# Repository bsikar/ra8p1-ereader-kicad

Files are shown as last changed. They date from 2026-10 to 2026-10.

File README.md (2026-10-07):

# RA8P1 e-reader electronics

Open `ereader/ereader_rev1.kicad_pro` in KiCad 10.0.5 or a compatible newer
version. The project includes its schematic, board, project configuration,
project-local library tables, symbols, footprints, and STEP models. Library
paths resolve relative to the project; standard `Device` and `power` symbols
use the bundled KiCad 10 libraries through `${KICAD10_SYMBOL_DIR}`. No custom
global library installation is needed.

The schematic has a root index and separate processor interface, core-power,
I/O-supply, and clock/reset/debug sheets. The power circuits are drafts with passive qualification
still open; the processor interfaces and remaining subsystems are unfinished.
The PCB is empty.
Neither is a manufacturing release. Imported component models still require
electrical and package qualification before use in a finished design.

## Clone and open

Install Git LFS before cloning, or run `git lfs pull` after cloning. The large
manufacturer reference-design ZIP uses LFS. The editable KiCad project and
component libraries are ordinary Git files. Manufacturer reference files retain
their original notices and are reference material, not this board's design.

Open the project from its checked-out location. Do not add absolute model paths
or depend on a user's global symbol/footprint tables. KiCad lock files, personal
view settings, and editor history are excluded from commits.

## Review and export

`exports/ereader_rev1.pdf` contains every schematic sheet and is refreshed for
each design commit. It represents the design at that commit, including any
explicitly incomplete sections. It is not a fabrication drawing of the PCB.

From the repository root, regenerate it with:

```sh
./scripts/export_design.sh
```

The script also works when called by absolute path from another directory.
It finds `kicad-cli` on PATH or in the standard macOS KiCad app bundle. Set
`KICAD_CLI` to select another executable. An optional schematic path exports
that project's complete hierarchy to `exports/<schematic-name>.pdf`.

The script exports saved files, including all child sheets, and replaces the
previous PDF only after KiCad succeeds and produces a nonempty PDF. It does
not save unsaved editor changes. `--help` shows the available arguments.

Before each commit, save all sheets, export the complete PDF, inspect every
page, and run ERC. During circuit development, record unresolved findings;
do not hide unconnected pins merely to obtain a clean report. Before pushing,
run `python scripts/check_clock_calculations.py`, review the relevant
calculation checks in `design/`, and run `git diff --check`. Follow
`.agents/AGENTS.md` and `LIBRARY_STANDARDS.md`; the former firmware checkout's
parent-relative `CLAUDE.md` is not present in this standalone repository.

## Design references

- [Hardware requirements](design/ereader_requirements.md)
- [Library conventions](LIBRARY_STANDARDS.md)
- [Imported parts inventory](PARTS-CHECKLIST.md)
- [Hardware epic and section issues in YouTrack](https://youtrack.locked.cv/issue/RA8HW-1)

Use YouTrack for current hardware tasks, dependencies, status and review
evidence. The owner migrated and closed the GitHub issues; older issue links
in design records are historical provenance. GitHub remains the Git remote.

The Gaggia controller is a separate future board. Shared components belong in
the functional libraries under `libs/`; board-specific sheets belong in their
own project directory.

## Related repositories

This board is a separate product that uses the same Renesas RA8 part as the
firmware monorepo, so the electronics live here and the software stays there.
Both are wired in as submodules for context:

- `firmware/` -- [bsikar/ra8-firmware](https://github.com/bsikar/ra8-firmware),
  the RA8 firmware monorepo this project was split out of.
- `emulator/` -- [bsikar/ra8-emulator](https://github.com/bsikar/ra8-emulator),
  the host-side RA8 emulator used for EIL runs.

Clone with `git clone --recurse-submodules`, or run
`git submodule update --init --depth 1` in an existing clone. Both submodules
are registered shallow; nothing in this repository builds against them.

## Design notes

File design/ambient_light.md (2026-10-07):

# Ambient-light integration

## ALS-001: native symbol checkpoint, 2026-10-04

Created `Sensors:OPT4001DTSR` through the native Symbol Editor. This initial
symbol-only checkpoint preceded the native circuit integration below.
The existing LIS2DTW12TR orientation circuit is unchanged.
Authority: [TI SBOS993A Rev A, Table 6-2](https://www.ti.com/lit/ds/symlink/opt4001.pdf).

| DTS pin | Name | Electrical type |
| --- | --- | --- |
| 1 | VDD | Power input |
| 2 | ADDR | Input |
| 3 | NC | Unconnected |
| 4 | GND | Power input |
| 5 | SCL | Input |
| 6 | NC | Unconnected |
| 7 | INT | Bidirectional |
| 8 | SDA | Bidirectional |

The eight-pin DTS ordering code is distinct from the four-pin YMN variant.
Pin 7 supports open-drain output and hardware-trigger input. Proposed polling
keeps INT_DIR=1 and a 10k pullup, without allocating another MCU interrupt.
Proposed ADDR-to-ground selects 0x44; local bypass is 100nF.
These are integration decisions pending native wiring and validation.

[DigiKey](https://www.digikey.com/en/products/detail/texas-instruments/OPT4001DTSR/17748298)
showed 346 available in cut tape, USD1.68 at quantity one, unreserved.
Native hidden fields record the exact manufacturer and supplier codes.

Next: connect the common +3V3_MCU rail and IIC0_A bus; reuse the existing
4.7k pullups only after revising the bus inventory. The prior 60pF allocation
is not permission to add sensor capacitance. Bound leakage, edge timing,
startup and shutdown backfeed before acceptance. A 100uA supply planning
allowance is a design reserve, not a guaranteed datasheet maximum.

Use a sealed optical window and isolate the sensor optically from the
frontlight and both camera lights. Window transmission, angular response,
condensation and calibration remain enclosure-dependent qualification work.
No footprint, model, PCB or production acceptance is included.

## ALS-002/003: native integration checkpoint, 2026-10-04

Placed and wired U32 through KiCad. VDD pin 1 uses +3V3_MCU; ADDR pin 2
and GND pin 4 use GND. SCL pin 5 and SDA pin 8 join /SENS_SCL and /SENS_SDA,
respectively, retaining host balls K13 and R16 and the existing R102/R103
4.7k pullups. NC pins 3 and 6 remain unconnected per the device pin map.
No second bus pullup pair was added.

R112 is a 10k YAGEO RC0603FR-0710KL pullup from INT pin 7 to +3V3_MCU.
It follows Table 6-2; polling requires INT_DIR=1, including after register
configuration. No MCU interrupt is allocated. C124 is the 100nF local
VDD-to-GND bypass recommended in section 9.4, with sourced candidate
Murata GRM188R72A104KA35D. Passive source snapshots are inherited dated,
unreserved evidence; recheck before ordering. Effective capacitance,
leakage, temperature, aging and physical placement remain unqualified.

Read-only KiCad XML audit found 299 components. All 296 previous complete
component records and their pin-to-net memberships were preserved against
the service-discharge checkpoint. The three additions are U32, C124 and
R112. Native ERC remains 100 errors and 11 warnings; this is a WIP result,
not electrical acceptance or a clean ERC claim.

### Expanded shared-bus allocation fails the existing Fast-mode screen

`scripts/check_ambient_light.py` audits the exported topology and reproduces
the following conditional arithmetic. These are engineering allocations,
not measured or guaranteed installed limits:

- Existing 60pF ceiling plus provisional 10pF sensor/route reserve = 70pF.
  TI's 3pF typical pin capacitance is not a guaranteed maximum.
- Existing 15uA leakage allocation plus provisional 2uA reserve = 17uA.
  This is not a full-temperature OPT4001 leakage guarantee.
- Existing R102/R103 envelope: 4376.147..5034.194 ohm, including allocated
  tolerance, temperature and service drift; rail 3.151819680..3.393012496V.
- Worst allocated rise: 318.072781ns, failing the 300ns ceiling. At 17uA,
  the corresponding capacitance ceiling is 66.022625pF.
- With 1.3us low, 0.6us high and 300ns allocated fall, 400kHz period slack
  is -18.072781ns. Bus divider/filter settings are not accepted.
- Conditional static high floor is 3.066238391V and sink ceiling is
  0.792343mA. R112's hypothetical INT-low draw is 0.346190mA and resistor
  dissipation is 1.174628mW using 1% tolerance plus 1% temperature reserve.

Next: revise the complete bus capacitance/leakage inventory and pullup/timing
choice, then qualify host and both sensor thresholds, edges, startup,
shutdown/backfeed and power-cycle behavior together. The added device does
not inherit the prior 60pF approval. The 100uA ALS supply planning reserve
also does not establish maximum supply current or aggregate rail capacity.

## ALS-004: complete saved-bus inventory and pullup comparison, 2026-10-04

The read-only exported netlist contains exactly four contacts on each line:
SCL = R102.2, U1.K13, U26.1 and U32.5; SDA = R103.2, U1.R16,
U26.4 and U32.8. Both pullups return to +3V3_MCU. U26 is the approved
LIS2DTW12TR. The audit now asserts these complete contact sets, the retained
4.7k values and the replacement part number. Adding another bus load will
require revising this inventory and the conditional allocation.

Compared lower nominal pullups using the same 1% initial, 1% temperature
and 5% service-drift allocations. Slow edges use 70pF, 17uA leakage sinking
and the minimum rail; fast edges use 25pF, 17uA injection and the maximum
rail. These allocations remain unqualified. The timing screen follows
[RA8P1 Rev.1.30 Table 2.66](https://www.renesas.com/en/document/dst/ra8p1-group-datasheet)
and [OPT4001 SBOS993A](https://www.ti.com/lit/ds/symlink/opt4001.pdf).

| Uninstalled nominal pullup | Conditional rise range | Sink ceiling | 400kHz period slack |
| --- | --- | --- | --- |
| 3.9k | 73.904..261.023ns | 0.951387mA | 38.977ns |
| 3.3k | 62.912..219.056ns | 1.121276mA | 80.944ns |
| 2.7k | 51.788..177.773ns | 1.366670mA | 122.227ns |
| 2.2k | 42.413..143.880ns | 1.673414mA | 156.120ns |

3.3k is the next candidate for sourcing and native installation: it provides
more conditional margin than 3.9k while retaining lower sink current than
2.7k or 2.2k. No pullup was changed in this checkpoint. The table is a
lumped planning comparison, not permission to operate the current circuit
at 400kHz. Divider/filter settings, fall time, full-temperature device limits,
actual board capacitance, supply sequencing and future bus loads still need
qualification. Preserve the failed installed 4.7k screen until native
replacement and its saved-netlist verification are complete.

## ALS-005: native 3.3k shared-bus pullups, 2026-10-04

Changed R102/R103 in native KiCad to YAGEO RC0603FR-073K3L, 3.3k,
1%, +/-100ppm/C, 0603, 0.1W at 70C, -55..155C. The
[manufacturer ordering-code sheet](https://yageogroup.com/component-documentation/download/specsheet/RC0603FR-073K3L)
confirms these ratings. Native fields include the exact MPN, manufacturer
document, supplier code/URL, selection basis and dated availability snapshot.
[DigiKey](https://www.digikey.com/en/products/detail/yageo/RC0603FR-073K3L/730073)
showed Active status, 622,536 unreserved in stock, cut-tape code
311-3.30KHRCT-ND, USD0.10 qty1 / 0.01220 qty100 and a 22-week
manufacturer lead time. Recheck before ordering. Footprints remain deferred.

Under the ALS-004 allocations, the installed pair has a resistance envelope
of 3072.6135..3534.6465 ohm. Conditional rise is 62.912..219.056ns,
sink ceiling 1.121276mA, and the minimum-pulse 400kHz period screen has
80.944ns slack. This closes the failed *planning calculation* for the
previous 4.7k pair; it does not qualify operation at 400kHz. The script
retains that historical 318.072781ns failure separately.

The complete saved bus inventory remains the exact ALS-004 contact sets.
Read-only comparison against the 299-component ALS checkpoint permits
only R102/R103 value and source-metadata changes, preserving their other
identity fields, all 297 other complete component records and every contact
membership. The native circuit and both notes now show the installed values.
No new components or wires were added by this pullup checkpoint.

Remaining acceptance work: bound installed capacitance and leakage across
temperature and service conditions; verify RA8P1 IIC clock/divider/filter
timing and both sensors' edge/threshold limits; evaluate startup, supply
collapse, backfeed and recovery. OPT4001 optical-window transmission,
frontlight/camera-light isolation, condensation and calibration remain open.
The resistor environmental rating does not qualify enclosure water resistance.

Verification: both sensor calculation/topology scripts pass against the saved
XML; the native ERC findings are identical to ALS-003 (100 errors, 11 warnings).
The full 14-page PDF was refreshed: pages 1-13 are pixel-identical to the
preceding reviewed export, and page 14 was rendered and inspected for the
new values and notes. Native CLI BOM export retains the project-configured
19 columns and has 121 groups / 296 included references; TP1-TP3 remain
explicitly excluded copper testpoints. All included values, manufacturer
names/MPNs and DigiKey codes match the saved XML. Clock calculation checks
and `git diff --check` pass. This remains a WIP electrical design.

## ALS-006: host divider and recovery screen, 2026-10-04

Reviewed [RA8P1 HUM R01UH1064EJ0130 Rev1.30](https://www.renesas.com/en/document/mah/ra8p1-group-users-manual-hardware),
chapter 40. Pages 2384 and 2386 define IICphi = PCLKB / 2^CKS and
NF=01 as two filter stages. Page 2402 equation (5) applies with SCLE=1,
NFE=1 and nonzero CKS. BRH/BRL must each be at least nf+1; reserved
register bits 7:5 must be written as ones. Keep FMPE=0 for Fast-mode.

`scripts/check_sensor_iic_clock.py` screens a provisional PCLKB=50MHz
+/-1% allocation with CKS=001, NF=01, BRH=23 and BRL=31 (register
writes 0xF7 and 0xFF). These are candidate settings, not firmware changes
or an approved system clock configuration. The current crystal circuit
does not establish this PCLKB range. The script computes high/low pulse
minima and maximum rate with zero fall time as a conservative rate bound;
zero fall time is not an accepted electrical edge. It also demonstrates
why the manual's illustrative 400kbps tuple is not a corner-qualified
setting for this bus. Stretching can further reduce the transfer rate.

Recovery must respect sections 40.12.2-40.12.3, pages 2448-2449. CLO
outputs one extra SCL cycle per request and must clear before another
request. Use it only for lost synchronization, monitor SDAI, and issue
STOP after the slave releases SDA. CLO cannot recover a slave holding
SCL low. Both module reset forms release the MCU outputs; neither proves
that a sensor has reset or released its own output. Clear IICRST afterward.
The whole-bus power-cycle/discharge path remains an electrical dependency.

Still open: derive PCLKB and its tolerance from the complete PLL/clock
plan, verify sensor and host setup/hold plus START/STOP and bus-free timing,
select SDA delay from guaranteed limits, bound physical edges/leakage,
and qualify interrupted-transfer recovery. Do not mark ALS or U26 fully
qualified from this divider screen. No schematic, BOM or firmware changed
in ALS-006; the existing full PDF remains the current circuit view.

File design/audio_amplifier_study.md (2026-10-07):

# Audio Stage 3: headphone amplifier alternatives and qualification envelope

2026-10-04 research checkpoint. **No amplifier topology or part is selected.**
This is a feasibility/architecture study following
[Stage 1](audio_stage1_requirements.md), not a circuit qualification or a
continuous output rating. No schematic, library, BOM, footprint or PDF changes
are made by this document. Existing OPA1622/INA1620 ideas and U34/K1 are WIP.
Firmware implementation is out of scope; hardware must provide the interfaces,
independent protection and deterministic mode-transition contracts.

The meaningful shortlist is (1) a precision amplifier with multiple integrated
buffers inside its feedback loop, (2) a precision amplifier with a discrete
Class-AB output stage, and (3) separate low-power IEM and high-current desktop
paths. A high-current current-feedback IC is another serious desktop comparator.
Class A and local error correction deserve evaluation but are not automatically
better. Stage 6 must compare these with the converter, power and enclosure study
before any final CAD changes.

## Electrical envelope and actual headphone cases

Screen balanced desktop output at **16 Vrms maximum, 0.707 Apeak maximum and
4 W/channel continuous maximum**, with 2 W/32 as the minimum architecture
objective. These are simultaneous limits, not three independent product claims.
Use `V = min(16, R*0.70710678/sqrt(2), sqrt(4*R))` and then apply actual hot
output swing, SOA, protection and thermal limits. Both legs carry full load
current and each sees an effective load of R/2 in symmetric BTL operation.

| Load ohms | Available Vrms | W/channel | Apeak | Ideal stereo heat on fixed +/-14 V rails, W | Maximum ideal heat over allowed amplitude, W |
| ---: | ---: | ---: | ---: | ---: | ---: |
| 16 | 8.000 | 4.000 | 0.707 | 17.209 | 17.209 |
| 32 | 11.314 | 4.000 | 0.500 | 9.825 | 9.825 |
| 50 | 14.142 | 4.000 | 0.400 | 6.260 | 6.355 |
| 80 | 16.000 | 3.200 | 0.283 | 3.684 | 3.972 |
| 150 | 16.000 | 1.707 | 0.151 | 1.965 | 2.118 |
| 300 | 16.000 | 0.853 | 0.075 | 0.982 | 1.059 |
| 600 | 16.000 | 0.427 | 0.038 | 0.491 | 0.530 |

Heat uses ideal Class B, `Pdc/ch = 4*Vrail*Ipeak/pi`; output-stage stereo
heat is `2*(Pdc/ch-Pload/ch)`. Bias, converter loss, DAC, drivers, host/radio,
display and charging add heat. At 50 ohms and above, the dissipation maximum
occurs at 12.604 Vrms on +/-14 V, below the endpoint. A thermal test only at
clipping misses it. This table demonstrates that a fixed high-voltage rail is
an unattractive low-impedance operating mode, even when current capability is
ample. At the same 4 W/16, +/-8 V gives 6.405 W ideal stereo output-stage heat;
it is an illustrative lower-rail comparator, not proved 0.707 A hot swing.
For 16 Vrms BTL, each leg must swing 11.314 Vpeak. +/-14 V leaves 2.686 V
for stage/protection headroom before supply tolerance/droop. A device that
needs more headroom cannot meet it on these rails.

Lower-power IEM qualification extends to 8-9 ohms. Applying the desktop
current ceiling blindly to 9 ohms would produce 2.25 W/channel and 20.709 W
ideal stereo heat on +/-14 V: explicitly prohibit this in IEM mode. Rated
IEM voltage/current limits need independent hardware enforcement and must be
far below the high-power path. The 4 W cap also needs a real implementation:
an RMS/thermal limiter, load-aware voltage ceilings, or a conservatively rated
fixed envelope. Voltage and instantaneous current limits alone do not enforce
constant continuous power at every impedance.

Use equivalent sine peak-capacity screens of 100 dB, 105 dB, and 111 dB
(105 plus 6 dB EQ/sensitivity reserve), not recommended sustained listening
levels. Conversion from voltage sensitivity is `V=10^((L-Sv)/20)`; from
power sensitivity `P[mW]=10^((L-SmW)/10)`. Music crest factor, acoustic seal,
sample variation and frequency-dependent EQ prevent an SPL guarantee.

| Headphone and basis | 100 dB: Vrms / W | 105 dB: Vrms / W | 111 dB: Vrms / W / Apeak |
| --- | ---: | ---: | ---: |
| Original HE-6, velour pads, RAA conservative left-channel band average 89.0 dB/V, 43.3 ohms | 3.548 / 0.291 | 6.310 / 0.919 | 12.589 / 3.660 / 0.411 |
| Original Susvara, Stage 1 conservative measured screen 93.2 dB/V, 67.1 ohms | 2.188 / 0.0713 | 3.890 / 0.226 | 7.762 / 0.898 / 0.164 |
| HD800S, manufacturer 102 dB/V, 300 ohms | 0.794 / 0.00210 | 1.413 / 0.00665 | 2.818 / 0.0265 / 0.0133 |
| Original LCD-5, manufacturer 90 dB/mW, 14 ohms | 0.374 / 0.0100 | 0.665 / 0.0316 | 1.328 / 0.126 / 0.134 |
| SE846, manufacturer 114 dB/mW, 9 ohms | 0.0189 / 0.0000398 | 0.0337 / 0.000126 | 0.0672 / 0.000501 / 0.0106 |

The [original RAA HE-6 measurement](https://reference-audio-analyzer.pro/en/report/hp/hifiman-he-6.php)
identifies velour pads, HDM1/SF1 fixtures and channel-specific values. It is
**not HE6se or HE6se V2** and should not be relabeled as either. Using the less
sensitive channel is our conservative screen. The HE-6 case supports useful
margin beyond 8 Vrms: an 8 V ceiling misses the 111 dB reserve screen by about
3.94 dB. The 16 V /4 W envelope permits about 13.161 V at 43.3 ohms, providing
only about 0.39 dB beyond that reserve screen. It is broad coverage, not an
unlimited future-load promise. Additional EQ or low-frequency sensitivity
uncertainty can consume the reserve; qualification must use impedance curves
and frequency-specific measured sensitivity.

Other sources: [Susvara original RAA measurement](https://reference-audio-analyzer.pro/en/report/hp/hifiman-susvara.php),
[HD800S manufacturer specification](https://support.sennheiser-hearing.com/hc/en-us/articles/38273432554141-HD-800S-Specifications),
[LCD-5 manufacturer](https://www.audeze.com/products/lcd-5),
[SE846 manufacturer](https://www.shure.com/ja-jp/insights/all-about-se846-gen2-a-more-sophisticated-listening-experience).
Susvara/HD800S/SE846 inputs preserve Stage 1 provenance; this pass adds the
HE-6 measurement and original LCD-5 example. The LCD-5 source now describes
that model as legacy; future LCD variants must not inherit its electrical
specification. Electrostatic energizers and unusual near-zero-ohm ribbons
remain outside this conventional voltage-output headphone design.

## Serious amplifier comparators

Values below are manufacturer data under their stated conditions, not
complete-device measurements. A typical current, short-circuit rating, or
25 C waveform must never be treated as guaranteed low-distortion hot current.

| Candidate / function | Relevant source data | Fit and unresolved limits |
| --- | --- | --- |
| OPA1622 integrated audio driver | +/-2 to +/-18 V; 2.6 mA/core typical; 2.8 nV/sqrtHz at 1 kHz; +145/-130 mA typical drive/short-current scale; shutdown with reduced transients. | Strong low-power/IEM comparator, current alone inadequate for desktop. Input/feedback noise and hot swing still matter. |
| INA1620 integrated audio driver/resistor network | Same supply range and 2.6 mA/core typical; table labels +145/-130 mA **short-circuit** current. Matched resistors/EMI filtering add utility, not output watts. | Rail rating is not the blocker. Bare output paralleling is unacceptable; offset, sharing, stability and thermal limits require design. |
| OPA1656 + BUF634A composite | Actual manufacturer headphone reference; BUF634A +/-2.25 to +/-18 V, +/-250 mA continuous parameter; 1.5/8.5 mA typical low/wide-bandwidth bias. | Real scalable comparator; one buffer/leg cannot supply 0.354/0.5/0.707 Apeak. Parallel buffers and compensation must be proven. |
| Precision amplifier + LME49600 | Manufacturer closed-loop reference; 250 mA typical, 7.3/13.2 mA bias; +/-18 V ceiling. | Similar current-scaling issue and larger TO-263 footprint; higher idle burden than BUF634A comparator. |
| Precision amplifier + LMH6321 | 300 mA continuous subject to heat, programmable limit 10-300 mA, 11 mA typical bias, operating ceiling +/-16 V. | Useful current-limited composite comparator; needs multiple buffers for desktop. At +/-15 V, 300 mA sinking swing is only -10.3 V minimum at 25 C/-9.8 V hot, insufficient alone for 11.314 Vpeak per leg. |
| TPA6120A2 integrated current-feedback AB | +/-5 to +/-15 V recommended; 700 mA typical; 16 ohm recommended minimum load; 15 mA/core at +/-15 V; 10-100 ohm output resistor recommended. | Native reference conflicts with low output impedance. In BTL, 16 ohm headphones impose 8 ohm per leg, below recommended load. Needs new compensated implementation, thermal and noise evidence. |
| Precision amplifier + ADA4870 high-current CFB | 10-40 V supply, 1 A typical drive, 32.5 mA typical bias at +/-20 V; manufacturer composite example with ADA4637-1. | Serious desktop option with useful SOA documentation. Large idle burden, high input current noise, offset and loop compensation preclude adopting it as an IEM driver from its spot voltage-noise number. |
| OPA564 power amplifier/composite candidate | 7-24 V supply, 1.5 A, 39 mA typical bias; 102.8 nV/sqrtHz at 1 kHz; adjustable limit and thermal flag. | Direct IEM use is poor; +/-12 V ceiling gives too little guaranteed headroom for 16 Vrms BTL. A precision outer loop adds work and heat; not a leading portable comparator. |
| Precision amplifier + discrete AB emitter/source followers | Bias, transistor area and heatsinking can be chosen independently of signal gain. | Serious flexible option; must establish bias tracking, hot DC/pulsed SOA, second breakdown for BJTs, MOSFET linear-mode suitability, loop stability and manufacturing variation. More parts are justified only by measured envelope/energy benefit. |

Sources: [OPA1622 Rev B](https://www.ti.com/lit/ds/symlink/opa1622.pdf),
[INA1620 Rev B](https://www.ti.com/lit/ds/symlink/ina1620.pdf),
[OPA1656 composite, section 8.2.2](https://www.ti.com/lit/ds/symlink/opa1656.pdf),
[BUF634A Rev F](https://www.ti.com/lit/ds/symlink/buf634a.pdf),
[LME49600 Rev E](https://www.ti.com/lit/ds/symlink/lme49600.pdf),
[LMH6321 Rev D](https://www.ti.com/lit/ds/symlink/lmh6321.pdf),
[TPA6120A2 Rev B](https://www.ti.com/lit/ds/symlink/tpa6120a2.pdf),
[ADA4870 Rev C](https://www.analog.com/media/en/technical-documentation/data-sheets/ada4870.pdf),
[OPA564 Rev E](https://www.ti.com/lit/ds/symlink/opa564.pdf).

At an optimistic 130 mApeak per leg, a BTL OPA1622/INA1620 channel has only
`Ipeak^2*32/2 = 0.270 W/32`. Even this is a calculation using typical limiter
scale, not a linear rating. Raising its rails does not solve current limits.
An illustrative six cores/leg would have 24 cores and substantial sharing,
noise, power and failure complexity. This is not a recommended six-core design.

The BUF634A composite reference uses the buffer in the OPA165x feedback loop;
wide-bandwidth mode is the reference condition for uncomplicated stability.
Changing to low-bias mode, adding buffers or switching gain invalidates an
assumption that that single-buffer reference proves our loop. Three buffers
per leg share 0.707 A as 0.236 A each ideally, leaving little sharing margin.
Twelve wide-mode buffers plus four OPA1656 cores on +/-14 V consume an
illustrative 3.293 W idle using typical currents, before the DAC. Low-bias
operation and/or power-gating a separate desktop bank therefore deserve
explicit comparison; no low-bias loop is qualified here. The
[BUF634A EVM schematics](https://www.ti.com/lit/pdf/SBOU256) provide a test
starting point, not a production solution; their default 50-ohm termination
must not be copied as a headphone source impedance.

Current-sharing ballast resistors, individual offsets and gain error must
be modeled. Never connect independently controlled outputs together simply
because they have the same nominal gain. A common precision loop around a
buffer bank with local ballast is distinct from independent amplifiers
fighting at a common output node. The summed current limit does not protect
one overloaded buffer if sharing is unequal or one device loses a rail.

Current-feedback describes an internal feedback topology, not a mandate to
drive headphones from a high-impedance current source. A conventional voltage
output with low impedance remains the required interface. The TPA6120A2
reference imposes specific feedback-resistor/stability constraints; reducing
its output resistor to meet our impedance budget needs simulation and bench
evidence. Its typical 0.9 uVrms output-noise headline is not a measured
20 Hz-20 kHz two-leg noise budget for our design.

ADA4870 supplies a precision-composite reference and SOA curves for a particular
board/heatsink at 25/85 C. Neither 1 A nor its 2.1 nV/sqrtHz voltage noise
at 100 kHz is a complete audio-band result. Four devices at +/-14 V using
32.5 mA as an illustrative bias consume 3.64 W idle; actual bias at those rails
needs measurement. Its inverting-input current noise and feedback resistors
matter. OPA564's guaranteed current/headroom, limiter overshoot and hot-current
derating also need examination if reconsidered; thermal shutdown is not an
acceptable normal operating cycle.

For discrete AB, [LT1166 manufacturer bias-system circuits](https://www.analog.com/media/en/technical-documentation/data-sheets/1166fa.pdf)
are one reproducible comparator: sense resistors set bias and current limit,
while an explicit compensated local loop controls external devices. This
does not establish IEM noise or eliminate hot SOA checks. Small sense resistors
reduce impedance but make current-limit/bias accuracy and layout important.
Generic switching MOSFET drain-current ratings do not establish linear SOA.
No output transistor has been selected.

Class A can avoid a crossover transition in its valid load/bias region; this
does not guarantee less total audible distortion than well-designed AB. The
Stage 1 illustrative four-leg 0.25 A bias on +/-10 V is 20 W idle, incompatible
with our portable energy allocation. Lower bias reduces the Class-A envelope.
Reject continuous high-power Class A as the default portable path unless a
quantified benefit outweighs that burden; an AB stage may remain Class A for
small signals without paying full-load Class-A idle power.

Implementable local error correction is a serious option.
[Cordell's original AES paper and circuit](https://www.cordellaudio.com/papers/MOSFET_Power_Amp.pdf)
demonstrate corrected output-stage distortion in a 50 W speaker amplifier.
The paper does not qualify a modern low-voltage headphone circuit. Its local
error/bias loop and main feedback loop require compensation, clipping recovery,
noise and hot stability analysis after rescaling. Composite global feedback
is another real way to reduce output-stage errors. Do not equate either with
a licensed THX design. [THX's primary description](https://www.thx.com/aaa)
identifies proprietary patented feed-forward technology; it provides no
qualified custom-board schematic in this study.
[Questyle's technology page](https://www.questyle.com/pages/technology)
is product/technology context, not a reproducible output-stage reference.
Neither brand proves an audible benefit over a transparent tested AB circuit.

## Noise, gain, volume, balanced and single-ended interfaces

The Stage 1 <=1 uVrms unweighted 20 Hz-20 kHz jack-noise objective corresponds
to 94 dB SNR at 50 mVrms; 0.5 uV gives 100 dB. Include DAC, I/V/filter,
attenuator, resistor Johnson noise, amplifier voltage/current noise, supplies,
switch leakage and RF demodulation. Measure active digital zeros, mute,
USB+PD+charging and Wi-Fi activity separately. A-weighted and unloaded SINAD
cannot substitute for this loaded low-level measurement.

Our flat-noise approximation with 2.8 nV/sqrtHz and two independent BTL legs
gives 0.560 uVrms at noise gain 1, 1.119 uV at 2 and 2.239 uV at 4, before
all other stages and 1/f noise. These are calculations, not device noise
guarantees. High gain can fail the IEM noise budget even with an excellent
amplifier. An inverting unity-signal-gain leg has noise gain 2; two unity-gain
voltage followers fed from a differential source have a different noise
budget. Do not sum all upstream noise as independent: some is correlated
between legs, and actual differential transfer determines cancellation.

Retain these candidates through Stage 6:

1. One scalable output stage, low/medium/high closed-loop gain and lower rails
   on battery; power-gated extra buffers in desktop mode. Advantage: fewer
   connector-routing stages. Risks: gain/buffer switches, compensation changes,
   leakage into disabled outputs, hot current sharing and high idle noise.
2. Optimized IEM stage plus separate high-power AB/composite path, both routed
   through qualified default-open disconnects. Advantage: high-current stage
   can be fully off for IEM listening. Risks: board area, selection contact
   resistance, charge injection, pop behavior and cross-path fault backfeed.
3. Shared precision front end, dedicated SE and four-leg balanced power stages,
   with explicit power-gating and independent protection. Advantage: both jack
   interfaces can have independent useful capability. Risks: greatest area and
   supply/control complexity; do not assume simultaneous outputs.

Use coarse analog gain/attenuation plus fine digital volume as a comparator.
An analog attenuator before the final amplifier reduces upstream noise but
does not reduce that amplifier's own noise. Large output-divider resistors
raise source impedance and make response dependent on IEM impedance. A
mechanical potentiometer's low-end matching is not assumed. Relay/resistor or
IC volume must prove <=0.1 dB channel error at 1-50 mV, transitions and contact
aging. Fail-open/stuck control states must not enable maximum gain.

A differential converter can feed a differential chain, but the SE interface
needs a defined derivation. One balanced leg gives half voltage and quarter
power at the same R only within its current/SOA limits. A differential-to-SE
stage followed by a dedicated amplifier is an alternative. Never short an
active negative leg to ground. A common-ground 3.5 mm return needs separate
high-current routing to avoid crosstalk; four output conductors remove that
shared cable return. Proper 2 V SE/4 V differential line outputs should have
their own buffer/level contract. Reusing a power stage requires line-load,
noise, stability and fixed-line/inserted-IEM mode-fault evidence.

## Hardware protection and continuous thermal qualification

Required hardware fault contract, to be closed before integration:

- Outputs default disconnected when unpowered, during reset and when logic
  control floats. Separate hardware healthy conditions must override MCU
  enable: all rails valid, no latched fault, safe temperature and DC state.
- Detect both differential DC and each conductor's DC relative to ground.
  Common-mode faults may cancel across a balanced transducer but remain
  hazardous during jack insertion or grounded adapter use. Monitor SE signals
  independently. Provide a fault latch and deliberate muted recovery.
- DC detection must reject normal 20 Hz bass without an excessive fault delay.
  Set threshold/filter/latency using permitted fault energy, not firmware
  convenience. Rail-loss and short/overcurrent paths need separate fast
  detection; a slow DC filter cannot serve every fault. Illustratively a
  14 V DC fault into 9 ohms for 5 ms delivers 0.109 J. This calculation does
  not assert that 5 ms is safe or that a selected relay can achieve it.
- Disconnect all four balanced output conductors and both SE signals. Check
  relay DC interruption/current rating, hot contact resistance/lifetime and
  coil release delay. A flyback diode can slow release; a clamp alternative
  must be designed from coil and transistor limits. Back-to-back MOSFET
  switches have their own distortion, Rds(on), SOA and fail-short fault model.
  K1's symbol or existing unfinished driver is not a safety qualification.
  Keep feedback defined while contacts are open: sensing only after a relay
  can leave a loop open and saturate the amplifier before reconnection. A DC
  servo may reduce normal offset but cannot replace independent fault removal.
- Current limits must include tolerance, short recovery and independent-leg
  faults, not just nominal sine current. Qualify cable shorts, mono/TRRS plugs,
  partial insertion, negative-to-ground adapter misuse, a grounded powered
  speaker input and hot-plug ESD. Device HBM ratings are not jack ESD ratings.
- Characterize input present with rails off, one rail absent, power loss,
  converter overshoot and output back-driving. Prevent inputs powering an
  inactive amplifier through clamps. Reference enable/flag levels to their
  actual supply domain; ground-referenced GPIO cannot be assumed compatible
  with negative-rail-referenced control pins.
- Mute and open disconnect before planned gain/rail/path changes; enable only
  after rail/offset settling. Forced PD loss must use an independent rail-good
  path and enough hold-up/release margin. Measure pops as voltage waveform and
  delivered load energy. Normal thermal operation must stay below shutdown,
  with battery and enclosure limits tighter than silicon survival limits.

Run both channels at loads 8/9/14/16/32/50/80/150/300/600 ohms, cable
capacitances and representative measured impedance curves. Determine steady
state (>=60 minutes and thermal equilibrium) at 25/35 C screens, both clipping
and maximum-dissipation amplitudes, charge on/off and weak/strong PD sources.
For each report rail ripple/droop, converter current, per-device temperature,
enclosure/battery temperature, limiting behavior, loaded THD+N and output
impedance over frequency. Steady-state thermal interfaces and sealed enclosure
area remain mechanical gates. No amp IC or reference board can waive them.

Independent original laboratory evidence:
[L7's Topping A90 report](https://www.l7audiolab.com/f/measurement-of-topping-a90-headphone-amp/)
describes measured 4.3 W/50 ohm balanced and 0.98 W/300 ohm balanced sweeps,
plus a 6.5 W/33 ohm balanced dashboard point with 110 dB SINAD; overload
protection interrupted output during testing. These are original electrical
measurements, not published hour-long enclosure thermal ratings. They show
that multiwatt low-distortion output is practical and protection behavior
affects power measurement; they do not prove our portable enclosure, topology
or 50 mV noise performance. Neither manufacturer headlines nor a short lab
sweep constitutes our continuous rating.

## Sourcing status and next decision gate

This is a candidate study, so no procurement or final BOM selection is implied.
Snapshot retrieved 2026-10-04; inventory is unreserved and may be cached:

| Candidate | Lifecycle evidence | Price/availability evidence and limitation |
| --- | --- | --- |
| OPA1622IDRCR | [TI ACTIVE](https://www.ti.com/product/OPA1622) | [DigiKey](https://www.digikey.com/en/products/detail/texas-instruments/OPA1622IDRCR/6553919): 4264 displayed, $7.43 quantity 1, $4.8432 quantity 100, cut tape; 20-week standard lead time displayed. Recheck exact suffix before purchase. |
| OPA1656 | [TI ACTIVE](https://www.ti.com/product/OPA1656) | OPA1656IDR shown as $2.99 related product on the same distributor page; exact stock/quantity quote not verified. |
| BUF634A | [TI ACTIVE](https://www.ti.com/product/BUF634A) | [Mouser BUF634AIDDAR](https://www.mouser.com/ProductDetail/Texas-Instruments/BUF634AIDDAR?qs=yqaQSyyJnNgwK76xZ3uCIA%3D%3D) search snapshot showed 635 and cut-tape option; price/full direct page could not be read reliably. Not a firm sourcing qualification. |
| LME49600, LMH6321, TPA6120A2, INA1620, OPA564 | Current TI pages ACTIVE | Exact suffix, small-quantity stock and unit quote pending; old datasheet date is not itself obsolescence. |
| ADA4870 | [ADI recommended for new designs](https://www.analog.com/en/products/ada4870.html) | Manufacturer 1ku starting list $12.66; not a one-unit distributor quote or stock commitment. |
| LT1166 | [ADI production](https://www.analog.com/en/products/lt1166.html) | Manufacturer 1ku starting list $3.39; external driver/output devices and precise small-quantity availability not selected. |

Stage 6 must compare measured/simulated IEM noise, loaded stability, low-level
matching, hot SOA, portable idle power, full-system heat, sourcing and complexity
for the three serious paths above. No final topology follows from this study.
If a common stage cannot meet the portable energy/noise allocations with a
stable low-power mode, the separate IEM/high-power path becomes substantially
more attractive despite extra area. If a discrete composite cannot outperform
an integrated buffer bank in the required envelope at defensible complexity,
the extra discrete circuitry is not justified by price or brand language.

Reproduce arithmetic with `python scripts/check_audio_amp_envelope.py`. It
checks the power cap, current/voltage envelope, independent heat-maximum sweep,
headphone screens and example idle/noise/fault-energy budgets. It is not SPICE,
a bench test, fault safety approval or evidence of production capability.

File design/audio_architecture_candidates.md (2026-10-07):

# Audio architecture study: Stage 2 conversion and analog alternatives

2026-10-04. Research checkpoint; **no architecture or component is selected**.

This record applies the owner-approved scope in
[Stage 1](audio_stage1_requirements.md): own-server streaming, hardware work,
quiet IEMs, conventional demanding headphones, 3.5 mm SE / 4.4 mm balanced,
proper line output, and portable plus USB-PD desktop operation. All existing
e-reader/camera/illumination/speaker/wet-port requirements remain. Initial
10-hour local / 8-hour streaming allocations mean that audio idle consumption
matters even when headphone output is only milliwatts. The 2 W/32-ohm floor,
4 W stretch, current/power limits, and possible 16 Vrms high-impedance mode
are amplifier requirements; none requires a particular DAC brand.

Detailed CAD remains behind the Stage 6 selection gate. This document makes
no schematic/library/BOM changes and does not qualify existing U34/K1.
Stage 3 owns the final amplifier comparison; Stage 5 owns the power tree.

## 1. Evidence and comparison discipline

DAC DNR, SNR and THD+N below are manufacturer typical claims under their
specified conditions, not complete-player measurements. Different output
levels, weighting, bandwidths and reference circuits prevent a direct
leaderboard. Minimum/maximum limits must replace typical values at component
qualification. Mono summing can improve uncorrelated noise by approximately
3 dB but doubles converter resources; it does not automatically remove
correlated reference or digital noise, distortion or headphone-amplifier hiss.

| Family screened | Useful evidence | Consequence for this product |
| --- | --- | --- |
| ESS ES9039Q2M | Current public v0.2.3, differential outputs, 130 dBA DNR, -120 dB THD+N at 48 kHz on a **10 Vrms evaluation output**; 54/64/78 mW typical active power in the documented clock modes. | Strong portable conversion candidate. The 10 V reference result is not a promise of -120 dB at 2 V or at the headphone jack. Current/voltage-mode possibilities need an explicit front-end comparison. |
| AKM AK4497S | Differential voltage output; 129 dB SNR / -117 dB THD+N at 2 Vrms; 131 dB / -113 dB at 2.7 Vrms. | Serious current-generation alternative with less external I/V work, but increasing output does not improve every performance metric. |
| AKM AK4499EX + AK4191 | Separated digital modulator and switched-resistor analog DAC; 135 dBA stereo / -124 dB THD+N under its documented reference conditions. | Serious maximum-performance comparator with extra chips, reference load and I/V work. It is a noise-shaped multibit architecture, not a conventional NOS binary ladder. |
| Cirrus CS43198 | Pseudodifferential voltage outputs, 130 dBA / 127 dB unweighted DNR, -115 dB typical PCM THD+N, 0.55 uVrms A-weighted idle noise under its table conditions. | Serious low-power comparator; balanced-at-conversion needs more than one stereo chip or a downstream phase splitter. |
| TI PCM1792A | Advanced Segment differential current output; 127 dB stereo DNR at 2 V, 129 dB at 4.5 V; 0.0004% THD+N. | Mature, documented 192 kHz alternative; do not confuse its 132 dB high-voltage mono condition with normal stereo performance. |
| ADI AD1955 | Multibit delta-sigma, differential current output; 120 dBA stereo DNR, -110 dB THD+N; production status. | A viable mature baseline, not evidence of a performance/power advantage over the newer parts. |
| TI DAC11001B | Precision 20-bit R-2R, external bipolar reference/buffer, SPI rather than native I2S. | A reproducible ladder comparator exists; the conversion interface, reference, filtering and dynamic settling are substantial system work. |

Sources: [ESS current DAC lineup](https://www.esstech.com/products-overview/digital-to-analog-converters/sabre-audiophile-dacs/),
[ES9039Q2M v0.2.3 datasheet](https://www.esstech.com/wp-content/uploads/2026/05/ES9039Q2M_Datasheet_v0.2.3.pdf),
[AK4497S product](https://www.akm.com/us/en/products/audio/audio-dac/ak4497svq/),
[AK4499EX datasheet](https://www.akm.com/content/dam/documents/products/audio/audio-dac/ak4499exeq/ak4499exeq-en-datasheet-myakm.pdf),
[CS43198 datasheet](https://statics.cirrus.com/pubs/proDatasheet/CS43198_DS1156F2.pdf),
[PCM1792A product](https://www.ti.com/product/PCM1792A),
[AD1955 product](https://www.analog.com/en/products/ad1955.html),
[DAC11001B datasheet](https://www.ti.com/lit/ds/symlink/dac11001b.pdf).

These sources establish candidate plausibility, not an audible brand
signature. No evidence reviewed establishes that matched linear DACs with
equivalent filtering, levels and noise have an inherent ESS/AKM/Cirrus/ladder
sound. A sonic claim needs controlled level-matched listening evidence;
electrical faults, response differences and hiss remain testable engineering
differences.

## 2. Four serious conversion-to-output architectures

The branches below share the same RA8P1/C6 hardware study and asynchronous
USB clock-domain contract. A separate USB bridge remains a Stage 4 option.
All require independent hardware mute/DC/overcurrent/thermal protection,
clock/rail-loss handling, source/gain detection and a fail-safe connector
mode interlock. Line buffers branch before the power headphone amplifier.
Do not connect a balanced negative conductor to ground for SE or line use.

### A. Low-power ESS differential current-conversion path

`Audio clock domain -> one ES9039Q2M -> four low-noise I/V cells ->`
`differential reconstruction/filter -> matched analog gain/attenuation ->`
`four power-amplifier legs -> four-pole disconnect -> 4.4 mm`.

A parallel high-impedance branch feeds dedicated balanced line buffers at
4 Vrms differential. A precision differential-to-SE stage supplies 2 Vrms
line and a separate low-noise SE/IEM headphone stage. Simultaneous use stays
conditional on loading, power and safe mode control; nothing connects a
power output directly to a ground-referenced line input.

The I/V option keeps DAC output nodes near an appropriate fixed bias, with
common-mode removal in the differential filter. The alternative is to use
the DAC as a voltage source into a high-impedance differential filter,
avoiding I/V stages. Screen both on loaded linearity, output-node common
mode, noise, output resistance, capacitance and out-of-band behavior. The
datasheet's 390-ohm typical per-pin output impedance is not a headphone
output impedance or justification for directly driving a jack.

Complete-chain benefit: modest DAC-core energy and genuine differential
conversion with one chip. Cost: I/V/filter bias consumption and feedback
stability; adding more op-amps can erase the core's power advantage. Large
MCLK, supply sensitivity and clock-mode transitions need qualification.
Stage 7 must choose transimpedance resistors from actual current swing,
allowable DC/common mode and hot amplifier output headroom, then compensate
DAC/input capacitance and verify loop gain. No old resistor network is
approved by this study.

### B. AKM voltage-output path, with a high-performance two-chip variant

**B1:** `Audio clock domain -> one AK4497S -> differential voltage LPF /`
`common-mode translation -> matched attenuation/gain -> protected BTL amp`.

Dedicated differential line buffers and a differential-to-SE line/IEM
branch preserve the same output contracts as A. This removes the four
current-conversion cells; it does not remove reference decoupling, active
filtering, common-mode control, volume or output protection. Keep the two
signal phases rather than collapsing to SE and recreating them for 4.4 mm.

The manufacturer's normal-load table gives 60 mA on the combined 5 V
analog rails, 1 mA per reference, 1 mA AVDD and 7/18 mA TVDD at
44.1/192 kHz with the internal LDO. Our arithmetic is approximately
336/373 mW before the external filter, regulators and clock. This is
**not** a 26 mW mobile DAC. Heavy-load mode raises consumption; normal mode
requires high-impedance AC loading. Its reference circuits include SE and
differential filters and specify external bias rather than permission to
load the common-voltage pins.
[AK4497S manufacturer datasheet, supply table and external circuits](https://www.mouser.com/pdfdocs/ak4497svq-en-full-datasheet.pdf).

**B2:** `Audio clock domain -> AK4191 -> multibit interface -> AK4499EX ->`
`four I/V cells -> differential reconstruction/gain -> same output branches`.

This targets converter/reference margin rather than more headphone watts.
The analog chip alone dissipates 308/343 mW in the documented modes, before
AK4191, external reference generation and I/V. Its specified differential
current swing is 72.8 mApp at the stated 0 dBr definition, and its reference
draw is part of the energy budget. Its interchannel gain mismatch can reach
0.3 dB, so Stage 1's <=0.1 dB complete-device matching requires calibration
or a qualified tighter result. Bias, startup and I/V compliance must follow
the manufacturer's external circuit conditions.
[AK4499EX electrical and reference-circuit conditions](https://www.akm.com/content/dam/documents/products/audio/audio-dac/ak4499exeq/ak4499exeq-en-datasheet-myakm.pdf).

B1 and B2 offer different complexity/performance trades; neither is
automatically preferable because of the brand. B2's physical digital/analog
separation can help placement, but both remain connected through power,
ground and high-speed signals. It is not galvanic isolation. AK4498EX with
AK4191 is another voltage-output variant worth revisiting if B1 clocking
or physical isolation requirements justify the second chip. It shares the
129 dB / -117 dB published class, not AK4499EX's headline envelope.
[AKM 2025 production announcement](https://www.akm.com/global/en/about-us/news/2025/20250618-ak4497s-ak4498ex/).

### C. Cirrus portable-first voltage path with separate desktop power stage

`Audio clock domain -> one CS43198 -> pseudodifferential reference-sensing`
`filter/buffer -> dedicated quiet SE/IEM stage and line branch`;
`parallel differential driver -> attenuation/gain -> protected BTL amp`.

This is an honest single-conversion stereo path with differential signaling
introduced at the driver. If maintaining opposite phases from conversion
is a hard scoring requirement, use **two** CS43198s, one stereo converter
per audio channel, mapping the same sample into both outputs with one phase
inverted. Their clocks, latency, inversion sequencing and mute must be
matched. Then drive four filters/amp legs and derive SE through an explicit
differential receiver. Never treat REFA/REFB as an actively driven inverted
audio output. Dual conversion's small energy/area cost may be reasonable,
but requires an actual interface and phase-accuracy test.

Cirrus lists 26 mW operation and a 2 Vrms capability; these headlines must
not be paired unconditionally with the -115 dB distortion entry. DS1156F2
at OUT_FS=11 and +1dB_EN=0 lists 4.90 Vpp (~1.73 Vrms) and -115 dB typical;
the boosted +1dB_EN=1 case lists 5.70 Vpp (~2.02 Vrms) and -105 dB. For the
lower-distortion comparator use the unboosted mode and obtain line level
with a qualified downstream gain stage. Dual-core baseline is approximately 52 mW before
drivers and rail conversion, not a measured complete-chain figure.
[Cirrus product specifications](https://www.jp.cirrus.com/products/cs43198/).
Its high-impedance output needs an external power amplifier for demanding
headphones. The manufacturer's QFN evaluation schematic explicitly brings
out AOUT and REF signals, supply pumps and load fixtures; that reference
is more reliable than distributor metadata saying simply "differential".
[CDB43198 schematic/layout](https://statics.cirrus.com/pubs/manual/CDB43198_REV_B_Schematic_Layout.pdf).

Benefits: low converter idle power and no external current I/V. Costs:
charge-pump switching management, reference sensing, phase splitting or a
second chip, and a narrower commercial ambient envelope (datasheet
-20 to +70 C). Chip branding does not establish adequate IEM hiss once
gain, resistors, switches and the power stage are included. Route the
portable IEM path so the high-current desktop stage can actually power
down without back-powering from analog inputs or jack connections.

### D. Precision integrated R-2R with programmable interpolation

`Audio clock domain -> interpolation/dither -> deterministic I2S-to-SPI`
`bridge -> two DAC11001B -> reference/output buffers -> analog LPF ->`
`gain/attenuation -> differential power driver plus separate SE/IEM/line`.

Two chips provide true stereo but are single-ended conversion; a
differential driver supplies BTL. Four DACs would provide two independently
converted opposite phases/channel, with simultaneous LDAC updates,
matched references and a larger cost/clock/area burden. Neither is a
discrete hand-matched resistor ladder. A fully discrete binary/segmented
ladder is a research variant requiring precision arrays, switching,
reference drivers, calibration and a verified temperature model.

TI provides a full current reference, TIDA-060031, with I2S-to-SPI conversion,
reference buffers, output filtering and separate line/headphone paths.
Manufacturer bench results show DAC11001B about -111 dB THD+N at
1 kHz/48 kHz and -108 dB at 1 kHz/192 kHz, but **-47 dB at 10 kHz/48 kHz**
and -92 dB at 10 kHz/192 kHz under the stated bandwidths. This supports a
serious ladder comparator while rejecting an assumption that its good
1 kHz result automatically holds across the band. Its measured line level
is about 2.1 Vrms; the documented idle noise is about 1.9 uVrms. These are
manufacturer reference-board results, not independent laboratory results
or our future hardware. Investigate interpolation/filter/settling changes
before claiming compliance with our full-band target.
[TI design guide and test tables](https://www.ti.com/lit/pdf/TIDUEV2),
[TI complete reference schematic](https://www.ti.com/lit/pdf/SLVRBX0).

The DAC11001B's unbuffered ladder requires positive/negative references,
high-voltage supplies and an output buffer. Its advertised 1 us settling,
20-bit monotonicity, 50 MHz SPI and temperature-calibration facility are
useful starting conditions, not a 24-bit audio guarantee.
[DAC11001B architecture and calibration](https://www.ti.com/lit/ds/symlink/dac11001b.pdf).
At 192 kHz, four 32-bit update frames demand 24.576 Mbit/s before gaps;
384 kHz demands 49.152 Mbit/s, leaving little margin below 50 MHz. Two
chips halve transport demand. Actual framing/LDAC and simultaneous
conversion, settling and host bridge timing remain gates. DSD requires
conversion to a multibit sequence; it is not a native input of this DAC.

## 3. Mature TI and ADI alternatives

PCM1792A can replace the converter in the current-output architecture A,
with its own four I/V cells, reference/bias, filter and clock ratios.
It draws approximately 205 mW at 44.1 kHz and 335 mW at 192 kHz;
the analog rail is 5 V and digital 3.3 V. External digital filtering and
DSD options exist, and its SSOP package is larger than the small QFNs.
It offers a well-documented baseline rather than a low-power advantage.
[PCM1792A supply/timing/reference circuits](https://www.ti.com/lit/ds/symlink/pcm1792a.pdf).
[TIPD177](https://www.ti.com/tool/TIPD177) demonstrates differential-current
conversion, SE summing and headphone drive with verified reference files;
its topology and output rating must not be copied unchanged into this
more powerful balanced requirement.

AD1955 likewise uses current I/V and filtering. Typical DAC power is
210 mW on 5 V analog/digital supplies; its 192 kHz and external-filter
interfaces are adequate for the initial sample-rate contract. Digital
logic thresholds must be checked against RA8P1 rather than inferred from
"I2S" compatibility. The manufacturer still labels it production and
lists a starting 1k-unit price of $11.48; that is not a one-piece quote.
[AD1955 datasheet](https://www.analog.com/media/en/technical-documentation/data-sheets/ad1955.pdf),
[AD1955 lifecycle/list price](https://www.analog.com/en/products/ad1955.html).
Neither this older DAC nor its multibit label creates an intrinsic sonic
advantage. They remain alternatives if procurement, verified reference
behavior or manufacturability outweigh the newer candidates' margin.

## 4. Analog path, volume and noise budget common to the alternatives

Separate the small-signal chain from the headphone power amplifier. I/V
compensation is a feedback/stability problem, not just resistor sizing.
Voltage-output DACs still need loading, common-mode translation and
out-of-band filtering; low op-amp voltage noise alone does not prove they
are easier to implement. Delta-sigma ultrasonic shaped noise can consume
slew/current margin or be rectified/intermodulated in later stages. Specify
wideband output noise and filter attenuation as well as audio-band THD+N.
Current-output nodes must stay inside compliance even at startup and loss
of one rail; protect headphones from downstream faults independently.

OPA1612 and OPA1656 are reference-supported small-signal candidates, not
selected parts. OPA1612 has approximately 1.1 nV/sqrt(Hz) voltage noise and
3.6 mA/channel bias; OPA1656's FET inputs have approximately
2.9 nV/sqrt(Hz) and 3.9 mA/channel. Both allow +/-2.25 to +/-18 V.
Bipolar current noise/bias can favor lower source impedances; FET inputs
can favor a higher-impedance volume/filter node. Their drive limits do
not meet the desktop power requirement as bare output stages.
[OPA1612 datasheet](https://www.ti.com/lit/ds/symlink/opa1612.pdf),
[OPA1656 datasheet](https://www.ti.com/lit/ds/symlink/opa1656.pdf).

Illustrative arithmetic, not an approved circuit: eight 3.6 mA amplifier
channels on +/-5 V consume 288 mW idle; on +/-12 V they consume 691 mW.
Use the **total** positive-to-negative voltage times quiescent current.
Adding a DAC, clocks, references and line buffers can make support circuits
dominate mobile conversion energy. Disable unused branches and investigate
lower small-signal rails; do not force every audio op-amp onto desktop
headphone rails. Hot maximum supply current, load power and regulator
losses belong in the later worst-case budget.

Our independent flat-band noise calculations use
`en_R = sqrt(4*k*T*R*B)` at 300 K and B = 19,980 Hz:
100 ohms contributes 0.182 uVrms, 1 kohm 0.575 uVrms, and 10 kohms
1.819 uVrms for a directly presented resistor. Real feedback/filter
resistors have noise-transfer gains and bandwidths; add them accordingly.
A 1 kohm source plus ideal unity-noise-gain 1.1 nV/sqrt(Hz) amplifier is
already about 0.596 uVrms before current noise and 1/f noise. Two such
uncorrelated balanced legs give 0.843 uVrms before DAC and output-stage
contributions. The <=1 uV **unweighted** jack target is therefore a whole
chain design constraint. A-weighted chip noise cannot be inserted as an
unweighted budget value. Two independent 0.55 uV A-weighted channels would
give 0.778 uV differential at unity gain in the same weighting, before
downstream noise; correlation and phase mapping must be measured.

Use digital volume for fine resolution/ramping and DSP headroom, together
with matched analog gain/coarse attenuation or an optimized IEM path.
Digital attenuation lowers the music but does not attenuate noise generated
after conversion. Assess three implementations without selecting yet:

1. Matched switched resistor network before a low-noise buffer, with
   low source impedance, resistor noise budget and contact/switch
   distortion qualification. Four balanced phases must change coherently.
2. PGA/analog volume IC, checking its own input/output noise, gain range,
   supply/common-mode limits and near-zero channel matching. A convenient
   volume-control IC can consume the entire IEM noise allocation.
3. DAC fine attenuation plus analog feedback gain switching and a
   dedicated IEM branch, with controlled break-before-make, mute and
   DC settling. Switching feedback can momentarily open a loop; hardware
   limits and transition sequencing are required.

Do not use a large series resistor at the headphone jack as the main IEM
attenuator: it increases output impedance and interacts with impedance
curves. Pre-amplifier attenuation also cannot suppress the power stage's
own noise. DAC reference full-scale changes are a fourth option only if
linear/noise behavior, calibration and safe transitions are validated.

Provide dedicated line buffers from the small-signal branch; target
2 Vrms SE / 4 Vrms balanced into >=10 kohms with <=100 ohm source impedance
and capacitive stability. Fixed line mode bypasses user attenuation through
an explicit hardware route or gain setting, while variable mode retains
volume. Hardware default mute and jack/type interlock must prevent a fixed
line level from appearing at an IEM. A 4.4 mm line connection requires
documented ground/shield handling, not a grounded headphone adapter.

## 5. Quantified ladder / multibit / NOS comparison

"Multibit" does not mean "R-2R", and R-2R does not mean "NOS".
Modern delta-sigma devices commonly employ multibit internal elements,
oversampling and mismatch shaping. An R-2R DAC can use a digital
interpolation filter; a delta-sigma DAC can expose bypass options.
Architecture alone does not determine time-domain response or audibility.

| Issue | Noise-shaped integrated DAC | Precision ladder / discrete variant |
| --- | --- | --- |
| Low-level linearity | Internal calibration/mismatch shaping; evaluate idle tones, dither, near-zero codes and filter modes. | Static INL/DNL, transition glitches and reference modulation remain; low noise alone does not prove good code accuracy. |
| Out-of-band behavior | Shaped ultrasonic noise needs reconstruction/analog bandwidth control. | Sampling images, settling and switching glitches need reconstruction; no automatic freedom from ultrasonic energy. |
| Reference/temperature | Supply/reference noise and drift still matter; no brand exemption. | Precision reference buffering and ratio tracking are central; discrete thermal gradients and switch resistance add difficult matching terms. |
| Power/area/BOM | One low-power chip can integrate filtering and interface; I/V may add several cells. | Separate serial bridge/interpolation, references, buffers and possibly four DACs/arrays; core alone is an inadequate energy comparison. |
| Manufacture/calibration | Validate the manufacturer's intended reference circuit, gains and tolerances. | Integrated trimmed ladder gives a reproducible baseline; a discrete ladder needs matching, calibration coverage, calibration retention and hot/aged verification. |
| Filter flexibility | Built-in choices/custom modes vary by part. | Arbitrary interpolation is feasible, but costs hardware processing and does not establish superior sound. |

Independent numerical screen: one full-scale LSB is 15.259 ppm at 16 bits,
3.815 ppm at 18, 0.954 ppm at 20 and 0.0596 ppm at 24. Half-LSB accuracy
halves those budgets. These are **system output-error budgets**, not a claim
that every resistor only needs that tolerance. Major-carry weighting,
switches, parasitics and correlated ratio errors determine real INL/DNL.
A nominal 0.01% resistor is 100 ppm; that label alone does not establish
20-bit linearity. Even 0.1 ppm/K ratio drift over 40 K is 4 ppm, about
4.2 full-scale 20-bit LSBs. Global gain drift is different from nonlinear
ratio drift and may be correctable without improving DNL. An integrated
trimmed ladder can be much better than a hand-assembled network, but the
same distinctions still apply to its reference and output electronics.

An ideal full-scale sine's quantization SNR is `6.02*N+1.76` dB:
approximately 122.2 dB for 20 bits. This says nothing about analog noise or
dynamic distortion; the TI reference results above demonstrate the gap.
Oversampling and dither may improve in-band quantization behavior; they
do not repair unknown static nonlinearity or insufficient settling.
Calibration needs traceable transfer characterization and temperature
coverage, rather than just a zero and gain measurement. Bit-perfect
24-bit input truncation to 20 bits is not 24-bit analog conversion.

For ideal zero-order-hold NOS,
`H(f) = sin(pi*f/fs)/(pi*f/fs)`. At 20 kHz the droop is -3.168 dB for
44.1 kHz, -2.640 dB for 48 kHz, -0.156 dB for 192 kHz and -0.0388 dB
for 384 kHz, before an analog filter. The first image of a 20 kHz tone
at 44.1 kHz lies at 24.1 kHz. Thus ordinary NOS at base sample rates fails
our +/-0.1 dB response target and burdens the analog filter with a narrow
transition. Correcting droop alone does not remove images. Oversampling
or a sharp reconstruction filter addresses the engineering problem;
calling image energy or droop an intrinsic sonic improvement is unsupported.
The core choice and interpolation rate must respect actual transport,
settling and power budgets.

## 6. Procurement and lifecycle screen

Observed 2026-10-04 through manufacturer/distributor pages; cached/indexed
inventory can lag actual stock. These are research snapshots, not live
cart quotes, reserved stock, purchases or future availability guarantees.
Prices exclude tax/freight/tariffs. Obtain a current one-piece authorized
cut-tape quote before Stage 6 selection, and retain a schematic-compatible
alternative where practical. Different converter families are not pin swaps.

| Part | Observed source/price/quantity | Risk / implication |
| --- | --- | --- |
| ES9039Q2M | [Mouser regional page](https://br.mouser.com/pt/ProductDetail/ESS-Technology/ES9039Q2M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): USD18.70 qty1, 628 shown, cut tape listed. | ESS lists active/new-design recommended. Conflicting aggregator stock is not used to claim unavailable; refresh distributor quote before selection. |
| AK4497SVQ | [DigiKey](https://www.digikey.com/en/products/detail/asahi-kasei-microdevices-akm/AK4497SVQ/26255928): USD41.05 qty1 CT, 607 shown, 22-week standard lead time. | New production generation; manufacturer 250-piece packing quantity does **not** prohibit distributor one-piece cut tape. Full verified application/EVB documentation and reference capacitor area remain gates. |
| AK4499EXEQ | [DigiKey category listing](https://www.digikey.com/en/products/filter/data-acquisition/adcs-dacs-special-purpose/768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): USD68.82 qty1 CT, 805 shown. | Additional AK4191 and I/V/reference costs; manufacturer mass-production status is not a long-term supply guarantee. |
| AK4191EQ | [DigiKey](https://www.digikey.com/en/products/detail/asahi-kasei-microdevices-akm/AK4191EQ/18109637): USD11.54 qty1 CT, 260 shown. | B2 converter pair is approximately USD80.36 before reference/I/V/filters; firm quote still required. |
| CS43198-CNZR | [DigiKey](https://www.digikey.com/en/products/detail/cirrus-logic-inc/CS43198-CNZR/7430362): USD18.19 qty1 CT, 481 shown, 20-week standard lead time. | Active, two chips approximately USD36.38 converter-only. Commercial temperature limit and correct pseudodifferential topology need attention. Do not substitute obsolete CS4399. |
| PCM1792ADB | [DigiKey listing](https://www.digikey.in/en/products/detail/texas-instruments/PCM1792ADB/1573317): 211 shown in indexed regional listing; single-piece USD price not verified. | TI active, mature package/reference support; refresh stock/quote, no lifespan inferred from age. |
| AD1955 | [ADI](https://www.analog.com/en/products/ad1955.html): production, starting USD11.48 at 1k units. | One-piece stock/price not verified; this is a quantity list price. Documentation maturity helps reproducibility but not supply longevity. |
| DAC11001B | [Mouser US BPFBT](https://www.mouser.com/en/ProductDetail/Texas-Instruments/DAC11001BPFBT?qs=doiCPypUmgGMYjFfmnds9Q%3D%3D): USD142.07 qty1 CT, 350 shown, 16-week estimated factory lead time. [DigiKey PFBR](https://www.digikey.com/en/products/detail/texas-instruments/DAC11001BPFBR/18158712): not normally stocked, USD85.1235 at 1000. | One-piece authorized cut tape is listed; do not confuse reel packing with minimum purchase. Two/four chips are USD284.14/568.28 before references/bridge. Confirm exact suffix and quote. |

High component cost can be justified by guaranteed behavior, lower noise,
stable references or easier qualification. This screen does not demonstrate
an audible advantage from a USD68 DAC over a USD19 DAC. Neither price nor
newness establishes better battery life, headphone drive or reliability.

## 7. Stage 6 decision inputs and unresolved gates

Carry **A, B1/B2, C and D** into the combined architecture score. No final
DAC or analog topology is selected here. A and C plausibly protect runtime;
B1 offers a straightforward differential voltage chain; B2 offers more
converter margin with support-power cost; D provides a documented ladder
experiment with significant high-frequency/transport gates. These are
engineering inferences from the evidence above, not measured complete-player
performance or a runner-up designation.

Before final component integration/rating release, close: complete idle/playing energy including clocks and
references; unweighted active-zero IEM noise; matched gain/volume transition
behavior; wideband out-of-band response and loaded full-band THD+N; DC/common
mode and rail-loss faults; SSI/USB/bridge clock compatibility; line/headphone
connector routing; reference/filter capacitor volume; genuine authorized
small-quantity supply and document access. A stage should not claim completion
of full reference-board replication or independent continuous-power testing
merely because a public datasheet and schematic were reviewed.

Any performance advantage at -115 versus -120 dB converter distortion is
primarily engineering margin until complete-path measurements and controlled
listening demonstrate otherwise. Avoid spending the portable power budget
on a higher DAC headline while the high-gain amplifier hisses or the sealed
enclosure cannot sustain the output envelope. The final selection belongs
to Stage 6 after independent amplifier/platform/power studies. A provisional
architecture recommendation may proceed from this research; it must retain
unperformed measurement, sourcing and timing checks as explicit hold points
rather than assert that the reference behavior has been reproduced.

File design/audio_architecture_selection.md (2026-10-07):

# Stage 6: recommended portable and desktop audio architecture

**2026-10-05 external-review update:** the transport and high-power amplifier recommendation is
reopened by [the disposition record](audio_external_review_2026-10-05.md).
RA8P1 remains system master. The sixteen-BUF634A bank is a research
comparator; no high-power implementation is selected. PCM768/DSD512, premium Bluetooth and the higher desktop envelope are
now owner-required. XU316 is the primary high-rate bridge candidate;
its exact package and routing are not selected.
Earlier recommendations below remain traceable study history, not a design
freeze. Use the revised work plan for the next implementation steps.

2026-10-05. **Provisional architecture selection for component investigation**,
not a performance rating, procurement release or finished circuit.
The owner requested staged research before final audio CAD. Stages 1–5 now
have source-linked studies and checked arithmetic. Independent review found
no remaining calculation blocker; corrections to Cirrus operating modes and
main-host PD routing were incorporated. Bench tests, sourcing confirmations,
stability/thermal and several interface proofs remain open.

## Primary recommendation

Recommend **one ES9039Q2M differential DAC, separate quiet IEM/ordinary and
high-power headphone paths, a precision composite AB desktop amplifier,
native RA8P1 USBHS/DSP and negotiated host-powered USB-C power management**.
Use dedicated line buffers branching ahead of the headphone stages.

Start component investigation with the manufacturer's differential I/V
reference, a precision switched-resistor coarse attenuator plus DAC fine
volume, and **OPA1656-controlled BUF634A buffer banks** for the high-power
path. The Stage 7 comparison now investigates four **independently controlled
unity composite branches** per leg, with required signal gain upstream.
The common-controller bank is rejected as the wiring basis. Four legs form
the balanced stereo output; the quiet path starts with OPA1622
on independent lower rails and low noise gain. Final resistor values,
compensation, rail generation and buffer count remain calculation/bench gates.
No unchanged earlier INA1620 power circuit is approved by this selection.

Keep the present RA8P1, external SDRAM/NOR/microSD and C6 Wi-Fi hardware
direction. Use the native USBHS foundation instead of adding XMOS/Linux by
default. **The present 5 MHz radio transport is insufficient for worst-case
192 kHz own-server streaming**. Faster SPI timing or an alternate transport
is an integration hold point; neither has been approved. Wireless headphone
audio is not established by C6. No firmware implementation is part of this task.

One main USB-C port carries host audio and host power. Negotiate offered PD;
host budget supplies playback first and charges from surplus. When full,
charging stops and desktop playback must not repeatedly cycle the pack.
High rails require a valid sufficient contract, rail health and thermal
permission. The retained protected Jauch 1S pack remains the first battery
candidate, with a protected 2S alternative if current/efficiency/runtime
qualification justifies reopening the existing low-voltage supervision.
TPS25751D/BQ25798 is the **first PD/charger pair to qualify**, not a safe
drop-in circuit. Wet/default/NTC configuration and battery isolation are open.

### Why this wins the initial comparison

This conversion path has genuine differential outputs, modest DAC core
power and public current reference information. The candidate's small-quantity
price is about $19. It does not require the two-chip AKM modulator/DAC pair,
four-channel Cirrus inversion scheme or precision ladder bridge/references.
Its manufacturer -120 dB result was at a 10 Vrms evaluation output, so we
do not promise that number at our jacks. The reason to choose it is the
complete energy/interface/reference trade, not a presumed ESS sound.

Separate output paths are justified by **idle energy and noise gain**:
the high-current stage can be off during IEM/ordinary listening. A shared
power amplifier would need verified low-bias/low-noise operating modes and
additional buffer isolation to offer equivalent portable performance.
The primary integrated composite is reproducible from manufacturer examples
and avoids immediately inventing a discrete bias/SOA system. Its scalability
comes with real component count, bias power and thermal costs, accounted below.

## Runner-up and substitution triggers

The complete runner-up is **AK4497S differential voltage conversion with
the same quiet/high-power output separation, host platform and power roles**.
It removes four I/V cells and may simplify common-mode/filter qualification.
Its approximately 336–373 mW DAC consumption and ~$41 converter cost must
be weighed against the support stages it removes. Choose it if prototype
measurements show lower complete-chain energy or easier full-band/noise
qualification than the ESS I/V path, or ESS sourcing/document access fails.
DAC family substitution requires a new clock/rail/filter design, not a pin swap.

The preferred amplifier fallback is a precision **discrete AB composite**
with qualified bias tracking and hot SOA. Choose it if the buffer bank cannot
meet current sharing, compensation, heat or output-impedance goals at reasonable
area/power. Do not select output transistors until those comparisons establish
a benefit. A discrete label alone does not improve sound or current safety.

Cirrus remains a portable-energy contingency if full balanced conversion can
be obtained at lower whole-chain power; its boosted output/distortion conditions
and duplicated inversion/interface must be correctly budgeted. AK4499EX/AK4191
is a converter-margin option if extra power/area is affordable and measurements
justify it. The R-2R reference has documented high-frequency limitations and
extra bridge/reference/calibration work; no demonstrated system benefit here
justifies making it the primary or runner-up.

## Comparison and selected signal routing

| Architecture | Whole-system attraction | Main penalty | Disposition |
| --- | --- | --- | --- |
| ESS differential I/V + quiet path + composite bank | Low core energy, one differential converter, public references, scalable separate amplifier | I/V noise/stability; bank bias/sharing and board heat | Primary architecture for component investigation. |
| AK4497S voltage path + same amplifier branches | Fewer conversion amplifiers, true differential path | Higher DAC energy; whole-chain advantage unmeasured | Runner-up. |
| Dual/inverted CS43198 + same amplifier branches | Small core energy, no current I/V | Two chips/inversion timing, mode-dependent distortion, reference sensing | Portable-energy contingency. |
| AK4191 + AK4499EX + I/V | More converter margin and separated digital/analog devices | Reference/I/V energy, cost and area | Only if complete-device benefit is demonstrated. |
| DAC11001B ladder + bridge/interpolation | Documented precision ladder/reference experiment | Full-band dynamic performance, transport, reference/area/calibration burden | Not justified as the default personal player. |

```mermaid
flowchart LR
    USB[USBHS UAC2 from host] --> CPU[RA8P1 buffered PCM / bounded DSP]
    SD[Local storage / own-server Wi-Fi transport] --> CPU
    OSC[44.1 and 48 family clocks / muted selector] --> DAC[ES9039Q2M master clock domain]
    DAC -->|BCLK and LRCLK| CPU
    CPU -->|Stereo PCM| DAC
    DAC --> IV[Differential I-V / reconstruction]
    IV --> LINE[Dedicated fixed / variable line buffers]
    IV --> ATT[Matched coarse attenuation / gain]
    ATT --> QUIET[Quiet SE and differential headphone paths]
    ATT --> BANK[Four-leg composite AB power path]
    QUIET --> SAFE[Mode selection / hardware DC and rail disconnect]
    BANK --> SAFE
    SAFE --> HP[3.5 mm SE / 4.4 mm balanced]
```

Each signal branch has a loading/noise contract. Dedicated SE derives from
a precision differential receiver and quiet power stage. If high-power SE
is offered by two bank legs, each active output is ground referenced and
independently protected; never ground an active balanced negative terminal.
SE high-power voltage is half BTL at the same leg swing and has its own
current/thermal rating. Do not connect both output banks at once or assume
both jacks can play simultaneously.

Line target remains 2 Vrms SE / 4 Vrms differential into >=10 kohms, with
<=100 ohm source impedance and verified capacitive loading. Line mode
branches before the power bank. Fixed-line mode must not expose an inserted
IEM to uncontrolled full scale. Connector sensing and mode selection need
a hardware default-safe state and a defined user-visible mode contract.
Dedicated line connector versus shared-jack interlock is a mechanical/circuit
decision to close before final routing; no nonexistent line jack is implied.

## Output modes and energy consequences

All figures below are investigation limits. Actual hot device swing,
component tolerances, protection, continuous power and enclosure heat can
only lower them until verified. Keep IEM/low/medium/high signal gain distinct
from portable/desktop supply mode. Analog attenuation reduces upstream noise;
digital volume alone does not reduce noise generated after the DAC.

| Mode | Intended path/rails | Preliminary envelope / reason |
| --- | --- | --- |
| Quiet IEM and ordinary listening | OPA1622 quiet stages, investigate +/-3V signal/output rails, power bank off | Initial <=50mA peak/ch and <=0.5V SE / <=1V balanced ceiling, constrained by load; qualification must include 8–9 ohms. Very low gain/coarse attenuation and <=1uV unweighted noise are leading goals. Higher quiet-path gain/voltage only after hot linear-drive/noise proof. |
| Portable demanding headphones | Composite bank, investigate +/-6V and optional higher portable rails | Initial 4Vrms balanced, 0.25Apeak and 0.5W/ch caps for low rail mode. +/-5V is rejected for the unity-controller common-mode limit. Higher battery mode may investigate 8V ceiling with 1W/ch cap and separate pack/thermal proof. Runtime is shorter; no desktop rating implied. |
| Desktop low/mid impedance | Bank on, investigate +/-10V low-load/floor and +/-12V mid-load stretch | 2W/32 floor, 4W stretch with explicit current/power/SOA and source-budget limits. Buffer headroom can require the middle rail range for 4 W/32; do not assume +/-10V is sufficient. |
| Desktop high voltage | Bank on, investigate +/-14V | Up to 16 Vrms BTL, subject to 0.707Apeak and 4 W/ch caps. Intermediate-amplitude worst heat must be tested. |
| Line / preamp | Dedicated signal buffers, power headphone bank off | Fixed/variable 2 V SE or 4 V differential into line loads, independently muted and protected. |

Four nominal buffers share 0.707Apeak as 177mA each. The earlier hypothetical
25% sharing allowance is **not justified** by the datasheet. The
[offset/ballast investigation](audio_buffer_qualification.md) identifies why
typical DC output resistance cannot establish a guaranteed hot sharing bound;
shared feedback does not independently correct branch offsets. The next
prototype candidate uses one unity composite loop per buffer, sensing before
its own ballast; signal gain is upstream. Separate gain-2 loops with the
illustrative matched array exceed the typical-current comparison in aged
corners. See the complete [separate-loop comparison](audio_buffer_qualification.md#separate-loop-comparison-and-next-circuit-direction).
Native bank wiring stays on HOLD pending hot drive, stability and hardware
fault-disconnect review. The conditional unity screen is about 200mA at the
full low-load envelope; typical 250mA is not a guaranteed hot rating.
The exposed pad is at V-, so thermal copper must not be casually
tied to the ground plane. Preserve feedback before the disconnect; contact
opening must not leave the precision loop open or drive it into saturation.

The separate-loop direction allocates sixteen wide-bandwidth BUF634A,
sixteen loop cores and four provisional upstream OPA1656 gain cores. They
consume **5.992W typical idle at +/-14V**, **5.136W at +/-12V**, **4.280W
at +/-10V**, or **2.568W at +/-6V**, using 8.5mA/buffer and 3.9mA/core.
The earlier +/-5V allocation was 2.140W and cannot support the retained
4Vrms target with these unity loops. See the
[common-mode and portable energy correction](audio_composite_rails.md).
Upstream gain/count remain open. The earlier 4.245W high-rail number used
only four controllers and no longer represents this candidate.
Low-bias buffer operation reduces energy but
changes loop behavior; no such loop is qualified. High-power portable
runtime cannot use the 10-hour quiet-playback number. Six quiet OPA1622 cores
on +/-3V would have an illustrative 93.6 mW typical core bias before loads,
filtering and regulation. Actual maximum and disabled leakage still matter.

Including bank bias in Stage 5's illustrative 90% converter/3W other-device/
4.55W charge/10% margin screen gives approximately **36.10W input at 4 W/16**,
**33.81W at 4 W/32 on +/-12V**, and **33.61W at 4 W/50**. Circulation,
dynamic loop and ballast losses are excluded. A 45 W-class negotiated source is
an investigation basis; final concurrent device loads may require more or
a lower amplifier ceiling. At 4 W/16 the modeled device heat rises to 19.76 W
before charging heat: even a 15 K rise screen needs about 0.76 K/W. A sealed
portable enclosure will likely require a substantial heat path or a reduced
sustained rating. Bank selection does not eliminate the thermal problem.

The independent bank review replaces the ideal 1.5 V headroom assumption for
the 32-ohm stretch: 8 V peak/leg on +/-10V leaves only 2 V. BUF634A's 25 C
wide-bandwidth table at +/-15 V lists maximum headroom of 2.2/2.5 V at
100/150mA respectively (typical 2.0/2.2 V). These are not hot guarantees. Investigate
+/-12V for that case, with hot swing, ballast and droop still open. This changes
mode selection and power budget, rather than claiming the ideal Stage 5 table
proves a real amplifier. The unsupported 25% sharing assumption is removed;
static tolerance screens do not establish AC or hot current sharing.
For revised bias screening, 16 * 12mA+20*5mA on +/-14V gives 8.176W, combining BUF's 25 C
maximum and OPA1656's temperature maximum; it is not a full hot BUF guarantee.
Use exact hot maxima/measurements in the final power/thermal budget.

The continuous target is 2 W/32; 4 W and 16 V are stretch envelopes until thermal/
headroom proofs. There is no honest "any headphone forever" guarantee.
Original HE-6 and Susvara screens support the useful margin, while
electrostatics and unusual ribbons need different output hardware.

## Clock, USB and DSP hardware contract

Investigate 22.5792 MHz and 24.576 MHz audio-family oscillators and a real clock
selector, never tied outputs. ES9039Q2M master ratios 128/256/512 can support
44.1/48 through 176.4/192k families on those clocks. This is DAC PCM master
operation; ESS asynchronous slave/ASRC mode needs >=130FS and must not be
confused with asynchronous USB feedback. Use the same audio domain
for DAC consumption, SSI DMA accounting and asynchronous USB feedback;
USB arrival timing is not the sample clock. No separate PLL or FPGA is
justified merely by a phase-noise headline. Exact oscillator/mux sourcing,
power, duty cycle, startup and output skew remain open.

For the simple sampling-jitter upper-bound model
`SNRj=-20*log10(2*pi*f*tj)`, at 20 kHz, 100 ps gives 98.0 dB, 10 ps 118.0 dB,
and 1 ps 138.0 dB. This is our ideal sinusoidal model, not the DAC's measured
jitter transfer: PLL/reclocking/filtering and the phase-noise integration
bandwidth matter. A 1 kHz tone has 26 dB less sensitivity under the same model.
Measure output sidebands with realistic power/RF/USB interference before
spending energy on progressively smaller oscillator jitter numbers.

PCM goal is stereo 24-bit data carried in 32-bit slots through 192 kHz. Native
384k is excluded on the present SSI timing route. DSD is optional and must
not bypass gain/safety or silently claim DSP on a native bypass stream.
RA8P1 handles bounded PEQ/crossfeed/balance/headroom; add a dedicated DSP
only if actual workload/numerical/power benchmarks fail. Firmware behavior
is a separate project, but hardware must expose feedback timing, sufficient
buffers and reset/mute lines. XU316 is the platform fallback if native UAC2/
timing/DMA interoperability fails; Linux needs a demonstrated workload benefit.

## Component disposition and procurement

| Major function | Selected architecture direction / limitations | Alternatives and sourcing status |
| --- | --- | --- |
| Host, DSP, storage, radio | RA8P1+C6 with existing SDRAM/NOR/microSD; no new FPGA/DSP/USB bridge | Stage4 records variants, voltage/current and timing. UC0/UC1 silicon change, radio transport and wireless-audio limits remain open. Existing BOM costs, not invented new quotes. |
| DAC | ES9039Q2M for differential conversion / I-V reference investigation | ~$18.70 qty1 CT snapshot, Active/new-design recommended; AK4497S runner-up ~$41.05. Component-specific power/sequence/clock verification required. |
| Quiet amplifier | OPA1622, low noise gain and gated low rails | ~$7.43 qty1 CT snapshot; current/SOA and all-source noise limits. INA1620 is an alternative for matched integrated resistors, not higher output power. |
| Desktop precision loop and buffers | One OPA1656 core per BUF, four unity branches/leg; provisional upstream gain | Exact BUF634AIDRBR [DigiKey snapshot](https://www.digikey.com/en/products/detail/texas-instruments/BUF634AIDRBR/13627165): 529 shown, $4.08 qty1 /$3.086 qty10 CT, 12-week lead time, Active. Sixteen buffers ~$65.28 at unit price before ten dual drivers/protection. Counts, unity/coupled-loop compensation, hot current/swing and package choice unqualified. Discrete AB is the amplifier fallback. |
| I-V/filter/line amplifiers | Differential manufacturer reference; OPA1612/OPA1656 first comparators | Exact count/rails and noise-current trade determine the final part, not a universal op-amp brand. Procurement and compensation remain open. |
| Volume | Precision coarse switched resistors plus DAC fine attenuation, hardware low-gain default | Switch/relay/PGA exact choice pending noise, distortion, RON/leakage, matching and transition proof; no audio volume IC selected. |
| Clocks | Two family oscillators plus muted selector | Exact MPNs pending phase-noise/duty/timing/power and authorized stock, rather than assumed popular "audio clock" part. |
| PD/charger/power path | Host-powered external analog bypass; TPS25751D/BQ25798 first pair to qualify | Part defaults, independent CE/NTC and desktop battery isolation prevent a drop-in selection. Simpler sink-only + independent wet controller is fallback; optional auxiliary inlet/PD dock for weak host. |
| Converters/LDOs | Mode-dependent dual rails, separate low-current signal regulators | LM5155/LT8582 topologies, LT3045/LT3094 are study candidates, not final BOM. Switch-current versus output-current and LDO 500 mA limits remain explicit. |
| Battery | Existing purchased protected Jauch 1S 6 Ah candidate and insulated contact NTC | 22.2Wh nameplate, historical ~$30 snapshot; real capacity at 4.10 V/aging/cold/load and 4 A allocation not closed. Purchased protected 2S alternative only after full new path proof. |

Primary data and complete alternatives are linked in
[conversion study](audio_architecture_candidates.md),
[amplifier study](audio_amplifier_study.md),
[platform study](audio_platform_study.md) and
[power study](audio_power_study.md). Claimed differences below transparent
loaded performance are measurable margin, not demonstrated audible brand
benefits. Noise, clipping, response and reliable protection affect real use.

## Stage 7 scope and hold points

Begin bounded **symbol/pin-map and circuit investigation** for this architecture.
Do not wire a complete high-power bank or charge-enabled PD circuit until its
corner calculations and independent review close. Keep the existing U34/K1
draft labeled incomplete; it is a potential quiet SE branch, not the desktop
amplifier or an operational protection circuit. Four balanced disconnect poles,
DC/rail/temperature/current latches and connector/path interlocks remain absent.

Next concrete work: verify exact buffer symbol pins and V- exposed pad;
budget sharing/ballast and hot swing; qualify the ESS supply sequence/I-V
reference; verify source permission/battery isolate/full-charge defaults;
close SSI timing and faster radio transport. Record component costs and
availability without treating reel sizes as minimum buys. Save/export/inspect
the full PDF/ERC/native BOM and push each coherent CAD checkpoint.

Ratings and production release additionally require independent loaded
noise/THD/IMD/multitone/frequency-response tests, USB/PD/RF interference,
headphone impedance/cable stability, fault injection, thermal steady state,
battery temperature and wet/dead-battery behavior. These have not occurred.
This recommendation authorizes the next engineering investigation, not an
unqualified finished schematic or a claim that bench gates passed.

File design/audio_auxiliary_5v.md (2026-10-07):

# Auxiliary audio 5 V converter draft

U36 TPS630701RNMR is placed in the native headphone schematic. VIN 12/13
and VOUT 7/8 are tied; FB 5 senses VOUT. GND 4, PGND 10, VSEL 15 and unused
FB2 6 are grounded. PS/SYNC 1 is now grounded for forced PWM.
L3 connects switching pins L1 11 and L2 9, separately from ground.
C132 is the dedicated VAUX 3-to-ground bypass.
The converter is incomplete; this checkpoint supplies no new working rail.
Its intended source is the bounded low-voltage system bus, never raw 20 V PD.

[TI SLVSC58B Rev B](https://www.ti.com/lit/ds/symlink/tps63070.pdf), sections
5, 6 and 9.3, specifies the fixed 5 V variant without output discharge,
2-16 V input, FB connected to output, VAUX used only for its bypass capacitor,
and an optional unused FB2 left open or grounded. Forced PWM requires PS/SYNC
low; VSEL must have a defined state. PG is open drain. The fixed-output LC
criterion requires effective Cout in uF at least fifteen times effective L
in uH. Evaluate tolerance, bias and temperature, not nominal capacitance alone.
The advertised switch current is not a guaranteed continuous output rating.

[DigiKey 296-47298-1-ND](https://www.digikey.com/en/products/detail/texas-instruments/TPS630701RNMR/6175215)
was Active with cut-tape MOQ1, stock 7,383 and USD 3.37/1 on 2026-10-05.
This unreserved snapshot does not establish future lifecycle.

Next implement the input capacitor bank, default-off enable,
power-good interface and bounded source connection.
Then establish total auxiliary load, bus bounds, startup/shutdown, backfeed,
fault behavior, ripple and converter/LDO dissipation across temperature.
U35 and its relay coil remain dependent on this unfinished source.
Independent hardware headphone protection and relay gating remain open.

## Passive selection constraints (2026-10-05)

Use a 1.5 uH nominal shielded inductor as the starting point. With +20%
inductance tolerance, Lmax is 1.8 uH and the fixed-output capacitance criterion
requires at least 27 uF effective output capacitance. A nominal 68 uF bank
therefore needs at least 39.706% retained capacitance across tolerance,
temperature, DC bias and aging. A generic 80% capacitance-loss assumption
gives only 13.6 uF and fails. Do not approve a bank by nominal value alone.

[Coilcraft XFL4020, document 745-1 revised 2026-03-10](https://www.coilcraft.com/getmedia/50632d43-da1b-4cdb-8ab4-3029cab51df3/xfl4020.pdf)
lists XFL4020-152MEC at 1.5 uH +/-20%, 15.8 mOhm maximum DCR at 25 C,
and 4.1/4.4/4.6 A for 10/20/30% inductance drop at 25 C. These are not
guaranteed hot-current limits. Its 6.7/9.1 A thermal-reference currents do
not establish saturation margin or application temperature. Packaging C
replaces the legacy B suffix; C does not require buying a full reel.
TI's reference design uses this family, but that alone does not qualify it.

[XGL4020-152MEC](https://www.coilcraft.com/en-us/products/power/shielded-inductors/molded-inductor/xgl/xgl4020/xgl4020-152/)
is an alternative: 14.3 mOhm maximum DCR at 25 C, with 3.2/5.3/7.5 A
for 10/20/30% inductance drop. It has softer saturation, not uniformly
better inductance retention. Compare actual loss at 2.1..2.7 MHz and hot
inductance at the intended current. L3 is now placed as this prototype
candidate, with procurement HOLD and footprint deferred. It is not released
for production or electrically qualified.

Live distributor pages supersede cached search stock on 2026-10-05:
[LCSC C7417180](https://www.lcsc.com/product-detail/C7417180.html) showed
2,284 XGL4020-152MEC pieces, MOQ1/multiple1, USD5.9908/1 and 5.3022/10.
These are unreserved stock and price snapshots. The live Mouser XFL page
showed zero stock and a 40-week lead time; LCSC XFL C3033018 was out of stock.
The older DigiKey XGL listing said no longer available at DigiKey.
Manufacturer direct purchase availability was ambiguous. This expensive
quantity-one fallback still needs lifecycle and lower-cost supply review,
along with hot inductance, peak/fault current, loss and loop qualification.

The TI 4.15 A maximum current-limit figure applies to average positive input
current at VIN=5 V, VOUT=6.5 V and Tj=0..125 C. It is neither a peak-current
limit nor a general guaranteed load rating at the intended bus voltage.
The coil has only about 62 mA provisional demand; the rest of the auxiliary
load must be established before selecting the converter's operating ceiling.

For provisional VIN=3.2..4.5 V, VOUT=5 V and Lmin=1.2 uH, ideal boost ripple
is VIN*(1-VIN/VOUT)/(Lmin*fmin), giving 0.457143 A peak-to-peak at 3.2 V
and fmin=2.1 MHz. Peak current must include half of that ripple above the
average current. This approximation excludes mode transitions, startup,
inductance droop and faults; it cannot qualify protection or saturation.

TI section 6, section 8.4.5 and the electrical accuracy table consistently
define PS/SYNC low as forced PWM and high as PWM/PFM. Several application
curve captions reverse those labels. Follow the explicit pin/mode definitions;
do not infer low-load mode or efficiency from the conflicting captions.

Saved library checks confirm fifteen unique exact package pins and intended
electrical types, uniform 150 mil legs, grid endpoints, hidden metadata at
origin and blank footprint. The single-unit native SVG was visually reviewed.
The library asset is now instantiated as U36. C132 uses TDK
C1608X7R1H104K080AA, 100 nF +/-10%, 50 V X7R, -55..125 C, Production.
It is exclusively a VAUX bypass, not an auxiliary load. TI specifies 100 nF;
VAUX absolute maximum is 7 V. Effective capacitance and placement remain
subject to qualification. The inherited exact-part sourcing fields were
retained and its role-specific selection basis was updated natively.

Checkpoint verification: relay022 exported netlist confirms L3 pin 1 to
U36 pin 11 and L3 pin 2 to U36 pin 9, with no accidental ground connection
at either wire crossing. All prior component net memberships are unchanged
from relay021. VAUX remains separate from ground. BOM fidelity passes for
316 included references, 19 columns and four native exclusions. The full
fifteen-page PDF was reviewed; pages 1..14 render identically to the previous
commit, and page 15 shows the inductor and mode wiring. ERC still reports
106 errors and 15 warnings; unfinished VIN, EN and PG integration remains
visible. No ERC policy was changed. Clock arithmetic passes. Forced PWM
low-load battery efficiency remains to be evaluated.

## Output bank sizing screen (2026-10-05)

The starting output bank is four Samsung CL32B226MOJNNNE capacitors,
22 uF each, 16 V, X7R, +/-20%, 1210. C133-C136 are now placed and wired
in parallel between U36 VOUT/FB and ground. Procurement remains HOLD and
footprints remain deferred pending electrical and package qualification.
Samsung's live manufacturer page reports Mass Production and supplies
typical curves only. The observed bias curve retains approximately 73%
at 5.25 V; this visual estimate is not a guaranteed minimum.

For a provisional screen, allocate 60% retention for DC bias, 80% for
initial tolerance, 85% for temperature, and 90% for aging:
four * 22 * 0.60 * 0.80 * 0.85 * 0.90 = 32.3136 uF effective.
This exceeds the 27 uF fixed-output criterion by 5.3136 uF (19.68%).
Three such capacitors give only 24.2352 uF and fail this screen.
The 10% aging allocation is a design assumption, not a manufacturer
guarantee. Combined temperature/bias behavior and low AC measurement
amplitude can invalidate independently multiplied allowances. Obtain
manufacturer bounds or validate effective capacitance in the assembled
application before release. Also qualify loop response, ripple current,
startup/inrush and load-step recovery; this arithmetic does not prove them.

[Live Mouser USA offer](https://www.mouser.com/en/ProductDetail/Samsung-Electro-Mechanics/CL32B226MOJNNNE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)
showed 1,363 available, MOQ1/multiple1, maximum order 610, cut tape
USD0.92/1 and 0.557/10. Factory lead time was 52 weeks, with possible
12% US tariff stated separately. Stock is unreserved and taxes/shipping
are excluded. Reel quantity 1000 is not purchase MOQ. Evaluate a second
source before production; stock today does not resolve longevity risk.

Native checkpoint relay024 confirms all four pin-1 terminals join U36
VOUT 7/8 and FB 5; all four pin-2 terminals join ground. Excluding this
bank, every earlier component pin partition is unchanged from relay023.
The C126-C129 quiet-rail drawing was reorganized into two compact banks
with grounds below the components; its net partitions and polarized
capacitor orientations are unchanged. BOM fidelity passes for 320 included
references, 19 columns and four native exclusions. All fifteen PDF pages
were reviewed; pages 1-14 render identically to the preceding checkpoint.
ERC remains 106 errors and 15 warnings; no findings were suppressed.
Clock arithmetic passes. The converter input and enable remain open.

## Input bulk checkpoint (2026-10-05)

C137/C138 are now native parallel 22 uF CL32B226MOJNNNE input bulk
capacitors. Both pin-1 terminals join U36 VIN 12/13 and both pin-2
terminals join ground. The same provisional allowances used above give
16.1568 uF combined; this is a sizing screen, not a guaranteed minimum.
Local high-frequency bypass selection, source impedance, input dips,
ripple/startup and combined bias/temperature/aging qualification remain
open. The bank remains HOLD with footprints deferred. U36 is not yet
connected to the system supply; EN and PG integration remain open.

relay025 netlist comparison proves every earlier component pin partition
unchanged. Native BOM export fidelity passes for 322 included references,
19 columns and four native exclusions. The updated 15-page PDF has been
rendered and page 15 visually inspected; pages 1-14 are pixel-identical
to relay024. ERC remains 106 errors and 15 warnings with no suppression
changes. Clock arithmetic passes. This checkpoint does not qualify the
converter or establish continuous output capability.
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

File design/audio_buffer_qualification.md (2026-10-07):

# BUF634A candidate: pin-map and parallel sharing investigation

2026-10-05. Bounded Stage 7 investigation for
[RA8HW-4](https://youtrack.locked.cv/issue/RA8HW-4).
**HOLD: no parallel power bank or output rating is qualified.**

The project-local `Audio_Devices:BUF634AIDRBR` is an unplaced native KiCad
candidate derived from bundled `Amplifier_Buffer:BUF634AxDRB`.
The exact ordering code is the DRB VSON package; its footprint is deliberately
blank pending mechanical qualification. Preserve upstream attribution in
`libs/symbols/KICAD_LIBRARY_LICENSE.md`.

## Pin evidence and integration contract

Authority: [TI BUF634A SBOS948F](https://www.ti.com/lit/ds/symlink/buf634a.pdf),
Rev F, page 3, Figure 6-2 and Table 6-1. All nine pads occur once.

| Pad | Function | KiCad model |
| --- | --- | --- |
| 1 | BW | Input; mode selection requires stability qualification. |
| 2, 5, 8 | NC, no internal connection | Three separate hidden no-connect pins retained from upstream. |
| 3 | VIN | Input, displayed with conventional subscript. |
| 4 | V- | Power input. |
| 6 | VO | Output; conventional triangle retains an unnamed output pin. |
| 7 | V+ | Power input. |
| 9 | Exposed thermal pad, V- | Power input, explicitly renamed V- from THPAD. |

Pad 9 heat-spreading copper must connect to V-, including when the rail is
negative relative to system ground. It is not a ground pad. Package/thermal
acceptance and assembled-board heat spreading remain open.

## What the four-buffer arithmetic does and does not establish

Four buffers per leg would ideally divide a 0.707107 A peak load into
176.777 mA each. The earlier 25% allowance would raise one to 220.971 mA.
That is an assumed allowance, not evidence that these devices actually share.

For an elementary linear screen, each branch is a common driven source plus
an independent offset `e_i`, with series resistance `r_i`. KCL gives:

```
v = (sum(e_i/r_i) - Iload) / sum(1/r_i)
I_i = (e_i - v) / r_i
```

With equal `r`, this reduces to `I_i = Iload/4 + (e_i - mean(e))/r`.
The shared composite feedback changes the common drive to correct the summed
output; it does not separately null the differences between branch offsets.
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

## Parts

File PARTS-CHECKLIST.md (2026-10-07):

# ereader_rev1 — Parts Checklist / BOM Tracker

Living candidate inventory, not an approved purchasing list. Library presence does not establish electrical suitability, availability, or footprint qualification. Parts live in shared functional libraries under `libs/symbols/`, `libs/footprints/`, and `libs/3dmodels/`; see `LIBRARY_STANDARDS.md`.

## Schematic-linked BOM and sourcing policy

The current placed-parts BOM is [exports/ereader_rev1_bom.csv](exports/ereader_rev1_bom.csv), exported through KiCad's Symbol Fields Table for the entire project. It includes all physical components, including capacitors, resistors, and switches. Unplaced library candidates below are not included in its quantities. The incomplete schematic is not ready to order.

Maintain manufacturer, exact ordering MPN, DigiKey and/or Mouser part number/link, procurement status, and dated supplier-specific stock/price snapshots in the schematic fields as each section is designed. Both distributors are in scope. Compare sources before flagging a part for replacement; one distributor's discontinuation is not manufacturer EOL. Export the CSV after changes using Tools > Generate Bill of Materials, entire project, with the procurement fields included. Output is `../exports/ereader_rev1_bom.csv` relative to the schematic directory. Do not hand-edit quantities in the generated CSV.

Export with **Group symbols disabled** to preserve each component's circuit
selection basis and sourcing snapshot. Equal value/MPN does not mean those
fields are identical. The 2026-10-04 export has 298 component rows and 19
columns, matching the saved 302-component netlist after excluding the four
internal copper-contact references J4 and TP1–TP3. The previous 123-group
export had the same 298 component references but merged differing selection
notes and sourcing snapshots; per-reference export preserves the native fields.
U26 is LIS2DTW12TR, R102/R103 are RC0603FR-073K3L, and U27–U33 are
included. C9's exact MPN and J1's physical connector remain unresolved; this
is not an approved ordering list.

Verify export fidelity against a freshly exported KiCad XML netlist with
`python scripts/check_bom_export.py <netlist.xml>`. This checks every exported
field and reference; it does not qualify parts or verify live stock.

Prefer active parts with substantial distributor-held stock, reasonable prototype and volume pricing, and adequate electrical margins. Record packaging and price breaks; do not confuse reel pricing with cut tape or marketplace stock with DigiKey inventory. Indexed stock is a dated indication, not a reservation or checkout verification. Recheck before ordering. Qualify voltage/current/temperature ratings, capacitor DC bias, regulator stability, oscillator matching, and interface compatibility before approving a selection. PCB footprint validation remains deferred.

Initial sourcing review, 2026-09-05:

- **U1 retain exact #UC0; sourcing HOLD removed:** The user's open Mouser search results were inspected directly in Edge on 2026-09-05. [Mouser's exact #UC0 part](https://www.mouser.com/en/ProductDetail/Renesas-Electronics/R7KA8P1KFLCACUC0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), `968-R7KA8P1KFLCACUC0`, showed 317 in stock, minimum/multiple 1, and USD unit prices 29.47 / 23.82 / 22.75 / 21.71 / 21.70 at quantities 1 / 10 / 25 / 100 / 189. Circuit qualification remains ongoing. [DigiKey's #UC0 listing](https://www.digikey.com/en/products/detail/renesas-electronics-corporation/R7KA8P1KFLCAC-UC0/26738126) still reports discontinued there, one in stock, and no backorders; retain that supplier-specific risk, not a design-wide unavailability claim. No suffix substitution is justified by that listing alone.
- **R1-R5 selected:** [Yageo RC0603FR-0710KL](https://www.yageogroup.com/component-documentation/download/specsheet/RC0603FR-0710KL), 10 kohm 1%, 0603, 100 mW at 70 C. At 3.6 V and the 9.9 kohm tolerance minimum, pull-down current is 0.364 mA and dissipation is 1.31 mW. [DigiKey `311-10.0KHRCT-ND`](https://www.digikey.com/en/products/detail/yageo/RC0603FR-0710KL/729827) indexed stock 2,922,248; active; cut-tape USD unit prices 0.10 / 0.025 / 0.01220 / 0.00661 at quantities 1 / 10 / 100 / 1000. Footprint qualification remains deferred.
- **L1 candidate:** [TDK SPM5020T-2R2M-LR](https://www.digikey.com/en/products/detail/tdk/SPM5020T-2R2M-LR/5962361), DigiKey `445-174497-1-ND`, indexed stock 1,149; cut-tape unit prices USD 1.35 / 1.111 / 0.9134 at quantities 1 / 10 / 100. Active, indicated 15-week lead time. Renesas reference recommendation supports selection, but system validation is still pending.
- **Main clock selected for schematic:** Y1 is Murata `XRCGB24M000F3M19R0`, replacing the imported FL2400022 instance. C35/C36 are TDK `C1005NP01H080D050BA`. Exact specifications, initial load calculation, and remaining board-level oscillator matching requirements are in [boot and debug](design/boot_and_debug.md). The BOM carries dated stock/pricing and links for both parts. Do not purchase the old FL2400022 for Y1.
- Remaining placed parts are explicitly marked TBD or HOLD until exact MPN sourcing and electrical qualification are completed. No fabricated total cost is reported while selections are incomplete.

Priority key: 🔴 essential · 🟡 blocked/pending a decision · 🟢 standard · ⚪ optional.

---

## ✅ In the library (imported candidates, not purchasing approval)
- [x] **Host MCU** — `R7KA8P1KFLCAC#UC0` (Renesas RA8P1, 289-pin BGA; M85+M33+Ethos-U55 NPU)
- [x] **Radio** — `ESP32-C6-WROOM-1-N8` (Wi-Fi6/BLE5.3/Thread; link to RA8 via SDIO/ESP-Hosted)
- [x] **SDRAM (framebuffer)** — `IME5132SDBETG-6I` (Intelligent Memory, 512 Mb 16M×32 SDR, on-die ECC, TSOP-II-86)
- [x] **Accelerometer / auto-rotate** — placed U26 is `LIS2DTW12TR`; see [sensor replacement](design/sensor_alternative.md). The imported ADXL367 and rejected LIS2DW12 are not the current U26 selection. Circuit qualification remains open.
  _(the 2 legacy RA8D2 symbols were dropped in the monorepo refactor)_

---

## 🔴 Power subsystem — *imported candidates; qualification pending*
- [x] **Li-ion charger (power-path)** — `BQ25188YBGR` (TI, 1 A single-cell, I²C, WLCSP-8) ✅ in library
- [x] **Fuel gauge** (2 in library — pick one) — `MAX17260SETD+T` (ADI ModelGauge m5, ⚠️ needs external **~10 mΩ shunt**) **or** `BQ27427YZFR` (TI, **integrated** sense resistor — no shunt)
- [x] **Main digital 3.3 V buck-boost candidate** - `Power_Devices:TPS63802DLA`, default exact MPN `TPS63802DLAR` (TI, nominal 2 A). Native symbol pin types and functional layout checked; circuit placement and qualification remain open. See [PWR-002/003](design/power_decoupling.md) for the precision divider, forced PWM, 1.65 A allocation and separate peripheral domains.
- [x] **1.8 V rail** — `TPS7A0218PYCHR` (TI fixed **1.8 V** LDO, 200 mA, 25 nA Iq, 4-DSBGA, fed from 3.3 V) ✅ in library
- [ ] **Battery connector** (+ protection IC if the cell has none)
- [x] **USB-C receptacle + ESD array** — `12401610E4#2A` (Amphenol USB-C 3.2 Gen2) + `RCLAMP0582N.TCT` (Semtech low-cap ESD) ✅ in library; ⚪ optional USB-PD controller
- [x] **Load switch** (power-gate the ESP32-C6) — `TPS22918TDBVRQ1` (TI, 2 A, SOT-23-6) ✅ in library

## 🟡 Display subsystem — *blocked on picking the e-ink panel (heart of the reader)*
- [ ] **E-ink panel** — NOT chosen yet (own future decision; see project notes)
- [ ] **IT8951 e-paper controller** - integrate on this PCB; exact variant and supporting circuitry pending. Waveshare driver board is prototype-only.
- [ ] **EPD power PMIC** - integrate panel HV and VCOM generation on this PCB; qualify candidate against the selected panel, sequencing and current requirements.
- [ ] **FPC connector(s)** for panel (+ touch)
- [ ] **Capacitive touch controller** (I²C) — GT911 / FT5x06 (if touchscreen)

## 🔴 Storage & code memory
- [x] **QSPI NOR flash** (firmware + fonts + OCR model) — `IS25LP01GJ-RHLE` (ISSI, **1 Gbit / 128 MB**, Quad-DTR 166 MHz, 3.3 V, 36 mA, 24-TFBGA) ✅ in library
- [x] **User book storage** — `DM3AT-SF-PEJM5` (Hirose microSD socket, push-push + card-detect, SMT) ✅ in library
- [x] **Internal data storage** — `MX35LF1G24AD-Z4I-T` (Macronix SPI-NAND, **128 MB**, Quad, on-die ECC, **3.3 V**, WSON-8) → default books + persistent cache ✅ in library
- [x] **SD ESD array** — `TPD6E004RSER` (TI, 6-channel, 0.5 pF low-cap, ±15 kV, UQFN-8) on the microSD lines ✅ in library

## 🟡 Front light — *defining reader feature*
- [ ] **LED driver circuitry** - independently adjustable warm and cool front-light channels are required; qualify driver and LED topology against the selected panel assembly.

## 🔴 Clocks
- [x] **Main crystal** — placed Y1 is `XRCGB24M000F3M19R0`; FL2400022 is an older imported candidate.
- [x] **32.768 kHz RTC crystal** — placed Y2 is `ABS07-LR-32.768KHZ-6-1-T`; see [clock qualification](design/boot_and_debug.md). The older imported 12.5 pF variant is not the fitted selection.

## 🟢 Input & debug
- [ ] **Power/reset button** + page-turn tactile buttons
- [ ] **SWD debug header** (Tag-Connect or 2×5)

## Sensors and required audio
- [x] **Ambient light sensor** — placed U32 `OPT4001DTSR`; see [ambient-light integration](design/ambient_light.md) for remaining qualification.
- [x] **Hall sensor** — placed U33 `DRV5032FADBZR`; see [cover sensor](design/hall_cover.md) for remaining qualification.
- [ ] **Audio** — required premium 3.5 mm and 4.4 mm headphone outputs, USB-DAC operation and built-in speakers. Integration remains unfinished; see [audio design](design/audio_subsystem.md).

---

## Notes
- **Power + clock reference:** consult `resources/manuals/Renesas_EK-RA8D2_Board_BOM.xlsx`, but verify regulators, crystals, decoupling and pin compatibility against the exact RA8P1 ordering code. The RA8D2 reference does not guarantee compatibility.
- **Urgent gaps:** power-chain and oscillator qualification, and the display subsystem's exact panel/controller requirements. MCU sourcing is available through Mouser; monitor replenishment for production quantities.
- Every new physical part: qualify its electrical role and DigiKey sourcing, maintain the schematic procurement fields and exported BOM, and import necessary library assets per `LIBRARY_STANDARDS.md`. Checking off a library import is not purchasing approval.

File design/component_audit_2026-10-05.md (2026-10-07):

# Component audit - 2026-10-05

The saved schematic contains **305 included physical references, 79 selected ordering codes, and two unresolved references (C9 and J1)**. All are enumerated below. Four native copper contacts, J4 and TP1-TP3, are excluded from purchases. The 26 unplaced library symbols are separately classified so historical parts cannot silently return to the BOM.

**This is not a purchase-ready or manufacturing-approved BOM.** Four sourcing/value corrections have been applied in native KiCad. Lifecycle transitions, released specifications, weak stock evidence and circuit qualification remain open where stated. Manufacturer Active/Production status means currently offered; it does not promise that a part will remain available for years. An explicit published longevity commitment is reported only where found. Newer release dates alone do not make a part better.

Research prioritizes manufacturer documents and exact order-code status, then distributor quantity-one offers. The observation date is October 5, 2026; the source-age column preserves older indexed evidence. Cached quantities are not live checkout confirmation. Prices are USD at one piece unless otherwise stated, excluding taxes, freight, tariffs and custom-reel charges. **TR in an MPN or a factory pack of 2000/10000 does not itself establish a minimum order:** distributor cut tape, tube and tray can be sold one piece at a time. Choose cut tape rather than paying a reeling fee for a prototype.

The machine-readable [audit](component_audit_2026-10-05.json) retains source links, manufacturer/distributor status, price, packaging, source age and electrical/value rationale for every row. [Native BOM](../exports/ereader_rev1_bom.csv) retains the complete selection basis for each individual reference. Existing historical sourcing fields remain historical; the audit is the newer sourcing evidence except where replacement fields were updated.

## Applied native replacements

| Reference | Previous ordering code | Current candidate | Reason and remaining gate |
| --- | --- | --- | --- |
| U14 | IS42S32160F-7TLI | AS4C16M32SC-7TIN | Old exact code has distributor Discontinued/owner-reported Mouser NRND. Alliance offers the same 64 MiB x32, industrial TSOP-86 interface, quantity-one tray. All 86 package pins and every existing net membership were preserved. Public September 2018 Rev 1.0 is **PRELIMINARY**: released specifications/manufacturer confirmation, startup, timing, SI, refresh, power and footprint remain HOLD. This replacement removes reliance on the old source but is not yet a fully qualified production choice. |
| R33 | RT0603BRD07100KL | TNPW0603100KBEEA | Old selected distributor stock unavailable. Preserves 100 kohm, 0.1%, 25 ppm/K, 0603 source-supervisor divider; $0.26 quantity-one CT, 65,460 listed. Existing 3.263705831..3.476597632 V source-trip calculation is unchanged. |
| C95 | C1608C0G1H103J080AA | GRM1885C1H103JA01D | TDK still has production evidence but distributor stock was unavailable. Murata keeps 10 nF, 5%, C0G, 50 V, 0603 reset timing; $0.13 CT, 395,362 listed. Exact approval sheet, leakage, placement and startup qualification remain open. The linked manufacturer typical-spec summary is not a final approved specification. |
| C125 | CC0603KRX7R9BB224 | C1608X7R1H224K080AB | Hall bypass keeps 220 nF, 10%, X7R, 50 V, 0603 and consolidates with 12 existing references. Quantity-one price falls from $1.23 to $0.17. Effective capacitance must still exceed the Hall sensor's 100 nF requirement under bias, temperature and aging. |

Replacement source links are in the individual entries below. No wiring or value changes were necessary for these four substitutions. Old library assets remain archived for provenance; they are not approved alternatives.

## Additional native electrical correction

SERVICE-025 changes R110/R111 from 10k to 1k, using an existing active
quantity-one USD 0.10 BOM MPN. The parallel discharge improves the conditional
60 uA off-state screen from 306.03 mV to 30.603 mV; fixture loading rises
to 7.071 mA maximum. See [service review](service_interface.md#service-025-stronger-native-fixture-rail-discharge-2026-10-05).
Actual leakage, storage and sequencing remain HOLD. The fixture contract
now requires at least 20 mA; no adapter has been qualified.

## Priority findings and engineering decisions

### Supplier refresh in this continuation

Thirty-seven source rows were refreshed after the initial audit: 36 direct
supplier retrievals dated October 5 and one last-month T521 page, whose age
remains explicit. Original quantities/prices are retained in each JSON row's
`source_history`. Native sourcing snapshots and per-reference selection
calculations remain historical; no electrical or BOM change was made during
this refresh.

- **C43/C46/C47/C73/C88/C92/C102:** DigiKey now lists 55,220 of
  C3216X7R1V106K160AC, $0.68 quantity-one cut tape. That covers the seven
  installed uses; the prior zero-stock source hold is resolved at the listing
  level. Mouser's freshly retrieved page instead lists zero, so the older
  indexed Mouser stock must not guide this purchase.
- **R42:** DigiKey now lists zero RG2012L-102-L-T05, $3.45 on backorder.
  Mouser's indexed yesterday offer lists 1,560, $3.66 quantity-one cut tape;
  direct retrieval failed. This is an explicit source hold until that exact
  offer is refreshed. Do not relax 0.01%/2 ppm/K to fix availability without
  recomputing the main rail's upper limit.
- **C115 and L1:** fresh DigiKey counts are 250 and 144, respectively, lower
  than the earlier 9,260 and 1,149. Both still cover a prototype; these counts
  do not establish reliable replenishment.
- **U1/U4 and the 74 common 100 nF capacitors:** the weak primary sources
  remain unchanged: one discontinued-at-DigiKey MCU, four radio switches,
  and four capacitors. Indexed Mouser stock for the capacitors is insufficient
  evidence of live availability for all 74 positions. Failed retrieval is
  recorded as uncertainty, not converted into zero stock or a passed check.

Alliance's [published longevity policy](https://www.alliancememory.com/about/)
states 7-10 years **from launch for many products**. It does not identify
AS4C16M32SC-7TIN's inclusion or commitment end date. Its September 2018
preliminary datasheet date is not proof of launch date, and the policy cannot
be read as another 7-10 years from today. U14's remaining-life and released
specification gates stay open.

Direct listing references are in the individual rows below. The
[Mouser R42 offer](https://www.mouser.com/en/c/passive-components/resistors/film-resistors/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)
remains indexed evidence only.

### Retained engineering decisions

1. **U1 ordering-code transition:** Renesas lists both R7KA8P1KFLCAC#UC0 and #UC1 Active and recommends #UC1 as replacement. DigiKey labels #UC0 Discontinued with one piece/no backorders; older Mouser and manufacturer-aggregator quantities are not refreshed checkout stock. The #UC1 manufacturer offer found has MOQ 189, not one. Retain native #UC0 until the PCN, packing/die revision, balls, errata and distributor quantity-one #UC1 availability are established. Do not silently substitute the archived 224-ball processor. [UC0](https://www.renesas.com/en/products/ra8p1/part-details/r7ka8p1kflcac-uc0), [UC1](https://www.renesas.com/en/products/ra8p1/part-details/r7ka8p1kflcac-uc1).
2. **U14 longevity/specification and price:** Alliance's current product page and reviewed SDRAM EOL list contain no retirement of this selected SC code, but neither guarantees remaining lifetime. Its manufacturer-linked ShopMemory page shows $19.20 at qty 1..107, with stock not established; DigiKey lists $43.60 and 175. Older Mouser evidence was $32.99/29 pieces and could not be refreshed. Confirm the authorized primary offer before paying the premium. A newer AS4C16M32SB-6BCN alternative changes to commercial BGA-90 and documents much higher self-refresh current (60 mA versus SC 5 mA), so it is not an automatic improvement for this portable device. [Alliance product](https://www.alliancememory.com/as4c16m32sc/), [EOL list](https://www.alliancememory.com/product/eol-sdram/), [manufacturer-linked store](https://www.shopmemory.com/product/as4c16m32sc-7tin/).
3. **U13 continuous-load and thermal HOLD:** The placed part is TPS63806YFFR, not archived TPS63802. TI's 2.5 A output headline is transient; its typical 5.5 A switch limit is not a continuous output rating. The incomplete 2.095 A main-rail allocation, at 3.393012496197 V, 3.2 V input and assumed 75% efficiency, requires 2.961817158 A input and dissipates 2.369453727 W in conversion. Close low-battery, hot enclosure, switch/inductor limits and the expanded camera/display/audio budget before retaining or changing the regulator. Input maximum is 5.5 V: negotiated 15/20 V PD cannot feed it directly. The earlier LTC3119 replacement was driven by the tight rail upper-voltage requirement; returning to the $24.07 part without closing that conflict is not justified. [TI TPS63806](https://www.ti.com/product/TPS63806), [current circuit study](main_regulator_tps63806.md).
4. **U23 price review:** ADI recommends LT3042 for new designs; its exact IMSE options are Production. A distributor stopping replenishment is not manufacturer EOL. The ~$9.12 MIPI LDO has no demonstrated requirement yet for its ultra-low noise. TPS7A2018PDBVR (300 mA; indexed 45,221, $0.37 qty-one CT) or TPS7A0218PYCHR (200 mA, much lower idle current, tiny DSBGA) merit evaluation. Neither is qualified for this rail's noise, sequencing, reverse behavior, enable/defaults or package. Preserve the present conservative **13 mA full-load IQ allocation**; the 2 mA nominal IQ does not justify reducing a worst-case budget. [ADI](https://www.analog.com/en/products/lt3042.html), [TI alternative](https://www.ti.com/product/TPS7A20), [quantity-one offer](https://www.digikey.com/en/products/detail/texas-instruments/TPS7A2018PDBVR/13566855).
5. **U4 fragile stock:** Only four TPS22964CYZPT were listed. Cut tape avoids the reel minimum but this is a weak replenishment position. Same-family YZPR had zero immediate stock in the reviewed offer. TPS22964C2 and FPF1048BUCX are comparison candidates, not substitutes: review shutdown reverse blocking, discharge, control thresholds, sequencing and package first. Reverse blocking on the present part occurs when disabled; it is not an always-on battery power-path controller.
6. **High-count passives:** DigiKey's four C1608X7R1H104K080AA cannot cover the 74 placed uses; its quantity-one price does not fix that. Mouser indexed quantity-one stock exists but needs live refresh. The seven C3216X7R1V106K160AC now have a refreshed DigiKey stock listing of 55,220, quantity-one CT at $0.68; their primary source hold is resolved at listing level. Their electrical qualification is unchanged. The quantity-one source table preserves both offers and their ages.
7. **Precision resistors:** R41/R42 cost ~$2.18/$3.66 because the present SDRAM rail upper limit depends on their small tolerance/drift. R12/R67 with R13/R74 set a 3.019..3.113 V supervisor corner. Replacing these with generic 1% resistors purely on price would invalidate those budgets. The 0.1% 30-ohm RT parts cost the same ~$0.10 as ordinary RC parts; simplification can follow SI review without a claimed large saving. Ordinary pulls/series resistors do not require boutique parts.
8. **Audio candidate limitations:** The OPA1656 controller is not rail-to-rail input. The portable bank study now investigates +/-6 V instead of +/-5 V; full-bank typical idle is 2.568 W and a stated optimistic 32-ohm portable screen yields only ~2.01 hours from an assumed 17.76 Wh usable pack. This is a serious portable heat/runtime concern, not evidence that more expensive op-amps solve it. Keep the quiet path separate and the bank off during quiet listening. Composite stability, hot SOA, sharing, protection and sealed-enclosure continuous power remain HOLD. [Rail correction](audio_composite_rails.md).
9. **Environmental constraints:** EVQP7 buttons are -20..70 C and unsealed, the Pcam FFC/socket is not an ingress barrier, and ordinary USB/SD/audio connectors need enclosure/seal integration. ESD441 is not moisture sensing and its 5.5 V standoff cannot protect a 15/20 V PD power line. Wet-port inhibition and independent headphone DC/fault disconnect remain unfinished hardware.

## Electrical and value review by reference

Every selected ordering code below has a sourcing, lifecycle and fit/value entry. Grouped rows cover all listed references; their individual native Selection_Basis remains authoritative for differing uses of the same resistor or capacitor. The reviews screen suitability but do not claim completed tests.

- X7R MLCCs: nominal capacitance alone is insufficient. Preserve voltage, temperature, tolerance, DC-bias/aging, effective capacitance, inrush, ESR/loop stability and package-height requirements. C0G crystal/timer/SET capacitors are not interchangeable with X7R based on nominal value.
- R76: the 2.21 kohm microSD limiter study produces conditional 0.38/0.50/0.62 A limits; verify inrush, card load and switch fault SOA. R82 is the 330-ohm card discharge. R83-R88 are 33-ohm SD series values pending SI; R43 zero-ohm CLK is a tuning placeholder, not a terminated bus.
- R102/R103: 3.3 kohm I2C pulls produce conditional 62.9..219 ns rise times and ~1.12 mA sink demand. Bus capacitance, pins, partial-power leakage and clock settings remain gates. Other pulls retain their per-reference rise/fall/leakage and truth-table budgets.
- R31/R39/R40: 2512 nominal 1 W is not a hot-enclosure pulse/fault rating. R95 18 kohm 0.1%/25 ppm sets the MIPI rail screen at 1.754..1.846 V. Main-rail divider R41/R42/R66 remains nominal 3.272 V with maximum 3.393 V under the stated tolerances.
- L1: 2.2 uH, 37/40.7 milliohm typical/maximum DCR at 25 C; typical 7 A at 30% inductance drop and 4.6 A at 40 C rise are different limits, not guaranteed hot operation. L2: 0.47 uH, 3.7/4.3 milliohm typical/maximum DCR; 6.4 A at 10% drop is not the 15.7 A 30% drop rating. Verify hot ripple/saturation/copper loss and loop behavior.
- T491 reservoir capacitors retain the existing conditional 641.52 uF minimum bank budget; MnO2 surge/short behavior, leakage, ESR and charge limits need closure before considering polymer substitutes. Quiet T521 capacitors require correct negative-rail polarity, reverse-voltage limits, ripple and regulator stability; the listed 43-week factory lead time is a replenishment risk despite distributor stock.
- ESP32-C6 is retained as radio, not the USB audio/player processor. It lacks Classic Bluetooth A2DP and its native USB serial interface is not a high-speed UAC2 engine. LIS2DTW12 is an orientation accelerometer plus temperature, not a six-axis gyro IMU. These are role limitations, not reasons to discard working requirements blindly.

## Complete placed-part source screen

CT means cut tape; qty-one tray/tube is also acceptable. All circuit and footprint release gates remain open unless a particular completed check is named. Source ages below refer to the page evidence, not an inventory reservation.

### 1. UNSELECTED - C9

Manufacturer lifecycle evidence: UNSELECTED.

Sourcing: **DigiKey; listed stock UNVERIFIED; UNVERIFIED/1; UNVERIFIED; UNVERIFIED.** Source age: UNVERIFIED.

Role and existing limits: Candidate: Murata GRM32ER71A476KE15K, 47uF +/-10%, 10V X7R 1210. Murata GRM32ER71A476KE15-04CA (2025-01-10). HOLD pending DC-bias/aging and RA8P1 core-loop qualification; see design/core_bulk_c9.md.

Fit/qualification screen: Core47uFcandidate MurataGRM32ER71A476KE15K not selected; effectiveC/bias/aging/loop HOLD. Price/alternative review: No selected price; not purchasable.

### 2. 1-1734248-5 - J3

Manufacturer lifecycle evidence: TE drawing; distributor Active, manufacturer horizon unconfirmed.

Sourcing: **DigiKey; listed stock 22,650; $1.49/1; CT / optional reel; MOQ 1 offer observed; refresh before purchase.** Source age: today.

Role and existing limits: CMS-014: matches Digilent Zybo Z7 D.1 J2 and Pcam 5C pinout. Wurth 686715100001 cable maps host n to module n; 15 contacts, 1mm pitch, 0.30mm flex. Footprint qualification deferred. See ../design/camera_storage_interfaces.md.

Fit/qualification screen: Pcam cable/pinout15x1mm0.30mm matches; -20..85C SI/mating HOLD. Price/alternative review: $1.49 reasonable; alternate must match contact side.

Sources: [Manufacturer evidence](https://www.te.com/commerce/DocumentDelivery/DDEController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), [DigiKey offer](https://www.digikey.com/en/products/detail/te-connectivity-amp-connectors/1-1734248-5/2272380).

### 3. 74LVC1G14GW,125 - U12

Manufacturer lifecycle evidence: Nexperia current product; DigiKey Active.

Sourcing: **DigiKey; listed stock 265,269; $0.10/1; CT / optional reel; MOQ 1 offer observed; refresh before purchase.** Source age: today.

Role and existing limits: SYS-007 / PWR-004: 2.7..4.6V held-domain inverter; 1uA input leakage. Four 1k/1M gate branches include future USB clear: peak <=18.773595mA, steady <=22.773595uA, VGS>=2.596278V. Local100n bypass; shared10ms settling and500uA non-rail-input current allocation require qualification. See ../design/main_regulator_ltc3119.md.

Fit/qualification screen: Schmitt held-domain inverter; sub1.65V/ramp/leak HOLD. Price/alternative review: $0.10; no price issue.

Sources: [Manufacturer evidence](https://www.nexperia.com/product/74LVC1G14GW), [DigiKey offer](https://www.digikey.com/en/products/detail/nexperia-usa-inc/74LVC1G14GW-125/946729), [Specification reference](https://assets.nexperia.com/documents/data-sheet/74LVC1G14.pdf).

### 4. 74LVC1G17GW,125 - U16

Manufacturer lifecycle evidence: Nexperia current product; DigiKey Active.

Sourcing: **DigiKey; listed stock 28,878; $0.10/1; CT / optional reel; MOQ 1 offer observed; refresh before purchase.** Source age: today.

Role and existing limits: PWR-006: SYS_AON raw-powered EN buffer with partial-power-down Ioff. Separate held-domain Q3 clamp covers undefined sub-1.65V supply behavior. Full EN calculations: design/main_regulator_tps63806.md.

Fit/qualification screen: Ioff ENbuffer; held Q3 handles raw sub1.65V undefined behavior. Price/alternative review: $0.10; no price issue.

Sources: [Manufacturer evidence](https://www.nexperia.com/product/74LVC1G17GW), [DigiKey offer](https://www.digikey.com/en/products/detail/nexperia-usa-inc/74LVC1G17GW-125/1965408), [Specification reference](https://assets.nexperia.com/documents/data-sheet/74LVC1G17.pdf).

### 5. ABS07-LR-32.768KHZ-6-1-T - Y2

Manufacturer lifecycle evidence: Abracon current datasheet; DigiKey Active; exact horizon unconfirmed.

Sourcing: **DigiKey; listed stock 8,268; $1.48/1; CT / optional reel; MOQ 1 offer observed; refresh before purchase.** Source age: today.

Role and existing limits: CL6pF +/-10ppm; ESR50kohm max at25C; drive0.5uW max; CLK-002

Fit/qualification screen: 6pF50kohm0.5uW RTC; boardstartup/stray HOLD. Price/alternative review: $1.48 justified lowESR10ppm;12.5pFarchive not substitute.

Sources: [Manufacturer evidence](https://abracon.com/Resonators/ABS07-LR.pdf), [DigiKey offer](https://www.digikey.com/en/products/detail/abracon-llc/ABS07-LR-32-768KHZ-6-1-T/5231514).

### 6. BLM18PG121SN1D - FB1

Manufacturer lifecycle evidence: Murata family specification; DigiKey Active; exact mfr lifecycle unconfirmed.

Sourcing: **DigiKey; listed stock 523,412; $0.14/1; CT / optional reel; MOQ 1 offer observed; refresh before purchase.** Source age: today.

Role and existing limits: USB-004: 120 ohm +/-25% at 100MHz; DCR max 0.05 ohm initial/0.10 after testing; rated 2A at 85C, 1A at 125C.

Fit/qualification screen: USBlocal filter2A85C/1A125C; bias/resonance/drop HOLD; notPDwholeinput. Price/alternative review: $0.14 reasonable.

Sources: [Manufacturer evidence](https://pim.murata.com/asset/pim4/ferriteBeadInductortypefilter/ENFA0003_PDF_FERRITEBEADINDUCTORTYPEFILTER), [DigiKey offer](https://www.digikey.com/en/products/detail/murata-electronics/BLM18PG121SN1D/584248).

### 7. C1005NP01H040C050BA - C37 C38

Manufacturer lifecycle evidence: TDKexact code Production direct/indexedprimary; future production horizon unconfirmed.

Sourcing: **DigiKey; listed stock 7,245; $0.11/1; CT / optional reel; MOQ 1 offer observed; refresh before purchase.** Source age: today.

Role and existing limits: 4pF +/-0.25pF NP0 50V; RTC initial matching; CLK-002; stray unmeasured

Fit/qualification screen: StableC0G/NP0timing/filter/crystal;leak/tolerance/stray/startup HOLD. Price/alternative review: StandardMLCCprice; dielectric/effectiveC/package must matchalternates.

Sources: [Manufacturer evidence](https://product.tdk.com/en/search/capacitor/ceramic/mlcc/info?part_no=C1005NP01H040C050BA), [DigiKey offer](https://www.digikey.com/en/products/detail/tdk/C1005NP01H040C050BA/3955443).

### 8. C1005NP01H080D050BA - C35 C36

Manufacturer lifecycle evidence: TDKexact code Production direct/indexedprimary; future production horizon unconfirmed.

Sourcing: **DigiKey; listed stock 73,246; $0.11/1; CT / optional reel; MOQ 1 offer observed; refresh before purchase.** Source age: today.

Role and existing limits: 8pF +/-0.5pF, 50V NP0, 0402. Initial load network per RA8P1 Group10; 8pF/2 + estimated 2pF stray = 6pF. Board matching required.

Fit/qualification screen: StableC0G/NP0timing/filter/crystal;leak/tolerance/stray/startup HOLD. Price/alternative review: StandardMLCCprice; dielectric/effectiveC/package must matchalternates.

Sources: [Manufacturer evidence](https://product.tdk.com/en/search/capacitor/ceramic/mlcc/info?part_no=C1005NP01H080D050BA), [DigiKey offer](https://www.digikey.com/en/products/detail/tdk/C1005NP01H080D050BA/3951017).

### 9. GRM1885C1H103JA01D - C95

Manufacturer lifecycle evidence: Murata base InProduction SimSurfing; exactDpacking distributorActive; no future guarantee.

Sourcing: **DigiKey; listed stock 395,362; $0.13/1; Qty1 cut tape; MOQ 1 offer observed; refresh before purchase.** Source age: today.

Role and existing limits: RST-002 value/tolerance/TC unchanged; oldTDKproduction butzeroDK/Mouserstock.

Fit/qualification screen: 10nF5%C0G30ppm/C50V0603 keeps reset timercorners; CTleakage/startup and exactapprovalsheet/footprint HOLD. Linked2015Murata typicalspecsummary is not finalapprovedspec. Price/alternative review: $0.13 practicalreplacementzero-stockTDK;stableC0Grequired notcheapX7R.

Sources: [Manufacturer evidence](https://ds.murata.co.jp/simsurfing/mlcc.html?partnumbers=%5B%22GRM1885C1H103JA01%22%5D), [DigiKey offer](https://www.digikey.com/en/products/detail/murata-electronics/GRM1885C1H103JA01D/4421555), [Specification reference](https://www.farnell.com/datasheets/2048016.pdf).

### 10. C1608NP01H102J080AA - C52 C68

Manufacturer lifecycle evidence: TDK Meister 2025.12 primary indexed exact code Production; live page unavailable.

Sourcing: **DigiKey; listed stock 26,851; $0.22/1; Qty-one cut tape; optional full reel and reeling fees excluded; Quantity-one price observed; stock must cover board quantity; recheck before buying.** Source age: today; direct supplier retrieval 2026-10-05.

Role and existing limits: RADIO-012: U6 CT-to-GND, 1nF NP0 50V +/-5%, +/-30ppm/C. Nominal delay = C*1.23V/1.15uA + 25us. Charge-time corner screen includes capacitor tolerance, 100C excursion and allocated 10nA leakage; full sequencing remains open.

Fit/qualification screen: StableC0G/NP0timing/filter/crystal;leak/tolerance/stray/startup HOLD. Price/alternative review: StandardMLCCprice; dielectric/effectiveC/package must matchalternates.

Sources: [Manufacturer evidence](https://product.tdk.com/en/search/capacitor/ceramic/mlcc/info?part_no=C1608NP01H102J080AA), [DigiKey offer](https://www.digikey.com/en/products/detail/tdk/C1608NP01H102J080AA/3955721).

### 11. C1608X7R1H103K080AA - C41

Manufacturer lifecycle evidence: TDKexact code Production direct/indexedprimary; future production horizon unconfirmed.

Sourcing: **DigiKey; listed stock 615,640; $0.10/1; CT / optional reel; MOQ 1 offer observed; refresh before purchase.** Source age: today.

Role and existing limits: Renesas QDG Table 1 p.6: 10 nF ceramic at U1.H15. 50 V X7R +/-10%; initial 9..11 nF. USB-003.

Fit/qualification screen: X7Rbypass; effectiveCunderbias/temp/aging,ESR/startup/inrush/loop HOLD. Price/alternative review: StandardMLCCprice; dielectric/effectiveC/package must matchalternates.

Sources: [Manufacturer evidence](https://product.tdk.com/en/search/capacitor/ceramic/mlcc/info?part_no=C1608X7R1H103K080AA), [DigiKey offer](https://www.digikey.com/en/products/detail/tdk/C1608X7R1H103K080AA/567691).

### 12. C1608X7R1H104K080AA - C6 C16 C17 C18 C19 C20 C21 C22 C23 C24 C25 C26 C27 C28 C29 C30 C31 C32 C33 C34 C39 C40 C44 C45 C48 C49 C50 C51 C53 C54 C55 C56 C58 C59 C60 C61 C62 C67 C72 C76 C77 C78 C79 C80 C81 C82 C83 C84 C85 C86 C87 C89 C90 C91 C93 C97 C98 C101 C104 C105 C106 C107 C111 C112 C113 C114 C116 C119 C120 C121 C122 C123 C126 C127

Manufacturer lifecycle evidence: TDKexact code Production direct/indexedprimary; future production horizon unconfirmed.

Sourcing: **DigiKey; listed stock 4; $0.11/1; Qty-one cut tape; optional full reel and reeling fees excluded; Quantity-one price observed; stock must cover board quantity; recheck before buying.** Source age: today; direct supplier retrieval 2026-10-05.

Role and existing limits: 100 nF +/-10%, 50 V X7R. +3V3_MCU bypass. TDK nominal DC-bias curve: interpolated 99.45 nF at 3.3 V; reference data, not guaranteed minimum. See PWR-001 design/power_decoupling.md.

Fit/qualification screen: X7Rbypass; effectiveCunderbias/temp/aging,ESR/startup/inrush/loop HOLD. Price/alternative review: StandardMLCCprice; dielectric/effectiveC/package must matchalternates.

Sources: [Manufacturer evidence](https://product.tdk.com/en/search/capacitor/ceramic/mlcc/info?part_no=C1608X7R1H104K080AA), [DigiKey offer](https://www.digikey.com/en/products/detail/tdk-corporation/C1608X7R1H104K080AA/513811).

Alternate sourcing evidence: [Mouser](https://www.mouser.com/en/ProductDetail/TDK/C1608X7R1H104K080AA?qs=NRhsANhppD8dEJli2CDBHA%3D%3D), 1,189,609 listed, $0.11/1, MOQ 1 cut tape; factory reel 4000 is not MOQ; indexed 4 weeks ago; live checkout unverified. **Live source refresh remains HOLD.**

### 13. C1608X7R1H224K080AB - C1 C2 C4 C5 C7 C8 C10 C11 C12 C13 C14 C15 C125

Manufacturer lifecycle evidence: TDKexact code Production direct/indexedprimary; future production horizon unconfirmed.

Sourcing: **DigiKey; listed stock 1,334; $0.17/1; Qty-one cut tape; optional full reel and reeling fees excluded; Quantity-one price observed; stock must cover board quantity; recheck before buying.** Source age: today; direct supplier retrieval 2026-10-05.

Role and existing limits: PWR-005: 220nF at each VCL/VSS pair per Renesas QDG Rev1.10 section1.2; TDK 50V X7R +/-10% production part. Nominal bias curve only; PDN qualification remains open. C125 consolidation replacesYAGEO220n50V10%X7R;Hallrequires>=100nFeffective;bias/aging/temp qualificationopen; $1.23->$0.17.

Fit/qualification screen: X7Rbypass; effectiveCunderbias/temp/aging,ESR/startup/inrush/loop HOLD. Price/alternative review: StandardMLCCprice; dielectric/effectiveC/package must matchalternates.

Sources: [Manufacturer evidence](https://product.tdk.com/en/search/capacitor/ceramic/mlcc/info?part_no=C1608X7R1H224K080AB), [DigiKey offer](https://www.digikey.com/en/products/detail/tdk-corporation/C1608X7R1H224K080AB/2732843).

### 14. C2012X7R1E105K125AB - C57

Manufacturer lifecycle evidence: TDKexact code Production direct/indexedprimary; future production horizon unconfirmed.

Sourcing: **DigiKey; listed stock 209,557; $0.23/1; Qty-one cut tape; optional full reel and reeling fees excluded; Quantity-one price observed; stock must cover board quantity; recheck before buying.** Source age: today; direct supplier retrieval 2026-10-05.

Role and existing limits: BTN-004: t_force_nom = 65ms + C[uF]/1.56e-4 = 6475.256ms. C tolerance/temp-only 0.765..1.265uF -> 4.969..8.174s with nominal IC equation; excludes IC spread, DC bias, aging and leakage. Full Python-checked math: ../design/single_button_power.md.

Fit/qualification screen: X7Rbypass; effectiveCunderbias/temp/aging,ESR/startup/inrush/loop HOLD. Price/alternative review: StandardMLCCprice; dielectric/effectiveC/package must matchalternates.

Sources: [Manufacturer evidence](https://product.tdk.com/en/search/capacitor/ceramic/mlcc/info?part_no=C2012X7R1E105K125AB), [DigiKey offer](https://www.digikey.com/en/products/detail/tdk/C2012X7R1E105K125AB/513887).
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

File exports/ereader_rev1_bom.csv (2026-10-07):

Reference | Qty | Value | DNP | Exclude from BOM | Exclude from Board | Footprint | Datasheet | Manufacturer_Name | Manufacturer_Part_Number | Mouser Part Number | Mouser Price/Stock | Selection_Basis | Description | DigiKey_Part_Number | DigiKey_URL | Procurement_Status | Sourcing_Snapshot | Mouser_URL
C1 | 1 | 220n |  |  |  |  | https://product.tdk.com/en/search/capacitor/ceramic/mlcc/info?part_no=C1608X7R1H224K080AB | TDK | C1608X7R1H224K080AB |  |  | PWR-005: 220nF at each VCL/VSS pair per Renesas QDG Rev1.10 section1.2; TDK 50V X7R +/-10% production part. Nominal bias curve only; PDN qualification remains open. |  | 445-7408-1-ND | https://www.digikey.com/en/products/detail/tdk-corporation/C1608X7R1H224K080AB/2732843 | Selected for prototype VCL bypass; PWR-005. PCB/PDN qualification deferred. | 2026-09-08 DigiKey: 82010 in stock; USD0.17/0.098/0.06030 at qty1/10/100; 24wk; unreserved. TDK Production.
C2 | 1 | 220n |  |  |  |  | https://product.tdk.com/en/search/capacitor/ceramic/mlcc/info?part_no=C1608X7R1H224K080AB | TDK | C1608X7R1H224K080AB |  |  | PWR-005: 220nF at each VCL/VSS pair per Renesas QDG Rev1.10 section1.2; TDK 50V X7R +/-10% production part. Nominal bias curve only; PDN qualification remains open. |  | 445-7408-1-ND | https://www.digikey.com/en/products/detail/tdk-corporation/C1608X7R1H224K080AB/2732843 | Selected for prototype VCL bypass; PWR-005. PCB/PDN qualification deferred. | 2026-09-08 DigiKey: 82010 in stock; USD0.17/0.098/0.06030 at qty1/10/100; 24wk; unreserved. TDK Production.
C3 | 1 | 22u |  |  |  |  | https://search.murata.co.jp/Ceramy/image/img/A01X/G101/ENG/GRM31CR70J226KE19-01CA.pdf | Murata Electronics | GRM31CR70J226KE19L |  |  | Renesas Quick Design Guide Table3 recommended family; 22uF +/-10% 6.3V X7R; effective capacitance and lifecycle approval pending |  | 490-6515-1-ND | https://www.digikey.com/en/products/detail/murata-electronics/GRM31CR70J226KE19L/3845712 | Candidate - validate DC bias, temperature and lifecycle before release | 2026-09-05 DigiKey indexed stock110912; Active;17wk;USD1:1.00,10:0.636,100:0.4468
C4 | 1 | 220n |  |  |  |  | https://product.tdk.com/en/search/capacitor/ceramic/mlcc/info?part_no=C1608X7R1H224K080AB | TDK | C1608X7R1H224K080AB |  |  | PWR-005: 220nF at each VCL/VSS pair per Renesas QDG Rev1.10 section1.2; TDK 50V X7R +/-10% production part. Nominal bias curve only; PDN qualification remains open. |  | 445-7408-1-ND | https://www.digikey.com/en/products/detail/tdk-corporation/C1608X7R1H224K080AB/2732843 | Selected for prototype VCL bypass; PWR-005. PCB/PDN qualification deferred. | 2026-09-08 DigiKey: 82010 in stock; USD0.17/0.098/0.06030 at qty1/10/100; 24wk; unreserved. TDK Production.
C5 | 1 | 220n |  |  |  |  | https://product.tdk.com/en/search/capacitor/ceramic/mlcc/info?part_no=C1608X7R1H224K080AB | TDK | C1608X7R1H224K080AB |  |  | PWR-005: 220nF at each VCL/VSS pair per Renesas QDG Rev1.10 section1.2; TDK 50V X7R +/-10% production part. Nominal bias curve only; PDN qualification remains open. |  | 445-7408-1-ND | https://www.digikey.com/en/products/detail/tdk-corporation/C1608X7R1H224K080AB/2732843 | Selected for prototype VCL bypass; PWR-005. PCB/PDN qualification deferred. | 2026-09-08 DigiKey: 82010 in stock; USD0.17/0.098/0.06030 at qty1/10/100; 24wk; unreserved. TDK Production.
C6 | 1 | 100n |  |  |  |  | https://product.tdk.com/en/search/capacitor/ceramic/mlcc/info?part_no=C1608X7R1H104K080AA | TDK | C1608X7R1H104K080AA |  |  | 100 nF +/-10%, 50 V X7R. +3V3_MCU bypass. TDK nominal DC-bias curve: interpolated 99.45 nF at 3.3 V; reference data, not guaranteed minimum. See PWR-001 design/power_decoupling.md. |  | 445-1314-1-ND | https://www.digikey.com/en/products/detail/tdk-corporation/C1608X7R1H104K080AA/513811 | Selected - nominal DC-bias screened; final rail and PDN qualification open | 2026-09-05: TDK Production; DigiKey Active, 374087 in stock, 24 weeks; USD 1:0.11, 10:0.06, 100:0.0359.
C7 | 1 | 220n |  |  |  |  | https://product.tdk.com/en/search/capacitor/ceramic/mlcc/info?part_no=C1608X7R1H224K080AB | TDK | C1608X7R1H224K080AB |  |  | PWR-005: 220nF at each VCL/VSS pair per Renesas QDG Rev1.10 section1.2; TDK 50V X7R +/-10% production part. Nominal bias curve only; PDN qualification remains open. |  | 445-7408-1-ND | https://www.digikey.com/en/products/detail/tdk-corporation/C1608X7R1H224K080AB/2732843 | Selected for prototype VCL bypass; PWR-005. PCB/PDN qualification deferred. | 2026-09-08 DigiKey: 82010 in stock; USD0.17/0.098/0.06030 at qty1/10/100; 24wk; unreserved. TDK Production.
C8 | 1 | 220n |  |  |  |  | https://product.tdk.com/en/search/capacitor/ceramic/mlcc/info?part_no=C1608X7R1H224K080AB | TDK | C1608X7R1H224K080AB |  |  | PWR-005: 220nF at each VCL/VSS pair per Renesas QDG Rev1.10 section1.2; TDK 50V X7R +/-10% production part. Nominal bias curve only; PDN qualification remains open. |  | 445-7408-1-ND | https://www.digikey.com/en/products/detail/tdk-corporation/C1608X7R1H224K080AB/2732843 | Selected for prototype VCL bypass; PWR-005. PCB/PDN qualification deferred. | 2026-09-08 DigiKey: 82010 in stock; USD0.17/0.098/0.06030 at qty1/10/100; 24wk; unreserved. TDK Production.
C9 | 1 | 47u |  |  |  |  |  |  |  |  |  | Candidate: Murata GRM32ER71A476KE15K, 47uF +/-10%, 10V X7R 1210. Murata GRM32ER71A476KE15-04CA (2025-01-10). HOLD pending DC-bias/aging and RA8P1 core-loop qualification; see design/core_bulk_c9.md. |  |  |  | HOLD - exact 47uF MPN not approved; resolve reference-part lifecycle and effective capacitance | 2026-09-27 DigiKey page: candidate GRM32ER71A476KE15K Active, 1595 unreserved, USD0.98 qty1 / 0.43690 qty100, 17wk. Earlier GRM32ER70J476KE20L lifecycle conflict retained in design/core_bulk_c9.md; not purchase approval.
C10 | 1 | 220n |  |  |  |  | https://product.tdk.com/en/search/capacitor/ceramic/mlcc/info?part_no=C1608X7R1H224K080AB | TDK | C1608X7R1H224K080AB |  |  | PWR-005: 220nF at each VCL/VSS pair per Renesas QDG Rev1.10 section1.2; TDK 50V X7R +/-10% production part. Nominal bias curve only; PDN qualification remains open. |  | 445-7408-1-ND | https://www.digikey.com/en/products/detail/tdk-corporation/C1608X7R1H224K080AB/2732843 | Selected for prototype VCL bypass; PWR-005. PCB/PDN qualification deferred. | 2026-09-08 DigiKey: 82010 in stock; USD0.17/0.098/0.06030 at qty1/10/100; 24wk; unreserved. TDK Production.
C11 | 1 | 220n |  |  |  |  | https://product.tdk.com/en/search/capacitor/ceramic/mlcc/info?part_no=C1608X7R1H224K080AB | TDK | C1608X7R1H224K080AB |  |  | PWR-005: 220nF at each VCL/VSS pair per Renesas QDG Rev1.10 section1.2; TDK 50V X7R +/-10% production part. Nominal bias curve only; PDN qualification remains open. |  | 445-7408-1-ND | https://www.digikey.com/en/products/detail/tdk-corporation/C1608X7R1H224K080AB/2732843 | Selected for prototype VCL bypass; PWR-005. PCB/PDN qualification deferred. | 2026-09-08 DigiKey: 82010 in stock; USD0.17/0.098/0.06030 at qty1/10/100; 24wk; unreserved. TDK Production.
C12 | 1 | 220n |  |  |  |  | https://product.tdk.com/en/search/capacitor/ceramic/mlcc/info?part_no=C1608X7R1H224K080AB | TDK | C1608X7R1H224K080AB |  |  | PWR-005: 220nF at each VCL/VSS pair per Renesas QDG Rev1.10 section1.2; TDK 50V X7R +/-10% production part. Nominal bias curve only; PDN qualification remains open. |  | 445-7408-1-ND | https://www.digikey.com/en/products/detail/tdk-corporation/C1608X7R1H224K080AB/2732843 | Selected for prototype VCL bypass; PWR-005. PCB/PDN qualification deferred. | 2026-09-08 DigiKey: 82010 in stock; USD0.17/0.098/0.06030 at qty1/10/100; 24wk; unreserved. TDK Production.
C13 | 1 | 220n |  |  |  |  | https://product.tdk.com/en/search/capacitor/ceramic/mlcc/info?part_no=C1608X7R1H224K080AB | TDK | C1608X7R1H224K080AB |  |  | PWR-005: 220nF at each VCL/VSS pair per Renesas QDG Rev1.10 section1.2; TDK 50V X7R +/-10% production part. Nominal bias curve only; PDN qualification remains open. |  | 445-7408-1-ND | https://www.digikey.com/en/products/detail/tdk-corporation/C1608X7R1H224K080AB/2732843 | Selected for prototype VCL bypass; PWR-005. PCB/PDN qualification deferred. | 2026-09-08 DigiKey: 82010 in stock; USD0.17/0.098/0.06030 at qty1/10/100; 24wk; unreserved. TDK Production.
C14 | 1 | 220n |  |  |  |  | https://product.tdk.com/en/search/capacitor/ceramic/mlcc/info?part_no=C1608X7R1H224K080AB | TDK | C1608X7R1H224K080AB |  |  | PWR-005: 220nF at each VCL/VSS pair per Renesas QDG Rev1.10 section1.2; TDK 50V X7R +/-10% production part. Nominal bias curve only; PDN qualification remains open. |  | 445-7408-1-ND | https://www.digikey.com/en/products/detail/tdk-corporation/C1608X7R1H224K080AB/2732843 | Selected for prototype VCL bypass; PWR-005. PCB/PDN qualification deferred. | 2026-09-08 DigiKey: 82010 in stock; USD0.17/0.098/0.06030 at qty1/10/100; 24wk; unreserved. TDK Production.
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

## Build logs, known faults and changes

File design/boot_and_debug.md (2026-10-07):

# RA8P1 boot, reset and debug

The selected MCU is R7KA8P1KFLCAC#UC0. U1A and J1 are on
`mcu_clocks_debug.kicad_sch`; this is not the RA8D2 evaluation-board circuit.

## Mode selection

R2 pulls P201/MD high for normal startup with on-chip MRAM enabled and
the external bus initially disabled. Internal copper pads TP2 provide MD
and ground for the service fixture: hold MD low while asserting and
releasing external RESET. There is no fitted BOOT switch. JTAG boot and
SCI/USB boot cannot be entered using POR alone (HUM 4.3-4.4, pp.234-235).

SWD/JTAG boot entry requires a debugger boot request while RES is low,
with MD high at release. Device lifecycle, authentication and TrustZone
settings can restrict access. A debug connector does not guarantee recovery
from every security configuration. The MCU uses code MRAM and extra MRAM,
not internal program flash. FSBL settings also affect startup (HUM 2.6).

ROM USB programming uses USBFS, not USBHS. The product USBHS data port
must not be described as a ROM recovery interface. J1 provides dedicated
SWD/JTAG access; USBFS and SCI service routing need explicit decisions
before final schematic integration.

## Reset

R1 pulls RES to +3V3_MCU; U2 pulls it low when its monitored supply is
below threshold or a fixture grounds U2's MR input through TP1. Additional external reset
drivers must be open-drain/open-collector to avoid contention with the probe.
No RC capacitor is fitted on RES. The external supervisor deliberately uses
the RES-pin startup path; do not assume the internal POR flag semantics of
a RES pin rising simultaneously with VCC (Quick Design Guide 2.5 and
6.1-6.2, pp.16 and 30-31; HUM 6.3.1-6.3.2).

Service tooling shall hold RES low for at least 3 ms after VCC is valid.
This exceeds the 2.4 ms power-on minimum in Datasheet Table 2.52, p.118.
Do not use a shorter operating-state minimum as the universal service pulse.
Fixture contact bounce is not a substitute for a controlled programmer reset pulse.

### RST-002: current MCU reset migration

Native U2 has been replaced with TPS389001DSET and wired with R67
ERA-6ARW333V 33k above SENSE, R74 RG1608N-203-W-T1 20k below SENSE,
R75 RC0603FR-0710KL 10k MR pull-up and C95 C1608C0G1H103J080AA
10n CT capacitor. The final targeted netlist check confirms the six U2
pin partitions; native/CLI ERC remains 139 errors and two warnings, with
no U2 violations or changed rules/exclusions. BOM and full PDF are refreshed;
changed MCU/radio pages were visually inspected. This is not whole-circuit
validation, a completed reset system or hardware qualification.

The current pin contract is U2.1 SENSE at R67/R74, U2.2 GND, U2.3
SW_RESET_N/TP1 with R75 to main, U2.4 +3V3_MCU with retained C44,
U2.5 C95 to GND and U2.6 MCU_RESET_N with retained R1. MR and RESET
remain separate. The old direct SENSE connection and CT no-connect are
superseded. The common reset endpoints are U2.6, R1.2, U1.D5, J1.10,
U15.A4, U7.3 and added microSD power-gate input U19.6.

[RST-002](reset_coordination_tps3890.md) owns the exact primary sources,
procurement and executable calculations: conditional rising threshold
3.019118825..3.113278988 V, main release margin 38.540692 mV and
8.148276 ms minimum CT charge time versus the 2.4 ms RES requirement.
The radio R12/R13 divider also uses 33k/20k. Native U4 is now
TPS22964CYZPT under RADIO-019, with a conditional 20 mV total path-loss
allocation and 18.540692 mV radio release headroom. Complete path/DC
qualification remains open; the former TPS22917 loss screen is historical.
No fast-collapse, memory-quiescence or VBATT sequencing guarantee follows
from this MCU migration.

Current U2 loading includes 5 uA MCU +5 uA U7 +2 uA NOR +5 uA U19
=17 uA device allocation. U19 was not reserved in the former 12 uA sum.
Preserve 13 uA for supervisor/board/probe and other adverse leakage, giving
30 uA total. With R1=9801..10201 ohm and the RST-002 main envelope,
sink <=0.376190439 mA fits U2's 0.4 mA test for VOL<=0.25 V at
VDD>=1.5 V. Released high is >=2.845789680 V, with 0.324333936 V
MCU high margin. U19 reduces that margin by 51.005 mV. At the minimum
falling corner, the static released high/margin are 2.694792727 V /
0.294134545 V. These are acceptance allocations, not guaranteed ramp,
probe or release-edge behavior; RST-002 contains the executable proof.

### RST-001: external supervisor implementation basis

Historical checkpoint, superseded for current U2 by RST-002 above. All
G33 pin mappings, sourcing, fixed-threshold and open-CT calculations in
this subsection describe the former circuit, not the current native U2.

At that checkpoint U2 was TI TPS3808G33DBVR. VDD and SENSE were
connected to +3V3_MCU, GND to ground, and CT has an intentional no-connect
marker. RESET connects to MCU_RESET_N and TP1 connects to MR through
SW_RESET_N. C44 is the local 100 nF VDD bypass. These connections have
been checked in the saved KiCad netlist. Native procurement fields and the
exported BOM record both exact ordering codes and dated sourcing. This adds a hardware undervoltage
reset independent of firmware configuration; it does not replace core-voltage
monitoring or qualify the complete power tree.

Authority: [TI TPS3808 datasheet](https://www.ti.com/lit/ds/symlink/tps3808.pdf),
SBVS050N, revised August 2026, sections 5, 6.5-6.6 and 7.3. The newer
revision is important: use its fixed-threshold accuracy, not an assumed
two-percent figure copied from another variant. The G33 nominal falling
threshold is 3.07 V; full-temperature accuracy is +/-1.5%, and fixed-version
hysteresis is at most 2.5% of the threshold. CT open selects 12..28 ms
reset-release delay (20 ms typical), without an external timing capacitor.

```text
Falling threshold minimum = 3.07*(1-0.015) = 3.02395 V
Falling threshold maximum = 3.07*(1+0.015) = 3.11605 V
Conservative rising-threshold screen = 3.11605*(1+0.025)
                                    = 3.19395125 V
Proposed 3.3 V source at -2% = 3.3*0.98 = 3.234 V
Static release margin = 3.234-3.19395125 = 0.04004875 V
Minimum delay / MCU power-on RES minimum = 12/2.4 = 5
```

The hysteresis screen applies the percentage to the maximum falling
threshold conservatively. The 2% rail tolerance is a proposed power-tree
requirement, NOT a verified regulator property. Ripple and distribution
losses must also fit within the release margin. The delay starts only after
SENSE and MR satisfy their release conditions; final rail settling must be
checked separately. SENSE-to-RESET propagation is 20 us typical with no
maximum in the table, so this part alone does not prove safe behavior during
an arbitrarily fast brownout or guarantee the USB analog rail never falls
below 3 V. USB-004's bead-drop screen is not a substitute for that analysis.

Historical wiring: pin 6 VDD and pin 5 SENSE to +3V3_MCU, pin 2 GND,
pin 1 open-drain RESET to MCU_RESET_N with existing R1 10 kohm pull-up,
pin 4 CT intentionally open. TP1 connects to pin 3 MR so fixture release also
receives the supervisor delay; the debugger connects directly to MCU_RESET_N.
MR has an internal pull-up. Do not connect MR to RESET, which would create
a self-holding reset loop. C44 provides the prescribed 100 nF VDD bypass:
TDK C1608X7R1H104K080AA, X7R, 50 V, +/-10%, sharing the documented
capacitance-screening basis of PWR-001 for the existing 100 nF bypasses.
No capacitor is added on MCU_RESET_N.

At that historical G33 checkpoint, MCU_RESET_N left this sheet through a
hierarchical output and fed
radio arbitration gate U7.3 through the root. This is an added input load,
not another reset driver. Include U7 leakage and input capacitance in the
reset high-level, sink-current and edge-time budgets; the R1-only current
calculation below is not the complete loaded-net bound.
See [RADIO-015](radio_interface.md#radio-015-reset-request-arbitration) for
the gate connection contract and remaining electrical checks.

Historical G33-only screen (not current TPS3890 loading): R1 at 3.6 V
and -1% tolerance sinks at most 3.6/9900 = 0.363636 mA,
below the supervisor's 1 mA VOL test current at VDD >= 1.8 V. Its 0.4 V
maximum VOL must still be checked against the RA8P1 RES low threshold;
the current comparison alone is not logic-level qualification. Datasheet
Table 2.5 pp.48-49, note 1 explicitly includes RES in the VCC-domain
Schmitt-input row: VIL maximum is 0.2*VCC. At the minimum screened falling
threshold, 0.2*3.02395 = 0.60479 V, leaving 0.20479 V relative to the
supervisor's 0.4 V maximum VOL. This supports static low-level compatibility
near the monitored threshold; it does not cover an unpowered rail, total
debugger loading, leakage-driven high-level margin or reset-edge timing.
Cold startup
uses the MCU's RES-pin reset path (HUM 6.3.1 p.265), not an assumption that
PORF remains set while an external supervisor holds RES low.

The bundled KiCad Power_Supervisor:TPS3808DBV symbol has matching DBV
pin numbers but models RESET as a generic output. The project-local
Power_Devices:TPS3808G33DBVR variant was created through the Symbol Editor
with pin 1 changed to open collector; all six pin identities were checked
against TI Table 5-1. The installed global library is untouched. Comparing
the complete pre-existing symbol trees confirms no changes other than
serialization ordering and omission of the default 20 mil pin-name offset.
The compact supervisor retains the bundled symbol's uniform 100 mil pins.
The circuit is drawn, but reset high-level leakage, edge timing and complete
power-tree behavior remain unqualified.

[DigiKey 296-17195-1-ND](https://www.digikey.com/en/products/detail/texas-instruments/TPS3808G33DBVR/666727)
snapshot 2026-09-05: Active, 22054 in stock, 16-week standard lead time;
USD 1.84 / 1.355 / 1.0984 at quantities 1 / 10 / 100, excluding shipping,
tax and tariff. TI lists the exact ordering code in production.

Reproducible arithmetic screening (not a fitted-BOM or hardware test):

```sh
python3 - <<'PY'
from fractions import Fraction as F

low = F('3.07')*(1-F('.015'))
high = F('3.07')*(1+F('.015'))
release = high*(1+F('.025'))
margin = F('3.3')*F('.98')-release
if (low, high, release, margin) != (
        F('3.02395'), F('3.11605'), F('3.19395125'), F('.04004875')):
    raise ValueError('RST-001 threshold screening mismatch')
if F(12)/F('2.4') != 5 or F('3.6')/9900*1000 != F(4, 11):
    raise ValueError('RST-001 delay or pull-up screening mismatch')
vil_limit = F('.2')*low
low_margin = vil_limit-F('.4')
if (vil_limit, low_margin) != (F('.60479'), F('.20479')):
    raise ValueError('RST-001 static low-level screening mismatch')
print('Historical RST-001 PASS: threshold, delay, pull-up and static low-level arithmetic.')
print('Hardware, high-level leakage, power-tree and transient checks remain open.')
PY
```

## J1: Cortex debug connection

| Contact | Net | MCU ball / function |
| --- | --- | --- |
| 1 | +3V3_MCU | Target VCC sense only |
| 2 | DBG_SWDIO | C6 / P210 / TMS / SWDIO |
| 3 | GND | Ground |
| 4 | DBG_SWCLK | D6 / P211 / TCK / SWCLK |
| 5 | GND | Ground |
| 6 | DBG_TDO_SWO | E7 / P209 / TDO / SWO |
| 7 | No connection | Key position |
| 8 | DBG_TDI | C7 / P208 / TDI |
| 9 | GND | Ground detect |
| 10 | MCU_RESET_N | D5 / RES |

The probe senses the target I/O voltage at contact 1; do not inject target
power there or drive signals into an unpowered MCU. R3-R5 are external
10 kohm pull-ups on SWDIO, SWCLK and TDI, consistent with HUM 21.4.
TDO/SWO is an output with no pull. One interface supports both CPU cores.
No onboard J-Link MCU is included.

J1's connector ordering code remains to be selected. TP1 and TP2 are paired
bare copper service pads, excluded from the purchased BOM and placement
files but retained on the board. They are not DNP switches. Pad 1 is the
named signal and pad 2 is ground; physical pad geometry is deferred with
the PCB. TP1's supervisor MR access does not replace direct RES on J1.10.
The single exposed product power/wake button belongs to the always-on
power-control circuit, not these service controls. Its native held-control circuit is recorded in SYS-007 and BTN-010;
full-system qualification remains open. R1-R5 use
Yageo RC0603FR-0710KL; their ratings and sourcing are recorded in the BOM.
Both oscillator networks are wired as described below and in the linked
calculation records; board-level matching remains required.

## Oscillator qualification basis

The crystal-specific derivation, tolerance corners, parasitic sensitivity and
reproducible Python check are maintained in
[CLK-001: main oscillator load network](clock_calculations.md#clk-001-y1-main-oscillator-load-network).
The matching schematic annotation links to that record.

R01AN7202EJ0102 Rev.1.02 explicitly assigns RA8P1 to matching group 10
(Table 4.1). Do not substitute results for group 8 (RA8M1/RA8D1).

- Main clock, Table 4.1.9: the 24 MHz example uses a 6 pF crystal,
  8 pF external capacitors on each side, and no damping resistance. Its
  measured negative resistance is -1050 ohm and the recommended maximum
  crystal ESR is 210 ohm. These are evaluation-board results, not a
  guarantee for another crystal or PCB.
- Sub-clock, Table 4.2.10: the examples use a 6 pF crystal and 4 pF
  external capacitors. Recommended maximum ESR decreases from 340 kohm
  in normal mode to 180, 120, and 50 kohm in low-power modes 1, 2, and 3.
- The imported FL2400022 candidate is specified as 10 pF in its part
  metadata; the public FL-series sheet does not decode specification code
  0022. The imported ABS07-32.768KHZ-1-T is the default 12.5 pF variant,
  with a 70 kohm maximum ESR and 0.5 uW maximum drive per the Abracon
  series sheet. Neither is the 6 pF part used in the group-10 examples.

Do not assign load capacitors from those examples to the imported parts
without matching evidence. In particular, a 70 kohm RTC crystal does not
meet the example's 50 kohm criterion for the lowest-drive mode.
The imported FL2400022 remains in the candidate library but is no longer
the placed main crystal. Y1 is now Murata XRCGB24M000F3M19R0: 24 MHz,
CL 6 pF, ESR <= 100 ohm, drive <= 300 uW, initial tolerance +/-30 ppm,
temperature shift +/-40 ppm over -40 to +85 C, and aging +/-5 ppm/year
per exact specification JGC49-3003B. Its 100 ohm ESR is below the group-10
reference's 210 ohm screening limit; that comparison does not establish
oscillation margin on this board.

Y1 terminals 1 and 3 connect to U1.K17 EXTAL and U1.K16 XTAL through
local nets OSC_EXTAL and OSC_XTAL. The two other package lands are linked
internally and specified NC; the project symbol models these as NC pads
2 and 4, not grounded case pins. The exact footprint land numbering must
be reviewed at the deferred PCB stage against Murata Figure 1.

C35/C36 are TDK C1005NP01H080D050BA, 8 pF +/-0.5 pF, 50 V NP0, 0402,
each returning its oscillator node to ground. Equal 8 pF capacitors
provide 4 pF series load; an estimated 2 pF combined parasitic load gives
the crystal's nominal 6 pF. This is an initial matching network based on
Renesas's group-10 example, not a measured parasitic value. No external
feedback or damping resistor is fitted in this initial network. The PCB
must pass negative-resistance, startup, frequency and drive measurements;
adjust load capacitance or add damping only with matching evidence.
The RTC uses Y2 ABS07-LR-32.768KHZ-6-1-T and 4 pF C37/C38 on XCIN/XCOUT.
Its separate CLK-002 calculation records the exact part, assumed parasitics,
initial low-power-mode-2 setting and required hardware validation.

Sourcing checked 2026-09-05: DigiKey indexed stock 13,578 for Y1
(`490-18296-1-ND`, USD 0.32 / 0.275 / 0.239 at 1 / 10 / 100), and
73,746 for C35/C36 (`445-13781-1-ND`, USD 0.11 / 0.058 / 0.0341).
Both listings are active. Dated snapshots and exact links are in the
schematic-linked BOM; recheck stock before ordering.

The final selection must record exact ordering codes, load capacitance,
ESR, drive limits, MCU drive settings, and startup wait requirements.
Board-level verification must measure startup margin and excitation power;
do not probe the RTC resonator directly to measure its frequency. Use a
buffered clock output. Datasheet Tables 2.50-2.51 require oscillator
evaluation to determine stabilization waits, and HUM 9.3-9.4 governs the
connections and optional feedback/damping resistors.

## Sources

- [Murata exact Y1 specification](https://pim.murata.com/asset/pim4/ceramicResonatorCrystalUnit/SPEC_XRCGB24M000F3M19R0_PDF_CERAMICRESONATORCRYSTALUNIT),
  JGC49-3003B, ratings and terminal diagram, pages 2-3.
- [TDK exact load capacitor](https://product.tdk.com/en/search/capacitor/ceramic/mlcc/info?part_no=C1005NP01H080D050BA).
- [RX and RA oscillator design guide](https://www.renesas.com/en/document/apn/renesas-rx-and-ra-families-design-guide-main-clock-circuits-and-sub-clock-circuits-rev102),
  R01AN7202EJ0102 Rev.1.02, Tables 4.1, 4.1.9 and 4.2.10; sections 5-7.
- [Diodes FL series](https://www.diodes.com/assets/Datasheets/FL.pdf),
  DS40067 Rev.2, pin functions and electrical characteristics.
- [Abracon ABS07 series](https://abracon.com/Resonators/ABS07.pdf),
  revised 2022-08-10, electrical specifications and ordering options.

- [RA8P1 Hardware User's Manual](https://www.renesas.com/en/document/mah/ra8p1-group-users-manual-hardware),
  R01UH1064EJ0130 Rev.1.30, sections 2.4-2.6, 4.3-4.4 and 21.4.
- [RA8P1 Datasheet](https://www.renesas.com/en/document/dst/ra8p1-group-datasheet),
  R01DS0439EJ0130 Rev.1.30, pin list and Table 2.52.
- [RA8x2 MCU Quick Design Guide](https://www.renesas.com/en/document/apn/ra8p1-mcu-quick-design-guide),
  R01AN7883EU0110 Rev.1.10, sections 2 and 6. This guide explicitly includes
  RA8P1; family-specific details still require its own HUM.

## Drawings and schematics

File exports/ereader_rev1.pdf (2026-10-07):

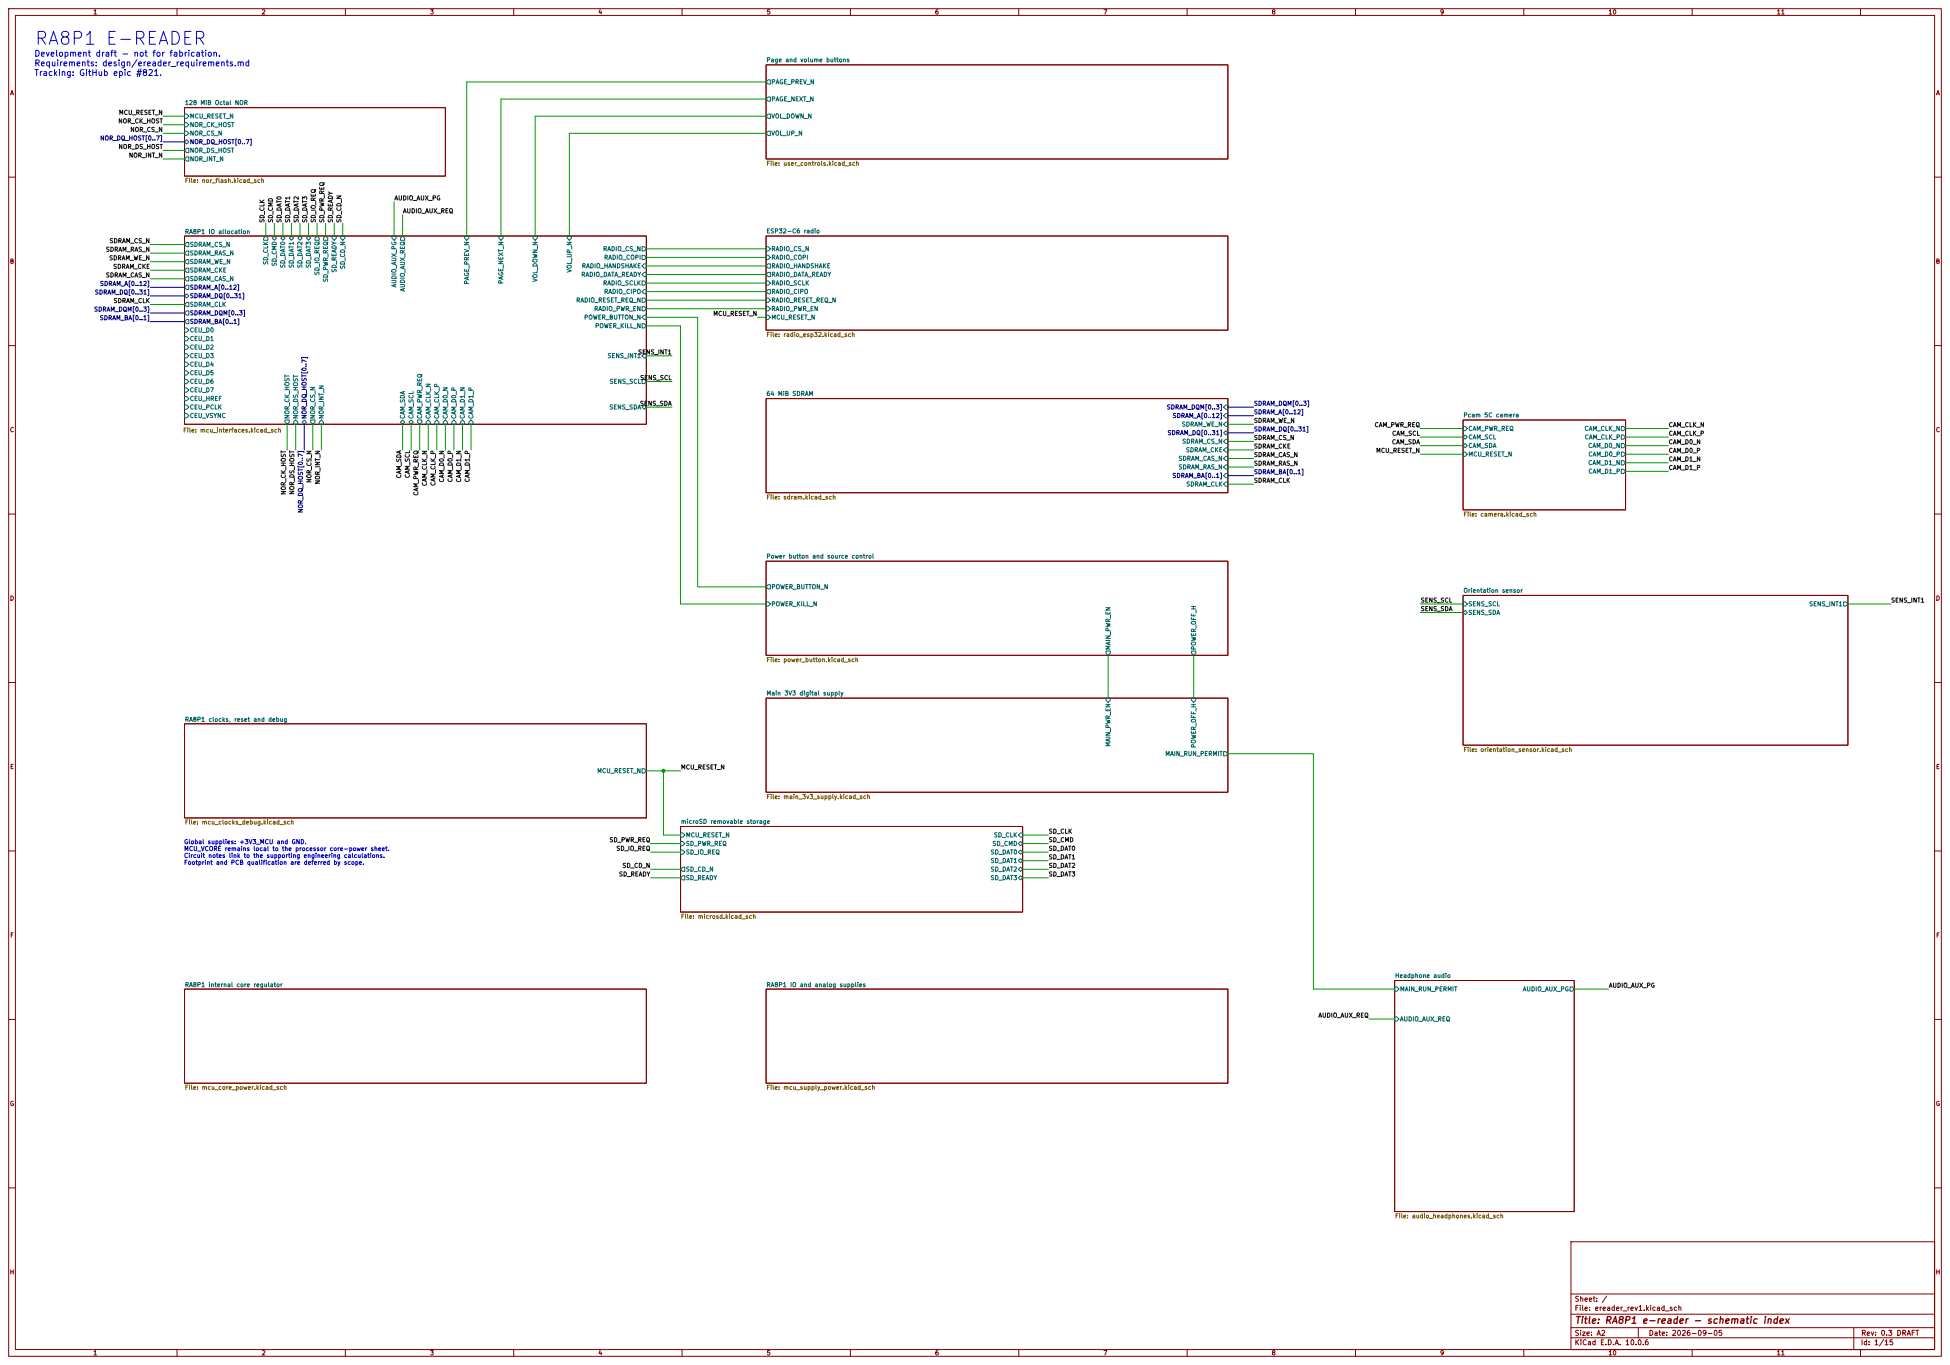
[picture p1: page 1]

Development draft - not for fabrication.
Requirements: design/ereader_requirements.md
Tracking: GitHub epic #821.

RA8P1 clocks, reset and debug

Global supplies: +3V3_MCU and GND. MCU_VCORE remains local to the processor core-power sheet. Circuit notes link to the supporting engineering calculations. Footprint and PCB qualification are deferred by scope.

Sheet: /
File: ereader_rev1.kicad_sch
Title: RA8P1 e-reader - schematic index

Size: A2 | Rev: 0.3 DRAFT
KiCad E.D.A. 10.0.6 | Id: 1/15

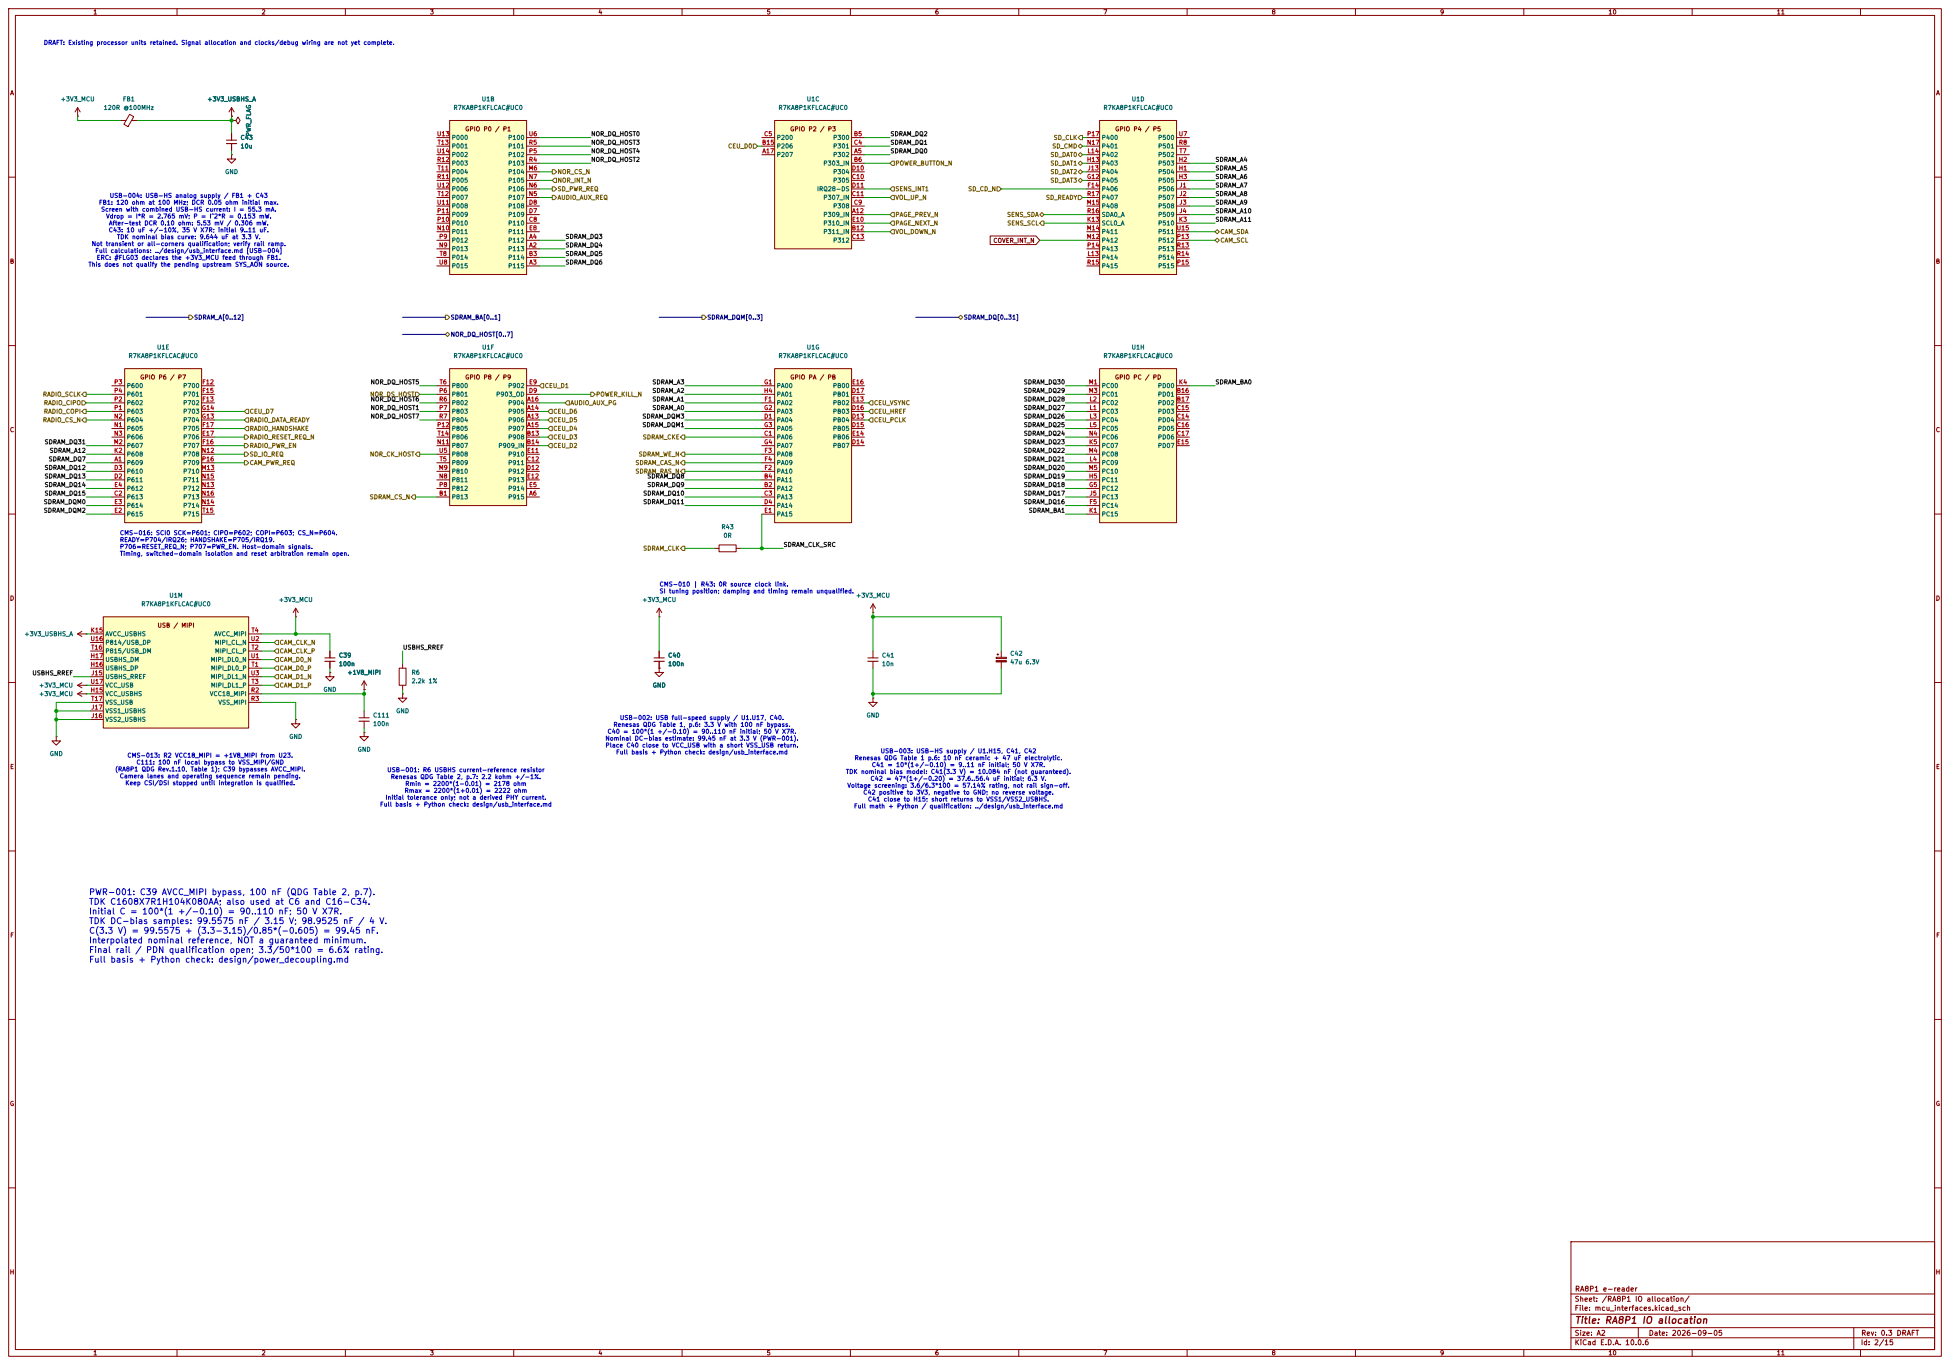
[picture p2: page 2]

FB1: 120 ohm at 100 MHz; DCR 0.05 ohm initial max. Screen with combined USB-HS current: I = 55.3 mA. Vdrop = I*R = 2.765 mV; P = I^2*R = 0.153 mW. After-test DCR 0.10 ohm: 5.53 mV / 0.306 mW. C43: 10 uF +/-10%, 35 V X7R; initial 9..11 uF. TDK nominal bias curve: 9.644 uF at 3.3 V. Not transient or all-corners qualification; verify rail ramp. Full calculations: ../design/usb_interface.md [USB-004] ERC: #FLG03 declares the +3V3_MCU feed through FB1. This does not qualify the pending upstream SYS_AON source. (https://github.com/bsikar/ra8-firmware/blob/design/ereader-circuit/ra8p1_kicad/design/usb_interface.md) DRAFT: Existing processor units retained. Signal allocation and clocks/debug wiring are not yet complete.

USB-004: USB-HS analog supply / FB1 + C43

Keep CSI/DSI stopped until integration is qualified. CMS-016: SCI0 SCK=P601; CIPO=P602; COPI=P603; CS_N=P604.
READY=P704/IRQ26; HANDSHAKE=P705/IRQ19.
P706=RESET_REQ_N; P707=PWR_EN. Host-domain signals.

CMS-013: R2 VCC18_MIPI = +1V8_MIPI from U23. C111: 100 nF local bypass to VSS_MIPI/GND

(RA8P1 QDG Rev.1.10, Table 1); C39 bypasses AVCC_MIPI. Camera lanes and operating sequence remain pending.

PWR-001: C39 AVCC_MIPI bypass, 100 nF (QDG Table 2, p.7).
TDK C1608X7R1H104K080AA; also used at C6 and C16-C34.
Initial C = 100*(1 +/-0.10) = 90..110 nF; 50 V X7R.
TDK DC-bias samples: 99.5575 nF / 3.15 V; 98.9525 nF / 4 V.
Interpolated nominal reference, NOT a guaranteed minimum.
Final rail / PDN qualification open; 3.3/50*100 = 6.6% rating.
Full basis + Python check: design/power_decoupling.md (https://github.com/bsikar/ra8-firmware/blob/design/ereader-circuit/ra8p1_kicad/design/power_decoupling.md)

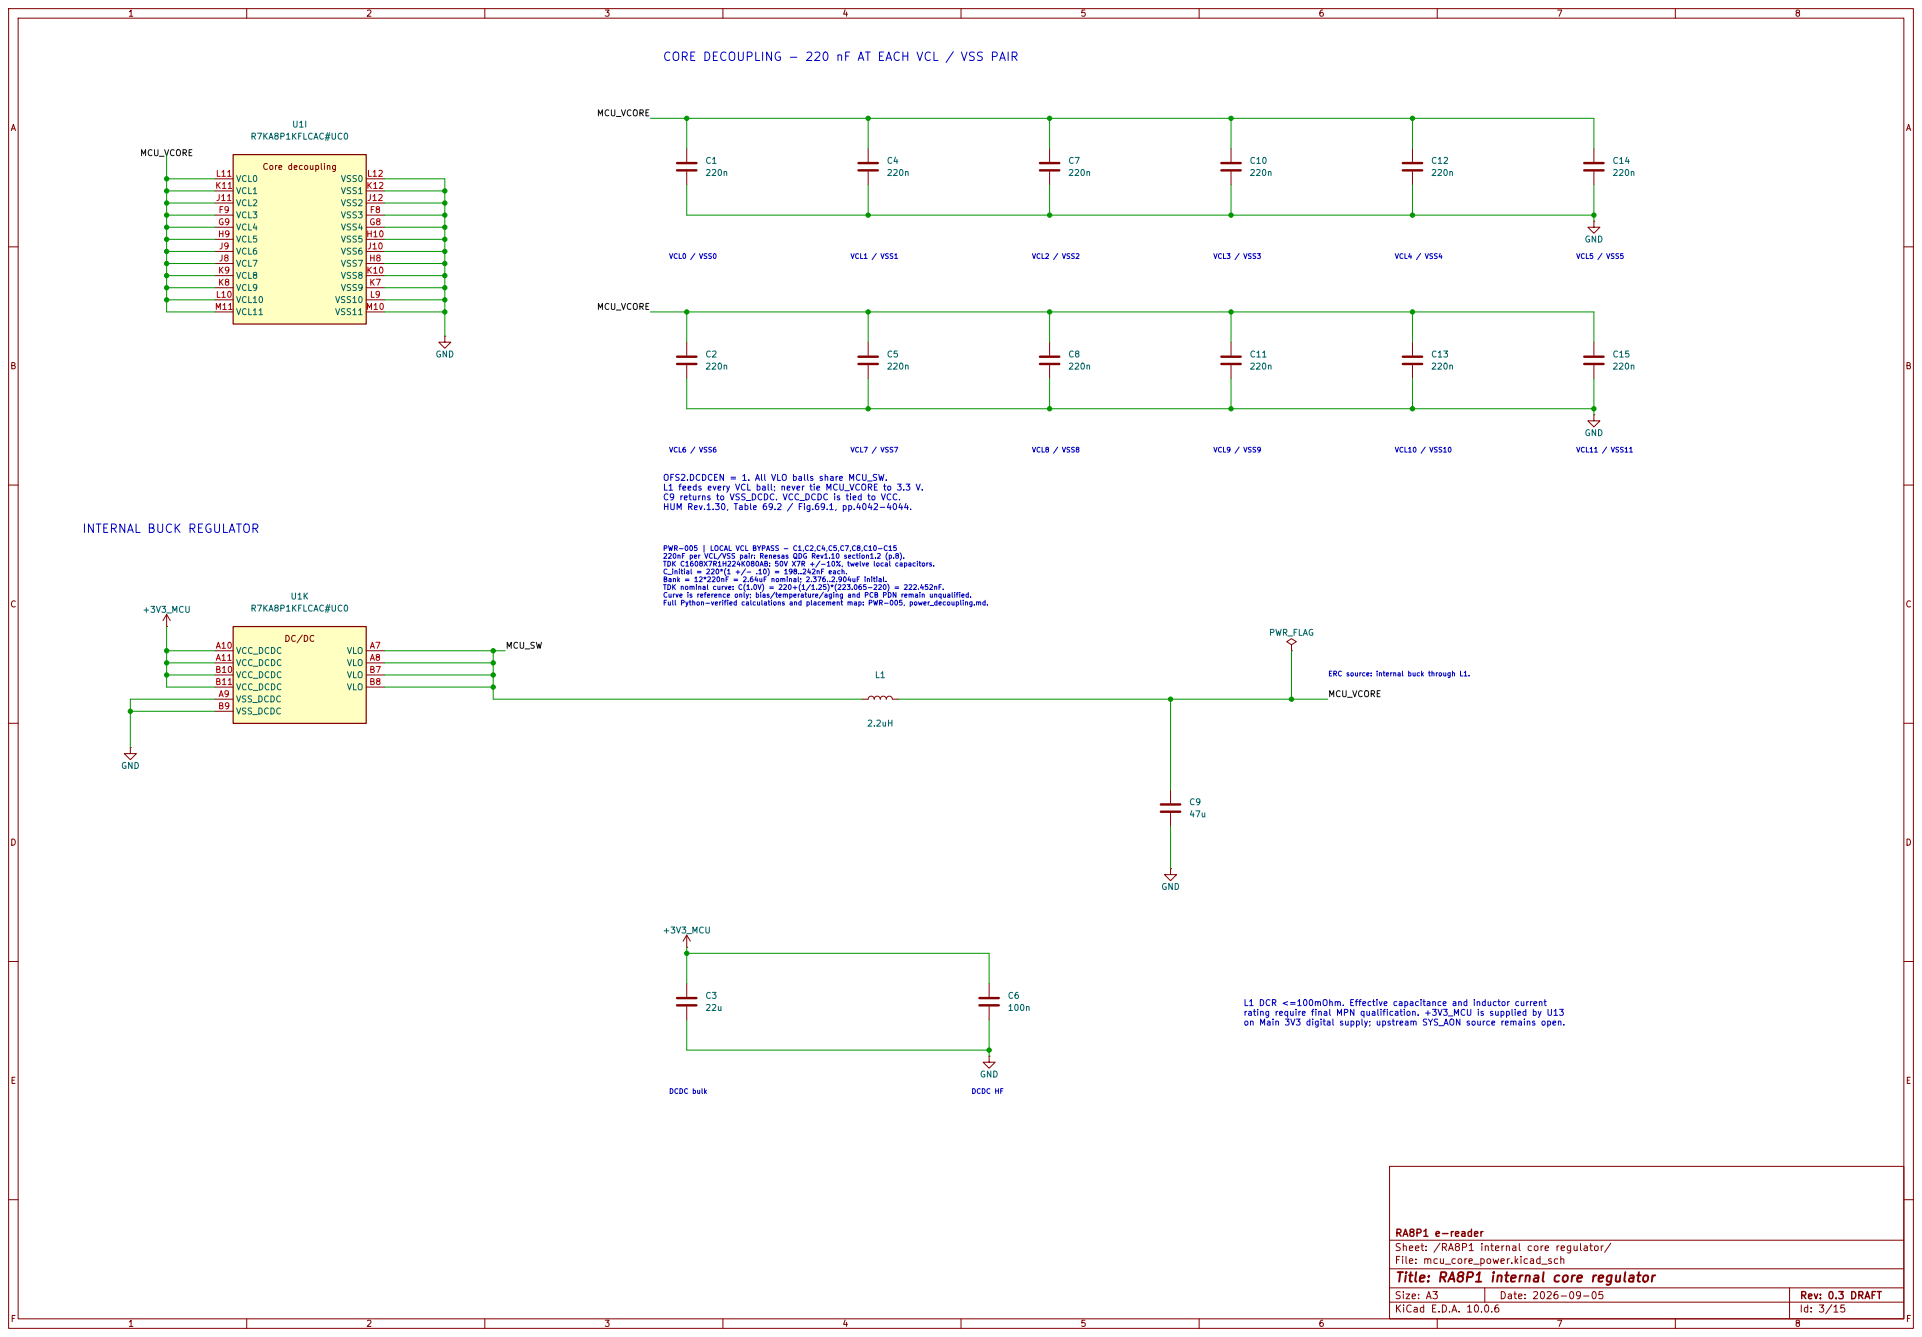
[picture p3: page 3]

VCL4 / VSS4 OFS2.DCDCEN = 1. All VLO balls share MCU_SW. L1 feeds every VCL ball; never tie MCU_VCORE to 3.3 V. C9 returns to VSS_DCDC. VCC_DCDC is tied to VCC. HUM Rev.1.30, Table 69.2 / Fig.69.1, pp.4042-4044. VCL1 / VSS1 CORE DECOUPLING - 220 nF AT EACH VCL / VSS PAIR

ERC source: internal buck through L1.

L1 DCR <=100mOhm. Effective capacitance and inductor current rating require final MPN qualification. +3V3_MCU is supplied by U13

on Main 3V3 digital supply; upstream SYS_AON source remains open.

Sheet: /RA8P1 internal core regulator/
File: mcu_core_power.kicad_sch
Title: RA8P1 internal core regulator

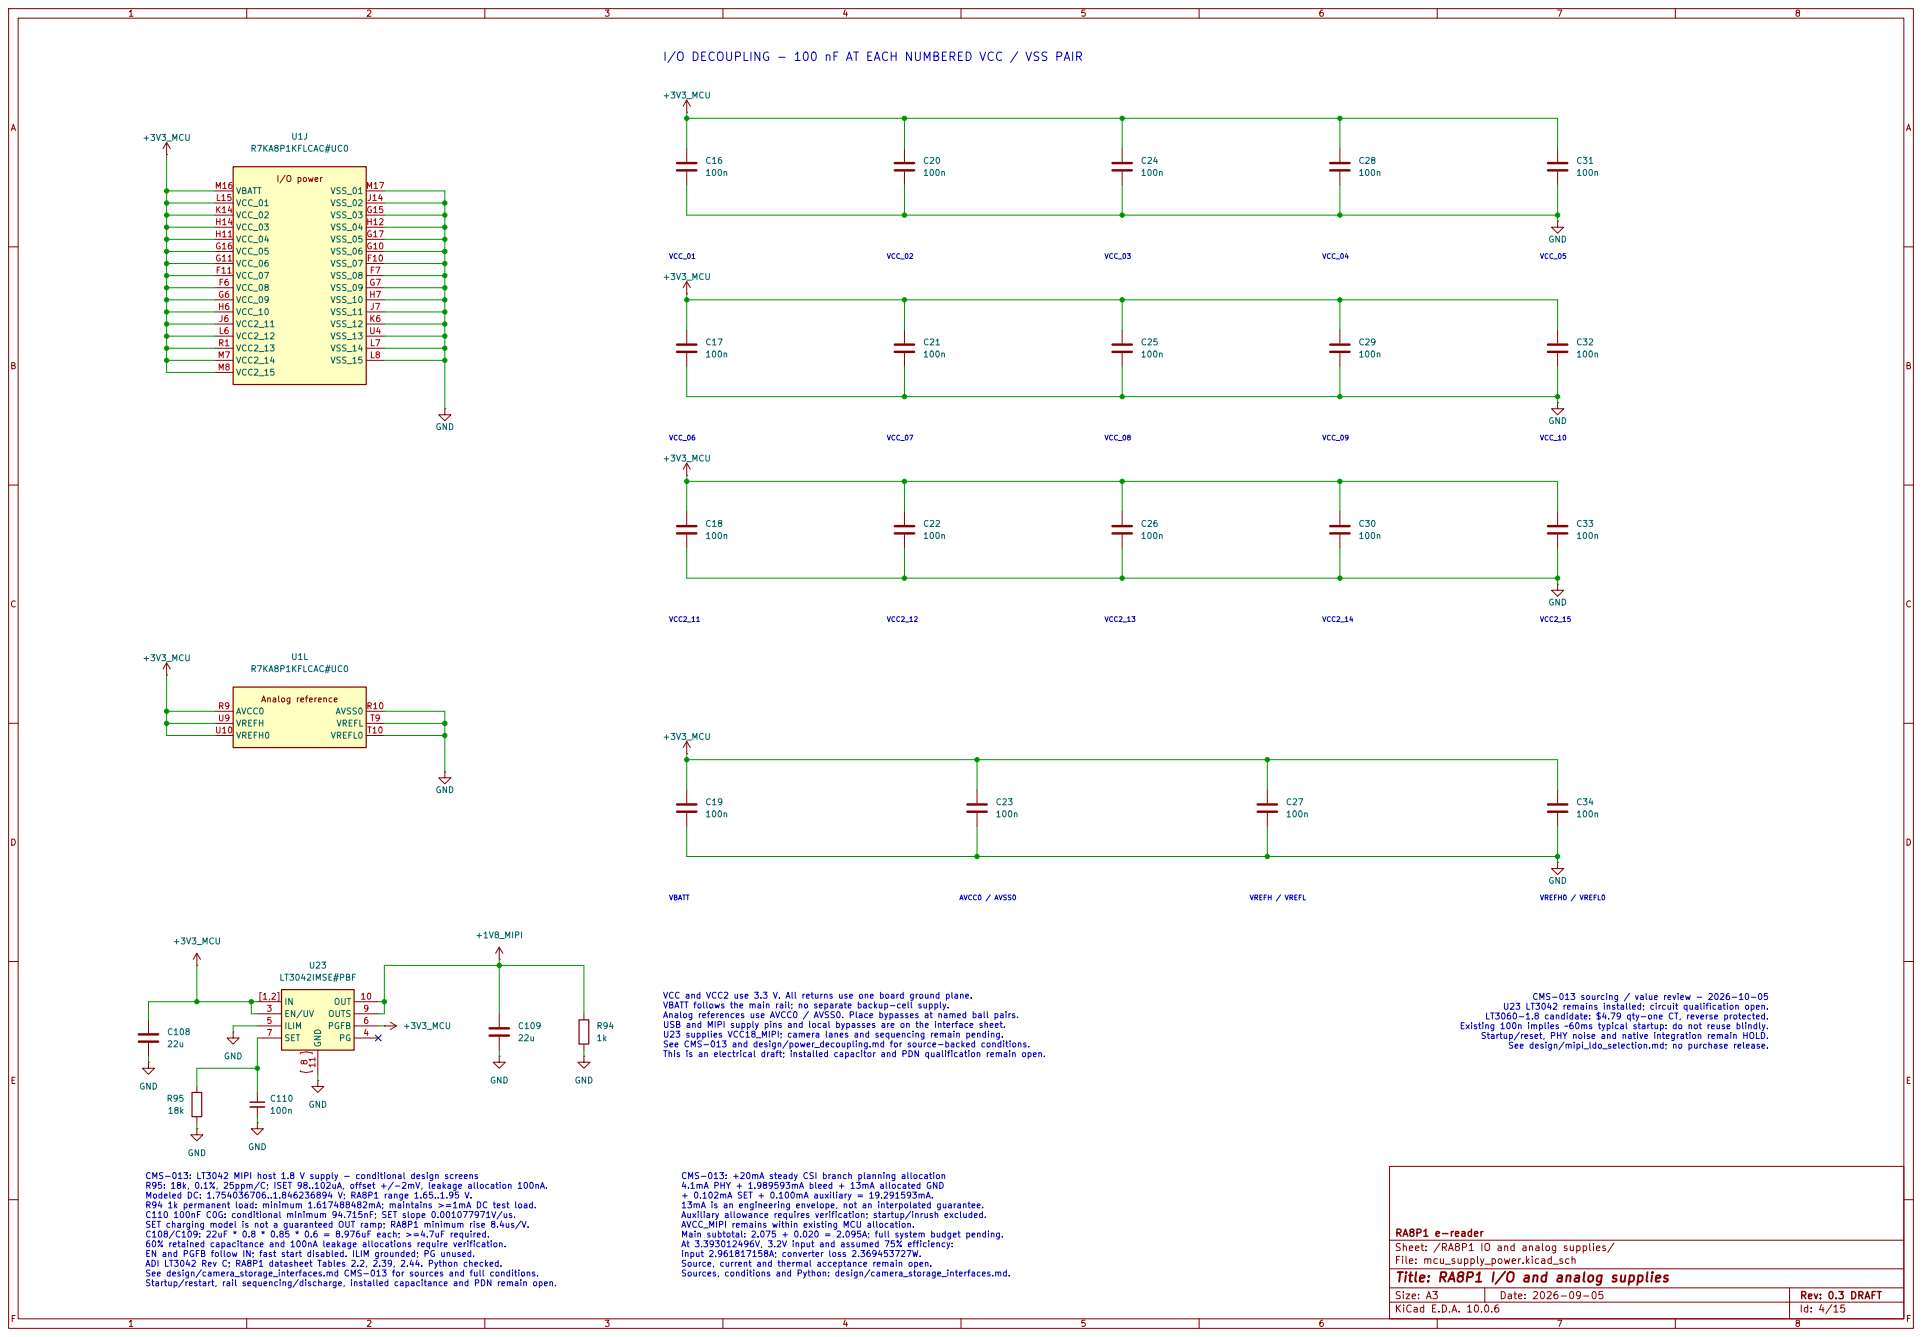
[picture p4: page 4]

I/O DECOUPLING - 100 nF AT EACH NUMBERED VCC / VSS PAIR

VREFH0 / VREFL0 CMS-013 sourcing / value review - 2026-10-05 U23 LT3042 remains installed; circuit qualification open. LT3060-1.8 candidate: $4.79 qty-one CT, reverse protected.

input 2.961817158A; converter loss 2.369453727W. Source, current and thermal acceptance remain open. Sources, conditions and Python: design/camera_storage_interfaces.md. VCC and VCC2 use 3.3 V. All returns use one board ground plane. VBATT follows the main rail; no separate backup-cell supply.

Analog references use AVCC0 / AVSS0. Place bypasses at named ball pairs. USB and MIPI supply pins and local bypasses are on the interface sheet. U23 supplies VCC18_MIPI; camera lanes and sequencing remain pending. See CMS-013 and design/power_decoupling.md for source-backed conditions. This is an electrical draft; installed capacitor and PDN qualification remain open.

Existing 100n implies ~60ms typical startup: do not reuse blindly.

Startup/reset, PHY noise and native integration remain HOLD. See design/mipi_ldo_selection.md; no purchase release.

CMS-013: LT3042 MIPI host 1.8 V supply - conditional design screens R95: 18k, 0.1%, 25ppm/C; ISET 98..102uA, offset +/-2mV, leakage allocation 100nA. Modeled DC: 1.754036706..1.846236894 V; RA8P1 range 1.65..1.95 V. R94 1k permanent load: minimum 1.617488482mA; maintains >=1mA DC test load. C110 100nF C0G: conditional minimum 94.715nF; SET slope 0.001077971V/us. SET charging model is not a guaranteed OUT ramp; RA8P1 minimum rise 8.4us/V.
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

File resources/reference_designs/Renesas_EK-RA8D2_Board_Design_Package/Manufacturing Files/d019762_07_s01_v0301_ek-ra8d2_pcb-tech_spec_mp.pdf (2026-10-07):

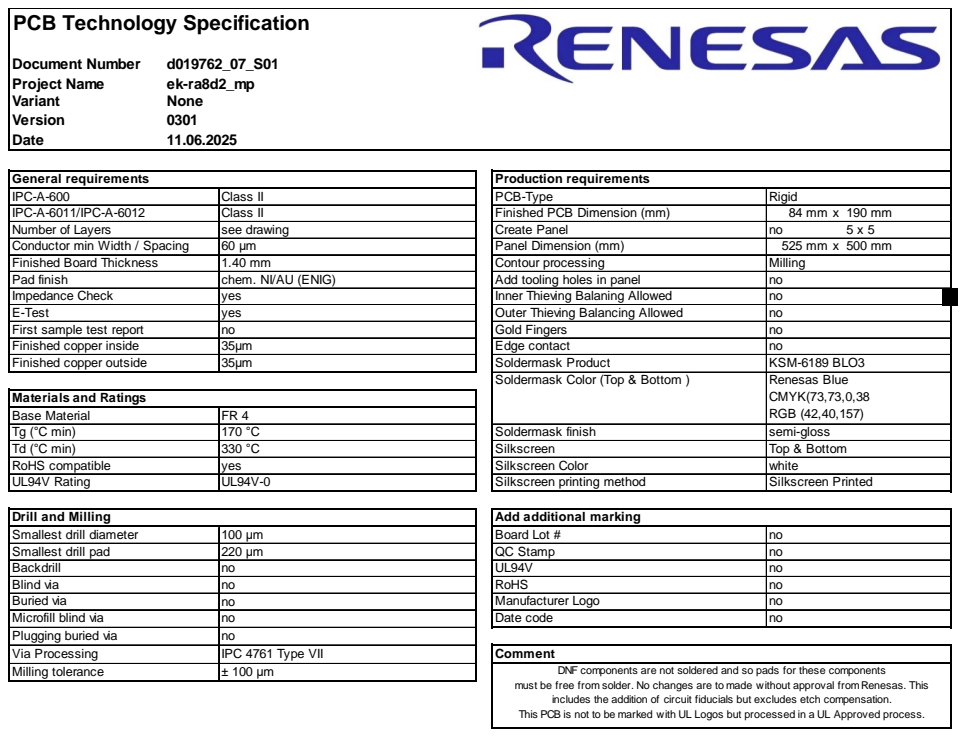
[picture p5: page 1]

General requirements
IPC-A-600
IPC-A-6011/IPC-A-6012
Number of Layers
Conductor min Width / Spacing
Finished Board Thickness
Pad finish
Impedance Check
E-Test
First sample test report
Finished copper inside
Finished copper outside

Production requirements
PCB-Type
Finished PCB Dimension (mm)
Create Panel
Panel Dimension (mm)
Contour processing
Add tooling holes in panel
Inner Thieving Balaning Allowed
Outer Thieving Balancing Allowed
Gold Fingers
Edge contact
Soldermask Product

Soldermask Color (Top & Bottom ) | Renesas Blue CMYK(73,73,0,38 RGB (42,40,157)

Base Material | FR 4

must be free from solder. No changes are to made without approval from Renesas. This

includes the addition of circuit fiducials but excludes etch compensation.

This PCB is not to be marked with UL Logos but processed in a UL Approved process.

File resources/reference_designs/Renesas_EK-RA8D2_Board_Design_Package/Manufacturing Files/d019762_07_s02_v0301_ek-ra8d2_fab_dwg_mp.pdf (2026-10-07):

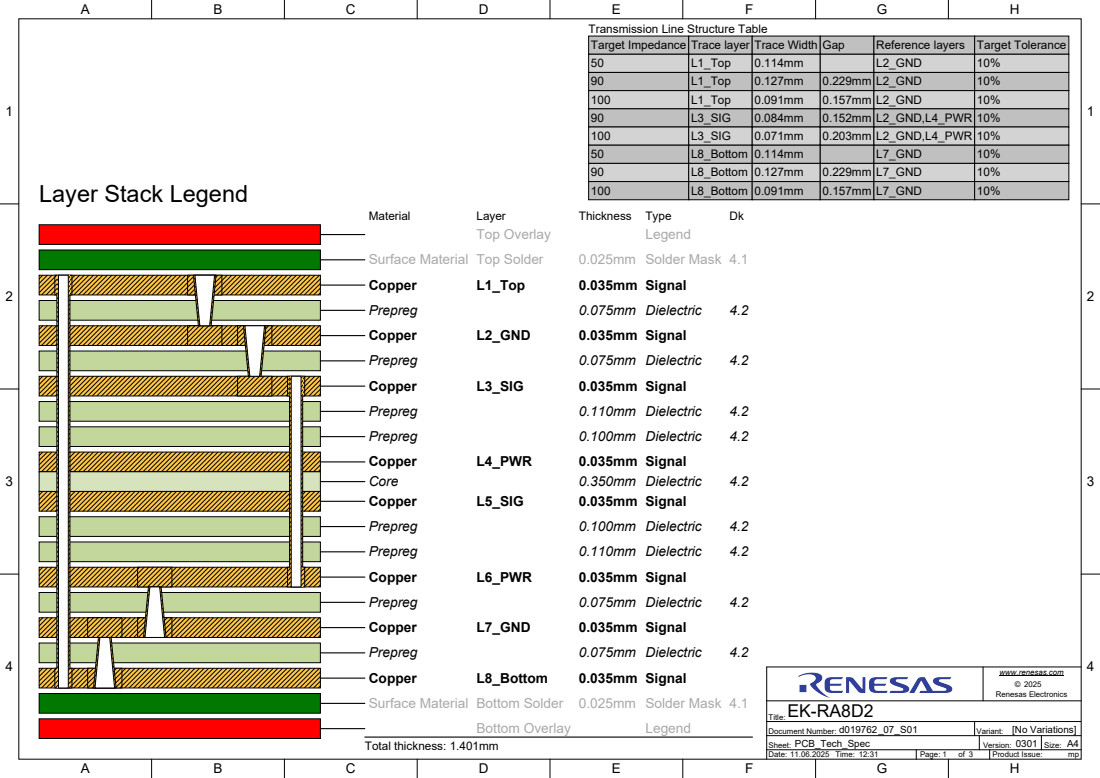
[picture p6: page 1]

Transmission Line Structure Table

Target Impedance | Trace layer | Trace Width | Gap | Reference layers | Target Tolerance
50 | L1_Top | 0.114mm | | L2_GND | 10%
90 | L1_Top | 0.127mm | 0.229mm | L2_GND | 10%
100 | L1_Top | 0.091mm | 0.157mm | L2_GND | 10%
90 | L3_SIG | 0.084mm | 0.152mm | L2_GND,L4_PWR | 10%
100 | L3_SIG | 0.071mm | 0.203mm | L2_GND,L4_PWR | 10%
50 | L8_Bottom | 0.114mm | | L7_GND | 10%
90 | L8_Bottom | 0.127mm | 0.229mm | L7_GND | 10%
100 | L8_Bottom | 0.091mm | 0.157mm | L7_GND | 10%

Surface Material Bottom Solder 0.025mm Solder Mask 4.1

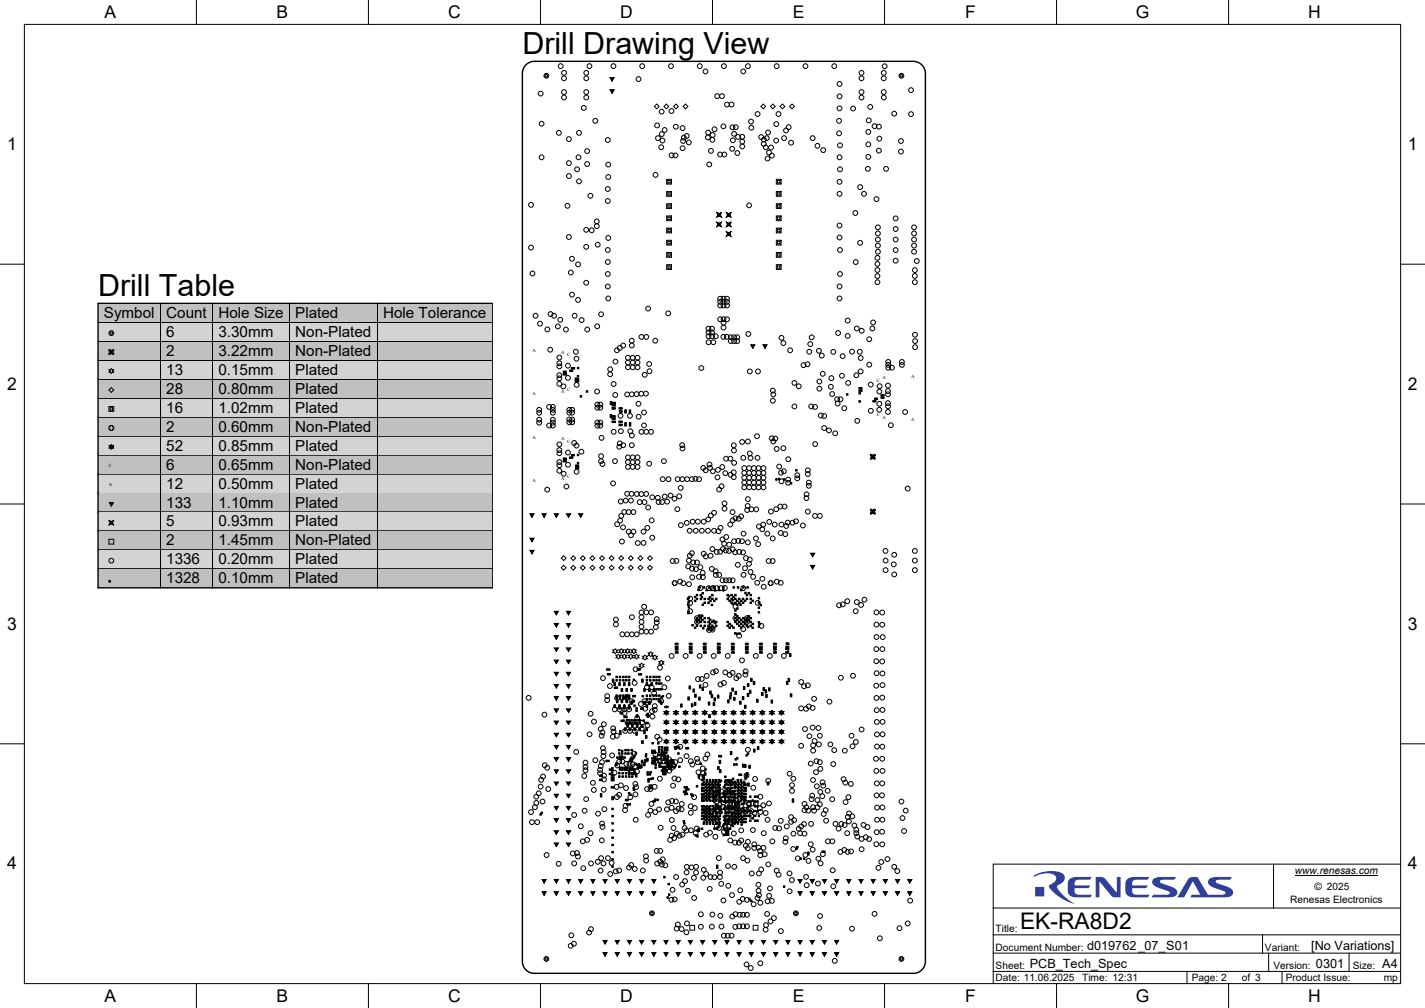
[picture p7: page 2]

Symbol | Count | Hole Size | Plated | Hole Tolerance

6 | 3.30mm | Non-Plated
2 | 3.22mm | Non-Plated
13 | 0.15mm | Plated
28 | 0.80mm | Plated
16 | 1.02mm | Plated
2 | 0.60mm | Non-Plated
52 | 0.85mm | Plated

C | 6 | 0.65mm | Non-Plated

A | 12 | 0.50mm | Plated

133 | 1.10mm | Plated
5 | 0.93mm | Plated
2 | 1.45mm | Non-Plated
1336 | 0.20mm | Plated
1328 | 0.10mm | Plated

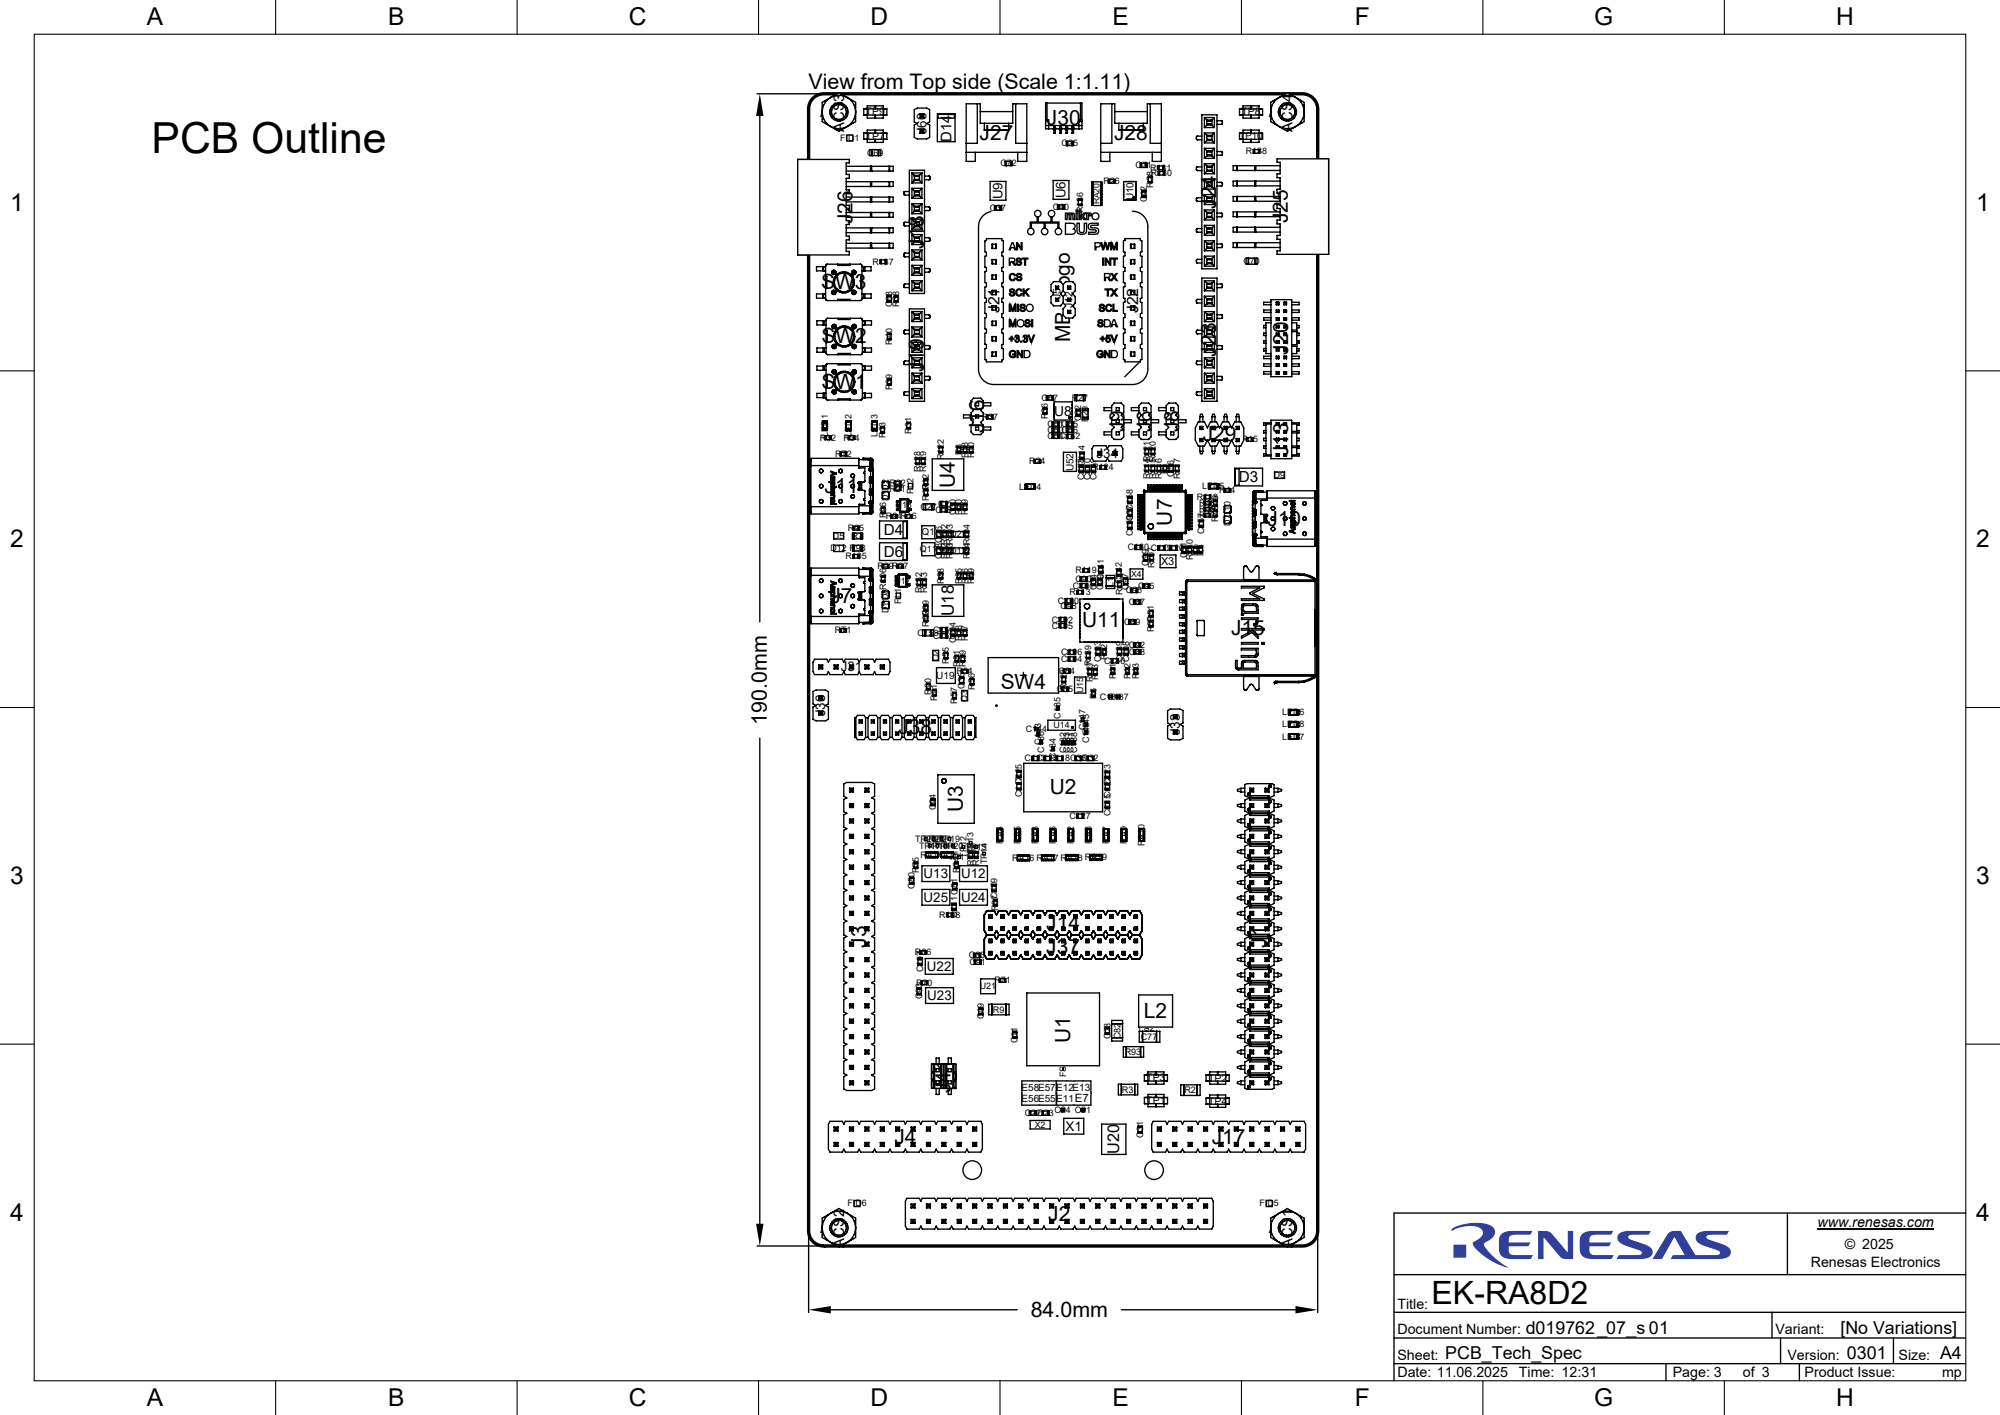
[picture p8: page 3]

View from Top side (Scale 1:1.11)

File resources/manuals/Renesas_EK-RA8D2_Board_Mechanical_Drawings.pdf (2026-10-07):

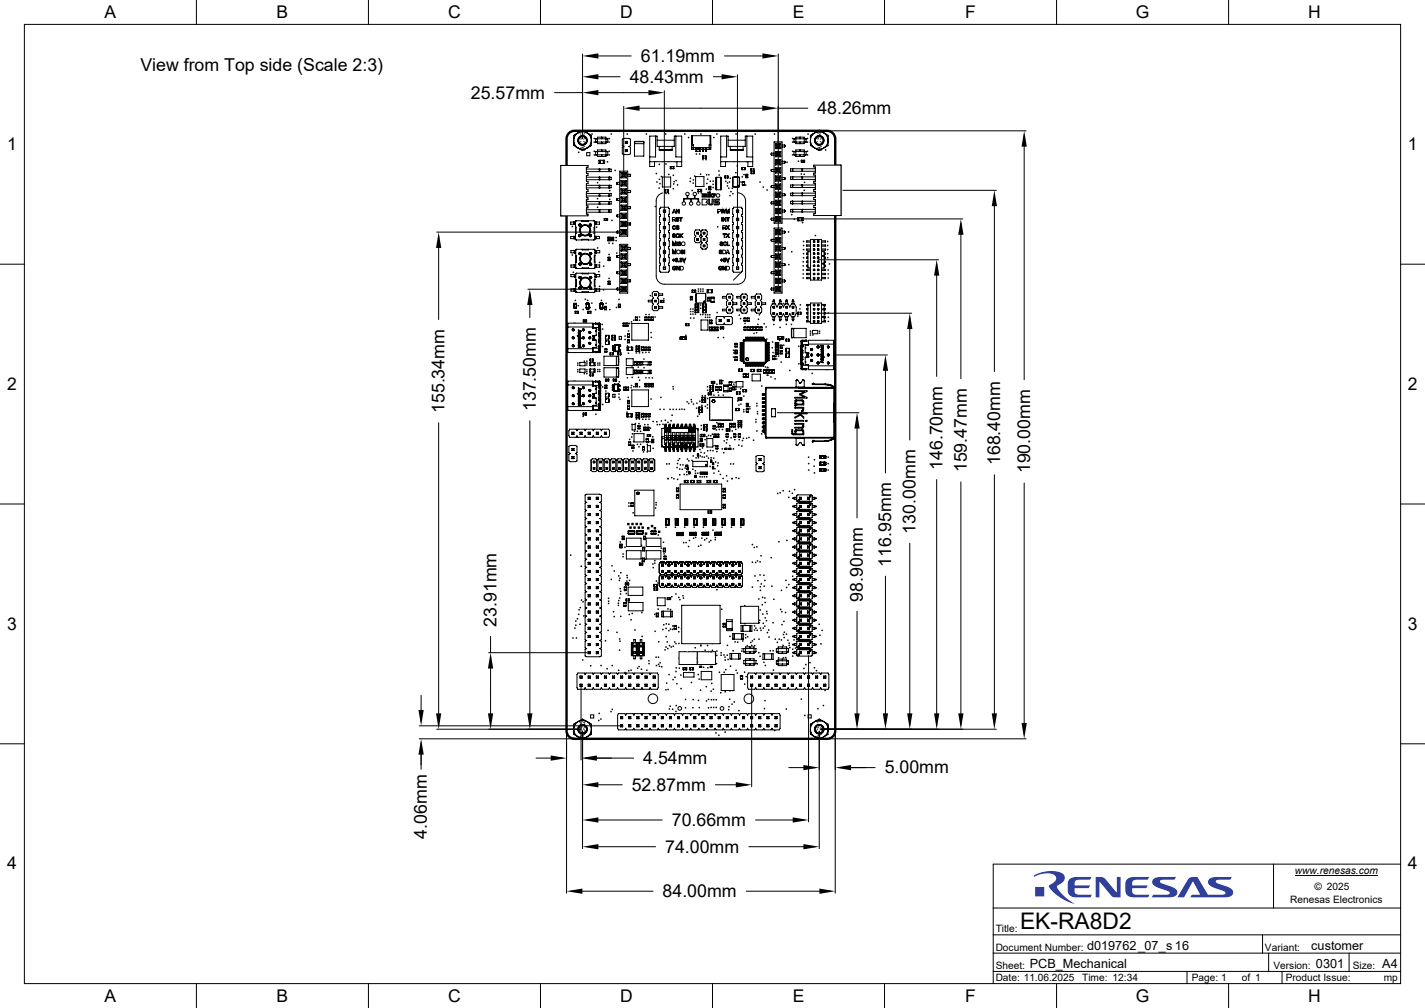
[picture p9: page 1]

View from Top side (Scale 2:3)

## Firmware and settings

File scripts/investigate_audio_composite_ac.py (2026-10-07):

#!/usr/bin/env python3
# SPDX-License-Identifier: MIT
"""Bounded nominal-model investigation; never a hardware qualification gate.

Requires NumPy, an existing ngspice shared library and separately obtained TI
models. No vendor model or code-model binary is redistributed by this script.
Each case runs in an isolated process so a convergence hang becomes UNKNOWN.
"""
import argparse
import ctypes as ct
import hashlib
import itertools
import json
import os
from pathlib import Path
import subprocess
import sys

import numpy as np

MODELS = {
    "opa1656/OPA1656.LIB": "9847ed60c62e792ee6f1c84899278a3c11ce71a6d21804bdd88f51199f1ba055",
    "buf634a/buf634a_a.lib": "63d75a17c849f6ac6fedf332a263505bff9a6b4d079237cfbe34d2ca4ba9a18a",
}
CODE_MODELS = ("analog", "spice2poly", "table", "xtradev", "xtraevt", "digital", "tlines")


def transient_summary(case, time, signals, branches):
    """Metrics for one finite pulse, relative to its measured initial/plateau levels."""
    stop, delay, rise, width, fall = (case[name] for name in
        ("stop_s", "delay_s", "rise_s", "width_s", "fall_s"))
    if (len(time) < 100 or time[0] != 0 or time[-1] < stop * 0.999999
            or not np.all(np.diff(time) > 0)
            or any(len(v) != len(time) or not np.all(np.isfinite(v)) for v in signals.values())):
        raise ValueError("Incomplete, nonfinite or nonmonotonic transient")
    initial = time < delay * 0.8
    plateau = (time > delay + rise + width * 0.8) & (time < delay + rise + width)
    high = (time >= delay + rise) & (time < delay + rise + width)
    recovery = time >= delay + rise + width + fall
    if any(np.count_nonzero(mask) < 10 for mask in (initial, plateau, high, recovery)):
        raise ValueError("Insufficient samples in pulse measurement windows")
    out = signals["out"]
    baseline, level = (float(np.median(out[mask])) for mask in (initial, plateau))
    delta = level - baseline
    if abs(delta) < 1e-6:
        raise ValueError("No resolved output pulse")
    direction = np.sign(delta)
    tolerance = max(1e-5, abs(delta) * 0.001)

    def settled_at(mask, reference, origin):
        selected = np.flatnonzero(mask)
        bad = selected[np.abs(out[selected] - reference) > tolerance]
        if len(bad) and bad[-1] == selected[-1]:
            return None
        return float(time[bad[-1] + 1] - origin) if len(bad) else float(time[selected[0]] - origin)

    currents = np.array([signals[f"vbranch{i}#branch"] for i in range(branches)])
    imbalance = currents - np.mean(currents, axis=0)
    ballast = 1 / sum(1 / (0.22 * (1 + ((-1 if i % 2 == 0 else 1) * 0.01
                        if case.get("component_mismatch") else 0))) for i in range(branches))
    ideal = baseline + case["amplitude_v"] * case.get("load_ohm", 32) / (
        case.get("load_ohm", 32) + ballast)
    sample = np.unique(np.r_[np.arange(0, len(time), max(1, len(time) // 800)), len(time) - 1])
    return {"baseline_v": baseline, "measured_plateau_v": level, "ideal_plateau_v": ideal,
            "plateau_error_v": level - ideal,
            "overshoot_percent": float(max(0, np.max(direction * (out[high] - level))) /
                                       abs(delta) * 100),
            "settling_tolerance_v": tolerance,
            "settling_after_input_rise_s": settled_at(high, level, delay + rise),
            "recovery_after_input_fall_s": settled_at(recovery, baseline, delay + rise + width + fall),
            "final_error_from_baseline_v": float(out[-1] - baseline),
            "maximum_branch_current_a": np.max(abs(currents), axis=1).tolist(),
            "maximum_branch_imbalance_a": np.max(abs(imbalance), axis=1).tolist(),
            "peak_output_abs_v": float(max(abs(out))),
            "sampled_time_s": time[sample].tolist(),
            "sampled_signals": {k: v[sample].tolist() for k, v in signals.items()}}


def worker(args, case):
    logs = []
    if args.diagnostic_log:
        args.diagnostic_log.write_text("", encoding="utf-8")
    callback_type = ct.CFUNCTYPE(ct.c_int, ct.c_char_p, ct.c_int, ct.c_void_p)
    exit_type = ct.CFUNCTYPE(ct.c_int, ct.c_int, ct.c_bool, ct.c_bool, ct.c_int, ct.c_void_p)

    @callback_type
    def output(message, _ident, _user):
        logs.append(message.decode(errors="replace"))
        if args.diagnostic_log:
            with args.diagnostic_log.open("a", encoding="utf-8") as stream:
                stream.write(logs[-1] + "\n")
        return 0

    @exit_type
    def controlled_exit(status, _immediate, _quit, _ident, _user):
        logs.append(f"controlled_exit={status}")
        return 0

    class Complex(ct.Structure):
        _fields_ = [("real", ct.c_double), ("imag", ct.c_double)]

    class Vector(ct.Structure):
        _fields_ = [("name", ct.c_char_p), ("type", ct.c_int), ("flags", ct.c_short),
                   ("real", ct.POINTER(ct.c_double)), ("complex", ct.POINTER(Complex)),
                   ("length", ct.c_int)]

    # Retain the directory handle while the DLL is loaded (Windows dependency resolution).
    dll_directory = os.add_dll_directory(str(args.library.parent)) if os.name == "nt" else None
    lib = ct.CDLL(str(args.library))
    lib.ngSpice_Init.argtypes = [ct.c_void_p] * 7
    lib.ngSpice_Command.argtypes = [ct.c_char_p]
    lib.ngSpice_Circ.argtypes = [ct.POINTER(ct.c_char_p)]
    lib.ngGet_Vec_Info.argtypes = [ct.c_char_p]
    lib.ngGet_Vec_Info.restype = ct.POINTER(Vector)
    if lib.ngSpice_Init(output, None, controlled_exit, None, None, None, None):
        raise RuntimeError("ngSpice_Init failed")

    def command(value):
        if lib.ngSpice_Command(value.encode()):
            raise RuntimeError(f"Command failed: {value}; {logs[-20:]}")

    def vector(name):
        pointer = lib.ngGet_Vec_Info(name.encode())
        if not pointer or pointer.contents.length <= 0:
            raise RuntimeError(f"Missing vector {name}; {logs[-20:]}")
        v = pointer.contents
        values = np.array([complex(v.complex[i].real, v.complex[i].imag)
                           for i in range(v.length)]) if v.complex else np.array(
                               [v.real[i] for i in range(v.length)])
        if not np.all(np.isfinite(values)):
            raise RuntimeError(f"Nonfinite vector {name}")
        return values

    for model in CODE_MODELS:
        path = (args.code_models / (model + ".cm")).as_posix()
        if any(char.isspace() for char in path):
            raise ValueError("Use a whitespace-free code-model directory for ngspice commands")
        command("codemodel " + path)
    command("set ngbehavior=ps")
    command("version")
    version_log = list(logs)
    if isinstance(case, list):
        case = dict(zip(("capacitance_f", "gmin", "mode"), case))
    cap, gmin, mode = (case[name] for name in ("capacitance_f", "gmin", "mode"))
    branches = case.get("branches", 1)
    rf, cf = case.get("feedback_r_ohm", 0), case.get("feedback_c_f", 0)
    load, rail = case.get("load_ohm", 32), case.get("rail_v", 12)
    mismatch = case.get("component_mismatch", False)
    seed = case.get("nodeset", False)
    if mode not in ("loop", "closed", "matrix", "transient") or branches not in (1, 4):
        raise ValueError("Supported cases: closed/loop/matrix/transient, one/four branches")
    if mode == "matrix" and (branches != 4 or case.get("injection_index") not in range(4)):
        raise ValueError("Matrix cases require four branches and injection_index 0..3")
    if bool(rf) != bool(cf):
        raise ValueError("Local feedback investigation requires both Rf and Cf")
    body = [f".options keepopinfo gmin={gmin} rshunt=1e12 itl1=500",
            f"Vin inp 0 dc 0 ac {1 if mode == 'closed' else 0}"]
    analysis = ".ac dec 200 10 1e9"
    if mode == "transient":
        amplitude, delay, rise, width, fall, stop, step = (case[name] for name in
            ("amplitude_v", "delay_s", "rise_s", "width_s", "fall_s", "stop_s", "max_step_s"))
        method = case.get("method", "trap")
        if (not all(np.isfinite(v) for v in (amplitude, delay, rise, width, fall, stop, step))
                or min(delay, rise, width, fall, step) <= 0 or amplitude == 0
                or stop <= delay + rise + width + fall or method not in ("trap", "gear")):
            raise ValueError("Invalid finite-pulse parameters")
        # OPA1656 SBOS901C p4: input absolute limits V- - 0.5 to V+ + 0.5.
        # Intentional common-mode overload is distinct from electrical overstress.
        if abs(amplitude) > rail + 0.5:
            raise ValueError("Command exceeds OPA1656 absolute input voltage limit; invalid recovery test")
        body[0] += f" method={method} reltol=1e-4"
        body[1] = f"Vin inp 0 dc 0 pulse(0 {amplitude} {delay} {rise} {fall} {width} {2*stop})"
        analysis = f".tran {step} {stop} 0 {step}"
    for index in range(branches):
        sense, drive, feedback = (f"{name}{index}" for name in ("sense", "drive", "fbnet"))
        injected = mode == "matrix" or (mode == "loop" and index == 0)
        inverse = f"fb{index}" if injected else feedback
        if injected:
            ac = 1 if index == case.get("injection_index", 0) else 0
            body += [f"Vtest{index} {inverse} {feedback} dc 0 ac {ac}"]
        direction = (-1 if index % 2 == 0 else 1) if mismatch else 0
        if rf:
            body += [f"Rf{index} {sense} {feedback} {rf * (1 + direction * 0.01):.12g}",
                     f"Cf{index} {drive} {feedback} {cf * (1 + direction * 0.05):.12g}"]
        else:
            body += [f"Vfeedback{index} {sense} {feedback} 0"]
        body += [f"Xop{index} inp {inverse} vp vn {drive} OPA1656",
                 f"Xbuf{index} {drive} {sense} vp vn BUF634A",
                 f"Vbranch{index} {sense} branch{index} 0",
                 f"Rb{index} branch{index} out {0.22 * (1 + direction * 0.01):.12g}"]
        if seed:
            body += [f".nodeset v({drive})=-0.2 v({sense})=0.00049 "
                     f"v({feedback})=0.00049" +
                     (f" v({inverse})=0.00049" if injected else "")]
    body += [f"Rload out 0 {load}"]
    if cap:
        body += [f"Cl out 0 {cap}"]
    lines = ["OPA1656 BUF634A own-output unity cell: nominal investigation",
             *[f'.include "{(args.models / path).as_posix()}"' for path in MODELS],
             f"Vp vp 0 {rail}", f"Vn vn 0 {-rail}", *body, analysis, ".end"]
    circuit = (ct.c_char_p * (len(lines) + 1))(*[line.encode() for line in lines], None)
    if lib.ngSpice_Circ(circuit):
        raise RuntimeError(f"Circuit load failed: {logs[-20:]}")
    command("run")
    errors = [line for line in logs if any(word in line.lower() for word in
              ("error", "controlled_exit=", "simulation(s) aborted", "timestep too small"))]
    if errors:
        raise RuntimeError(str(errors))
    if mode == "transient":
        names = ["inp", "out", "vp#branch", "vn#branch"] + [
            f"{name}{i}" for i in range(branches) for name in ("drive", "sense", "fbnet")]
        names += [f"vbranch{i}#branch" for i in range(branches)]
        return {"case": case, "mode": mode,
                "transient": transient_summary(case, vector("time").real,
                    {name: vector(name).real for name in names}, branches),
                "netlist": lines, "runtime_log": version_log,
                "warnings": [line for line in logs if "warning" in line.lower()],
                "solver_log": [line for line in logs if any(word in line.lower() for word in
                    ("linear solver", "stepping", "op finished", "data rows"))]}
    # KEEPOPINFO retains the actual AC bias solution. A separate .op could
    # converge to another root and must not be reported as the AC bias point.
    op_names = ["out", "vp#branch", "vn#branch"] + [
        f"{name}{index}" for index in range(branches)
        for name in ("drive", "sense", "fbnet")]
    op = {name: vector("op1." + name).real.tolist() for name in op_names}
    f = vector("frequency").real
    h = -vector("fbnet0") / vector("fb0") if mode == "loop" else vector("out")
    if (len(f) != len(h) or len(f) != 1601 or not np.all(np.diff(f) > 0)
            or not np.all(np.isfinite(h)) or not np.all(abs(h) > 0)):
        raise RuntimeError("Incomplete or nonmonotonic AC sweep")
    db = 20 * np.log10(np.abs(h))
    phase = np.unwrap(np.angle(h)) * 180 / np.pi
    crossings = []
    if mode == "loop":
        for i in np.where((db[:-1] >= 0) & (db[1:] < 0))[0]:
            fraction = -db[i] / (db[i + 1] - db[i])
            crossings.append({"frequency_hz": float(10 ** (np.log10(f[i]) + fraction *
                              np.log10(f[i + 1] / f[i]))),
                              "phase_margin_deg": float(180 + phase[i] + fraction *
                                                        (phase[i + 1] - phase[i]))})
    audio_index = int(np.argmin(abs(f - 20000)))
    currents = [vector(f"vbranch{index}#branch")[audio_index] for index in range(branches)]
    imbalance = [current - sum(currents) / branches for current in currents]
    result = {"case": case, "capacitance_f": cap, "gmin": gmin, "mode": mode, "operating_point": op,
            "gain_at_10hz": float(abs(h[0])), "peak_db": float(max(db)),
            "gain_at_20khz": float(abs(h[audio_index])),
            "phase_at_20khz_deg": float(phase[audio_index]),
            "peak_frequency_hz": float(f[int(np.argmax(db))]),
            "branch_20khz_a_per_v": [[float(v.real), float(v.imag)] for v in currents],
            "imbalance_20khz_a_per_v": [float(abs(v)) for v in imbalance],
            "downward_crossings": crossings, "netlist": lines,
            "warnings": [line for line in logs if "warning" in line.lower()],
            "runtime_log": version_log}
    if mode == "matrix":
        # A column excitation is not a scalar loop gain, nor a playback input.
        # Publish only its matrix data and actual bias point, not spurious
        # scalar margins (unexcited closed ports have fbnet/fb == 1).
        for key in ("gain_at_10hz", "peak_db", "gain_at_20khz", "phase_at_20khz_deg",
                    "peak_frequency_hz", "branch_20khz_a_per_v",
                    "imbalance_20khz_a_per_v", "downward_crossings"):
            del result[key]
        result["matrix_vectors"] = {
            "frequency": f.tolist(),
            "input": [[[float(v.real), float(v.imag)] for v in vector(f"fb{i}")]
                      for i in range(branches)],
            "returned": [[[float(v.real), float(v.imag)] for v in vector(f"fbnet{i}")]
                         for i in range(branches)]}
    return result


def matrix_summary(rows):
    """Return-ratio matrix from simultaneous voltage-port injections.

    B = -L A, where A and B are input and returned-feedback voltage matrices.
    Low input admittance is assumed. This is still a nominal-model screen.
    """
    if len(rows) != 4 or sorted(r["case"]["injection_index"] for r in rows) != list(range(4)):
        raise ValueError("Four complete injection cases required")
    rows = sorted(rows, key=lambda r: r["case"]["injection_index"])
    f = np.array(rows[0]["matrix_vectors"]["frequency"])
    if any(not np.array_equal(f, r["matrix_vectors"]["frequency"]) for r in rows):
        raise ValueError("Matrix sweep frequencies disagree")
    # Linear columns must describe the same bias point, not distinct roots.
    bias_spread = max(np.ptp([r["operating_point"][name][0] for r in rows])
                      for name in rows[0]["operating_point"] if "#branch" not in name)
    if not np.isfinite(bias_spread) or bias_spread > 1e-6:
        raise ValueError("Matrix columns disagree in AC bias; review convergence")
    def unpack(name):
        values = np.array([r["matrix_vectors"][name] for r in rows])
        # columns are excitation sources; rows are feedback ports.
        return (values[..., 0] + 1j * values[..., 1]).transpose(2, 1, 0)
    a, b = unpack("input"), unpack("returned")
    condition = np.linalg.cond(a)
    if not np.all(np.isfinite(condition)) or max(condition) > 1e9:
        raise ValueError("Ill-conditioned input-voltage matrix; no trustworthy loop result")
    loops = -np.matmul(b, np.linalg.inv(a))
    eigen = np.linalg.eigvals(loops)
    # Track modes by nearest complex value in log frequency; degenerate modes
    # are exchangeable. Archive sampled traces so the tracking can be reviewed.
    permutations = list(itertools.permutations(range(4)))
    for i in range(1, len(f)):
        order = min(permutations, key=lambda p: float(np.sum(abs(eigen[i, p] - eigen[i - 1]))))
        eigen[i] = eigen[i, order]
    if not np.all(np.isfinite(eigen)) or not np.all(abs(eigen) > 0):
        raise ValueError("Invalid return-ratio eigenvalues")
    db = 20 * np.log10(abs(eigen))
    phase = np.unwrap(np.angle(eigen), axis=0) * 180 / np.pi
    # Normalize low-frequency negative-feedback modes around zero degrees.
    phase -= np.round(phase[0] / 360) * 360
    crossings = []
    for mode in range(4):
        for i in np.where((db[:-1, mode] >= 0) & (db[1:, mode] < 0))[0]:
            x = -db[i, mode] / (db[i + 1, mode] - db[i, mode])
            crossings.append({"mode": mode, "frequency_hz": float(10 ** (np.log10(f[i]) + x *
                              np.log10(f[i + 1] / f[i]))), "phase_margin_deg": float(180 +
                              phase[i, mode] + x * (phase[i + 1, mode] - phase[i, mode]))})
    sample = np.arange(0, len(f), 40)
    return {"case": {k: v for k, v in rows[0]["case"].items() if k != "injection_index"},
            "maximum_voltage_bias_spread_v": float(bias_spread),
            "maximum_matrix_condition": float(max(condition)), "downward_crossings": crossings,
            "sampled_frequency_hz": f[sample].tolist(), "sampled_mode_db": db[sample].tolist(),
            "sampled_mode_phase_deg": phase[sample].tolist()}
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

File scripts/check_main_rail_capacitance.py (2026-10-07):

"""Inventory saved KiCad XML capacitance; nominal values, not qualification.

Usage: python scripts/check_main_rail_capacitance.py <exported-netlist.xml>
Export with kicad-cli sch export netlist --format kicadxml. No CAD writes.
See design/main_rail_capacitance.md for scope and unresolved paths.
"""

import argparse
from collections import defaultdict
from decimal import Decimal
from math import log
import re
import xml.etree.ElementTree as ET


def capacitance(value):
    # KiCad value fields may append a slash-separated voltage rating.
    # Parse only the nominal capacitance; reject other attached syntax.
    match = re.fullmatch(
        r"(\d+(?:\.\d+)?)\s*([pnum])(?:F)?(?:\s+.*|/\d+(?:\.\d+)?V)?", value)
    if not match:
        raise ValueError(f"Unrecognized capacitance value: {value!r}")
    factors = {"p": "1e-12", "n": "1e-9", "u": "1e-6", "m": "1e-3"}
    return Decimal(match[1]) * Decimal(factors[match[2]])


def inventory(path):
    root = ET.parse(path).getroot()
    components = {c.attrib["ref"]: c for c in root.findall("./components/comp")}
    if len(components) != len(root.findall("./components/comp")):
        raise ValueError("Duplicate component references")
    pins = defaultdict(dict)
    for net in root.findall("./nets/net"):
        for node in net.findall("node"):
            ref, pin = node.attrib["ref"], node.attrib["pin"]
            if pin in pins[ref]:
                raise ValueError(f"Duplicate node {ref}.{pin}")
            pins[ref][pin] = net.attrib["name"]

    rail_caps = defaultdict(list)
    for ref, comp in components.items():
        if not re.fullmatch(r"C\d+", ref):
            continue
        cap = capacitance(comp.findtext("value", ""))
        connected = list(pins[ref].values())
        if len(connected) != 2:
            raise ValueError(f"Capacitor {ref} does not have two exported pads")
        if "GND" in connected:
            other = connected.copy()
            other.remove("GND")
            mpn = comp.findtext('./fields/field[@name="Manufacturer_Part_Number"]')
            rail_caps[other[0]].append((ref, cap, mpn or "UNSPECIFIED"))

    # Fail visibly if the known ferrite topology changes; do not silently
    # treat an arbitrary similarly named net as direct main-rail storage.
    assert pins["FB1"] == {"1": "+3V3_MCU", "2": "+3V3_USBHS_A"}
    totals = {}
    for rail in ("+3V3_MCU", "+3V3_USBHS_A", "+3V3_RADIO", "VDD_SD",
                 "+1V8_MIPI", "/RA8P1 internal core regulator/MCU_VCORE",
                 "AON_HOLD", "SYS_AON"):
        if rail not in rail_caps:
            raise ValueError(f"Expected rail missing from inventory: {rail}")
        groups = defaultdict(list)
        for ref, cap, mpn in rail_caps[rail]:
            groups[(cap, mpn)].append(ref)
        total = sum((c for _, c, _ in rail_caps[rail]), Decimal(0))
        totals[rail] = total
        print(f"\n{rail}: {len(rail_caps[rail])} capacitors, {total * 1_000_000:f} uF nominal")
        for (cap, mpn), refs in sorted(groups.items()):
            refs.sort(key=lambda ref: int(ref[1:]))
            print(f"  {','.join(refs)}: {len(refs)} x {cap * 1_000_000:f} uF; {mpn}")

    key_total = Decimal(0)
    for resistor in ("R27", "R28", "R29", "R30"):
        nets = list(pins[resistor].values())
        assert len(nets) == 2 and "+3V3_MCU" in nets
        nets.remove("+3V3_MCU")
        caps = rail_caps[nets[0]]
        assert caps, f"No filter capacitance behind {resistor}"
        key_total += sum((c for _, c, _ in caps), Decimal(0))
    passive = totals["+3V3_MCU"] + totals["+3V3_USBHS_A"]
    print(f"\nMain plus FB1 branch: {passive * 1_000_000:f} uF nominal")
    # These switches are not unconditional reverse isolation during collapse.
    # Inventory their storage without pretending to model transient conduction.
    for ref, expected in {
        "U4": {"A2": "+3V3_MCU", "B2": "+3V3_MCU",
               "A1": "+3V3_RADIO", "B1": "+3V3_RADIO"},
        "U17": {"2": "+3V3_MCU", "5": "VDD_SD"},
    }.items():
        for pin, rail in expected.items():
            if pins[ref].get(pin) != rail:
                raise ValueError(f"Changed switched-storage path: {ref}.{pin}")
    switch_storage = totals["+3V3_RADIO"] + totals["VDD_SD"]
    print(f"Radio plus SD output storage: {switch_storage * 1_000_000:f} uF nominal")
    print(f"Main/FB1/radio/SD stored-capacitance subtotal: {(passive + switch_storage) * 1_000_000:f} uF nominal")
    print("This subtotal is not an equivalent discharge capacitance or an isolation guarantee.")
    # RADIO-022: calculate from this export rather than a cached capacitor sum.
    # TI SLVSBS6A: typical 10%-90% rise at VIN=3.3V/25C, CIN=1uF,
    # COUT=0.1uF and ROUT=10ohm. Not a guaranteed board waveform.
    radio_cap = float(totals["+3V3_RADIO"])
    print(f"Radio nominal-cap linear slew screen: {radio_cap * 0.8 * 3.3 / 715e-6 * 1e3:.6f} mA")
    for resistance in (273, 325):
        print(f"Radio ideal QOD 90%-10% RC screen at {resistance}ohm: {resistance * radio_cap * log(9) * 1e3:.6f} ms")
    print("QOD resistance table conditions: ON=0, IOUT=2mA.")
    print("These screens exclude module storage and do not establish startup/off-time.")
    print(f"Four resistor-fed key filters: {key_total * 1_000_000:f} uF nominal (separate RC tails)")
    print("NOT QUALIFIED: 1mF effective ceiling, external module capacitance,")
    print("switched/regulator reverse paths, component service bounds and board parasitics.")


if __name__ == "__main__":
    parser = argparse.ArgumentParser(description=__doc__)
    parser.add_argument("netlist", help="Fresh saved-project KiCad XML netlist")
    inventory(parser.parse_args().netlist)
